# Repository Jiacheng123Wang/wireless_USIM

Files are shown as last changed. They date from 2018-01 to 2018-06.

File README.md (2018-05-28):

# wireless_USIM
Wireless USIM interface software &amp; hardware. The basic functionality is to implement USIM sharing between multiple cellular devices by wireless interface. Especially between smart phone and watch. For more information, refer doc/Wireless_SIM_Interface.pptx.

Based on nRF52832-CIAA Multi-protocol 2.4GHz SoC.

nRF-SDK 14.2.0 required, download from https://developer.nordicsemi.com/nRF5_SDK/nRF5_SDK_v14.x.x/

Toolchain gcc-arm-none-eabi-5_4-2016q3 used, download from https://launchpad.net/gcc-arm-embedded/+download

Hardware PCB is generated by DesignSpark 8.1, download from https://www.rs-online.com/designspark/pcb-software

Smart SIM connector 3D IGS is generated from rsdoc file by DesignSpark Mechanical 2.0, download from https://www.rs-online.com/designspark/mechanical-software

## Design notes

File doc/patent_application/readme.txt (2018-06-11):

The patent application documents just for better understanding the background of wireless USIM interface.

The patent process has been quit for all applications.

All the patent documents are open technology.

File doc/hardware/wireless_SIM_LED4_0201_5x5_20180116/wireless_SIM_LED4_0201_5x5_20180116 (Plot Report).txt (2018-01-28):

Plot Report
-----------

Report Written:     Tuesday, January 16, 2018
Design Path:        \\Mac\Home\Desktop\PCB\wireless_SIM_LED4_0201_5x5_20180116.pcb
Design Title:       
Created:            2015/5/19 15:26:34
Last Saved:         2018/1/16 21:34:01
Editing Time:       20650 min
Units:              mm (precision 4)

Device Settings
===============

Gerber Settings
===============

    Leading zero suppression.
    G01 assumed throughout.
    Line termination <*> <CR> <LF>.
    3.5 format absolute inches.

    Format commands defined in Gerber file.
    Aperture table defined in Gerber file.
    Hardware arcs allowed.

Drill Settings
==============

    Excellon Format 1    Format 3.5 absolute in mm.
    No zero suppression.

Plots Output
============

Gerber Output
=============

\\Mac\Home\Desktop\PCB\wireless_SIM_LED4_0201_5x5_20180116 - Top Documentation.gbr

    Layers:
    ---------------------
    Top Documentation
    Board Outlines

    D-Code Shape  (thou)
    -----------------------
    D10    Round 0.39
    D11    Round 0.04
    D12    Round 1.57
    D14    Round 0.79

Gerber Output
=============

\\Mac\Home\Desktop\PCB\wireless_SIM_LED4_0201_5x5_20180116 - Top Silkscreen.gbr

    Layers:
    ------------------
    Top Silkscreen
    Board Outlines

    D-Code Shape  (thou)
    -----------------------
    D11    Round 0.04
    D12    Round 1.57
    D13    Round 1.18
    D14    Round 0.79

Gerber Output
=============

\\Mac\Home\Desktop\PCB\wireless_SIM_LED4_0201_5x5_20180116 - Top Copper.gbr

    Layers:
    ------------------
    Top Copper
    Board Outlines

    D-Code Shape  (thou)
    --------------------------------------------------------------
    D11    Round 0.04
    D14    Round 0.79
    D16    Round 78.74
    D18    Round 39.37
    D70    Round 19.69
    D71    Square 11.81
    D21    Round 8.66
    D23    Round 15.75
    D24    Round 5.91
    D25    Round 7.87
    D93    Round 3.94
    D96    Square 19.69
    D100   Round 27.56
    D113   Round 47.24
    D115   Round 11.81
    D116   Round 2.36
    D120   Rounded Rectangle 39.37 X 62.99 X 15.75  Rotation 90
    D123   Rectangle 51.18 X 62.99
    D126   Rounded Rectangle 39.37 X 70.87 X 15.75  Rotation 90

Gerber Output
=============

\\Mac\Home\Desktop\PCB\wireless_SIM_LED4_0201_5x5_20180116 - Top Copper (Resist).gbr

    Layers:
    ------------------
    Top Copper
    Board Outlines

    D-Code Shape  (thou)
    --------------------------------------------------------------
    D11    Round 0.04
    D14    Round 0.79
    D26    Round 88.74
    D28    Round 49.37
    D72    Round 29.69
    D73    Square 21.81
    D75    Round 18.66
    D101   Square 29.69
    D121   Rounded Rectangle 39.37 X 62.99 X 15.75  Rotation 90
    D124   Rectangle 61.18 X 72.99
    D127   Rounded Rectangle 39.37 X 70.87 X 15.75  Rotation 90

Gerber Output
=============

\\Mac\Home\Desktop\PCB\wireless_SIM_LED4_0201_5x5_20180116 - Top Copper (Paste).gbr

    Layers:
    ------------------
    Top Copper
    Board Outlines

    D-Code Shape  (thou)
    --------------------------------------------------------------
    D11    Round 0.04
    D14    Round 0.79
    D77    Round 74.74
    D79    Round 35.37
    D81    Round 15.69
    D82    Square 7.81
    D84    Round 4.66
    D105   Square 15.69
    D122   Rounded Rectangle 39.37 X 62.99 X 15.75  Rotation 90
    D125   Rectangle 47.18 X 58.99
    D128   Rounded Rectangle 39.37 X 70.87 X 15.75  Rotation 90

Gerber Output
=============

\\Mac\Home\Desktop\PCB\wireless_SIM_LED4_0201_5x5_20180116 - Bottom Copper.gbr

    Layers:
    ------------------
    Bottom Copper
    Board Outlines

    D-Code Shape  (thou)
    ---------------------------------------------------------------
    D11    Round 0.04
    D14    Round 0.79
    D23    Round 15.75
    D25    Round 7.87
    D86    Rounded Rectangle 70.87 X 165.35 X 19.69  Rotation 90
    D100   Round 27.56
    D113   Round 47.24
    D115   Round 11.81

Gerber Output
=============

\\Mac\Home\Desktop\PCB\wireless_SIM_LED4_0201_5x5_20180116 - Bottom Copper (Resist).gbr

    Layers:
    ------------------
    Bottom Copper
    Board Outlines

    D-Code Shape  (thou)
    ---------------------------------------------------------------
    D11    Round 0.04
    D14    Round 0.79
    D87    Rounded Rectangle 70.87 X 165.35 X 19.69  Rotation 90

Gerber Output
=============

\\Mac\Home\Desktop\PCB\wireless_SIM_LED4_0201_5x5_20180116 - Bottom Copper (Paste).gbr

    Layers:
    ------------------
    Bottom Copper
    Board Outlines

    D-Code Shape  (thou)
    ---------------------------------------------------------------
    D11    Round 0.04
    D14    Round 0.79
    D88    Rounded Rectangle 70.87 X 165.35 X 19.69  Rotation 90

Gerber Output
=============

\\Mac\Home\Desktop\PCB\wireless_SIM_LED4_0201_5x5_20180116 - Bottom Silkscreen.gbr

    Layers:
    ---------------------
    Bottom Silkscreen
    Board Outlines

    D-Code Shape  (thou)
    -----------------------
    D11    Round 0.04
    D12    Round 1.57
    D14    Round 0.79

Gerber Output
=============

\\Mac\Home\Desktop\PCB\wireless_SIM_LED4_0201_5x5_20180116 - Bottom Documentation.gbr

    Layers:
    ------------------------
    Bottom Documentation
    Board Outlines

    D-Code Shape  (thou)
    -----------------------
    D10    Round 0.39
    D11    Round 0.04
    D12    Round 1.57
    D14    Round 0.79

NC Drill Output
===============

\\Mac\Home\Desktop\PCB\wireless_SIM_LED4_0201_5x5_20180116 - Drill Data - [Through Hole].drl

    Output:
    ---------------------------
    Plated Round Drill Holes
    Plated Slots
    Plated Board Outlines

    Tool  Size         Count   ID
    ------------------------------------
    T001  000.00591 in 10    F
    T002  000.00787 in 1320  A
    T003  000.01969 in 325   D
    T004  000.03937 in 20    E
    ------------------------------------
    Total              1675
    ------------------------------------

\\Mac\Home\Desktop\PCB\wireless_SIM_LED4_0201_5x5_20180116 - Drill Data - [Through Hole] (Unplated).drl

    Output:
    -----------------------------
    Unplated Round Drill Holes
    Unplated Slots
    Unplated Board Outlines

    Tool  Size         Count   ID
    ------------------------------------
    T001  000.02500 in 26
    ------------------------------------
    Total              26
    ------------------------------------

End Of Report.

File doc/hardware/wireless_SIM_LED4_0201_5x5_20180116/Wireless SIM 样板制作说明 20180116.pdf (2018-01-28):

# Wireless SIM 样板制作说明

# 电路板模型示意图

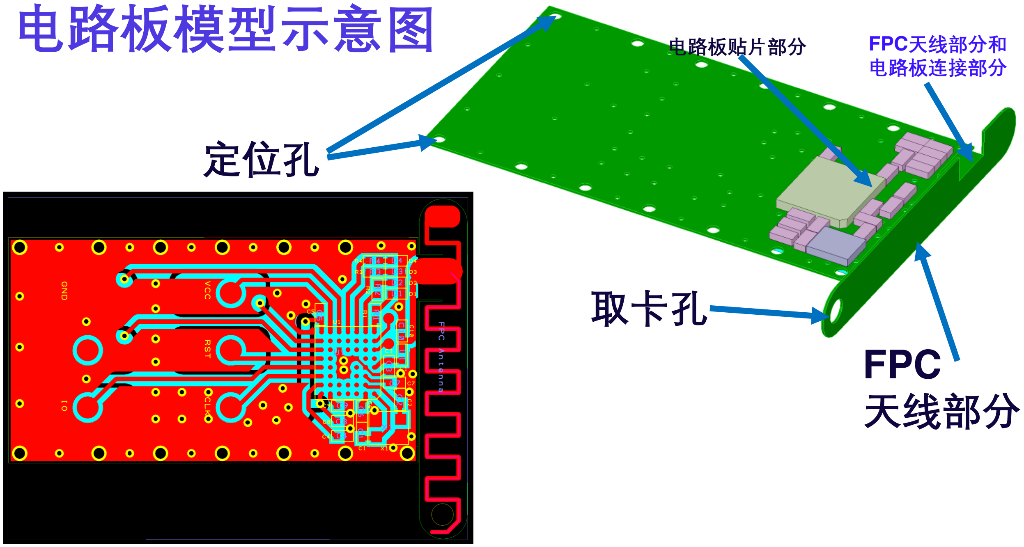
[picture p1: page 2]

### 定位孔

### 取卡孔

### FPC

### 天线部分

FPC天线部分和
电路板连接部分

电路板贴片部分

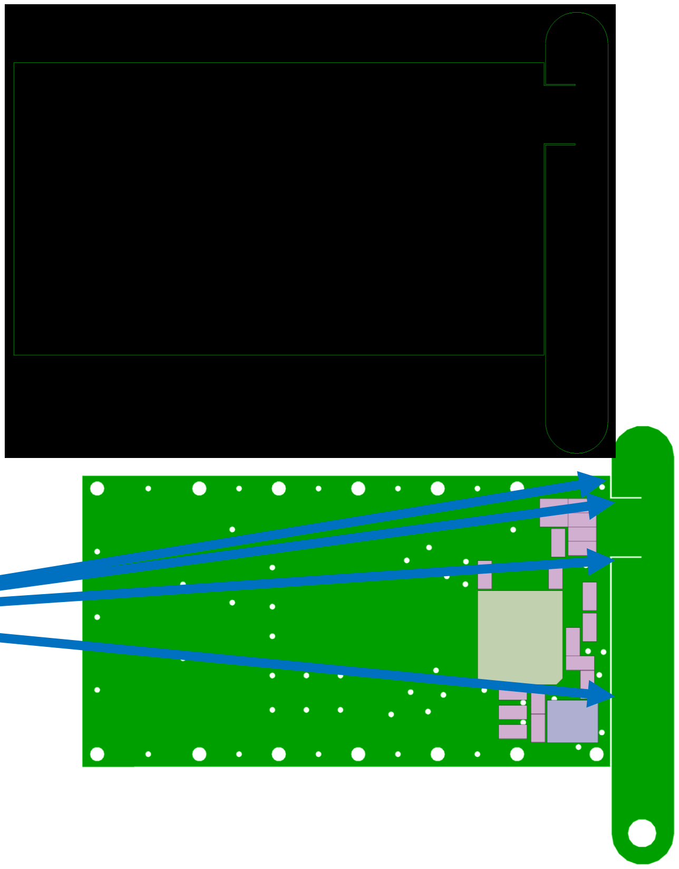
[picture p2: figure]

# FPC天线板切割线(1)

- FPC天线最后需要折叠弯
曲，固定在定制的SIM卡
托上。天线FPC垂直于原
来的电路板，竖直固定
在SIM卡托的外侧
- 在切割FPC板外形的时候，
天线FPC板和主电路板之
间的分离距离是0.05mm，
实际上只需要切割一条线
分开就可以了

# FPC天线板切割线(2)

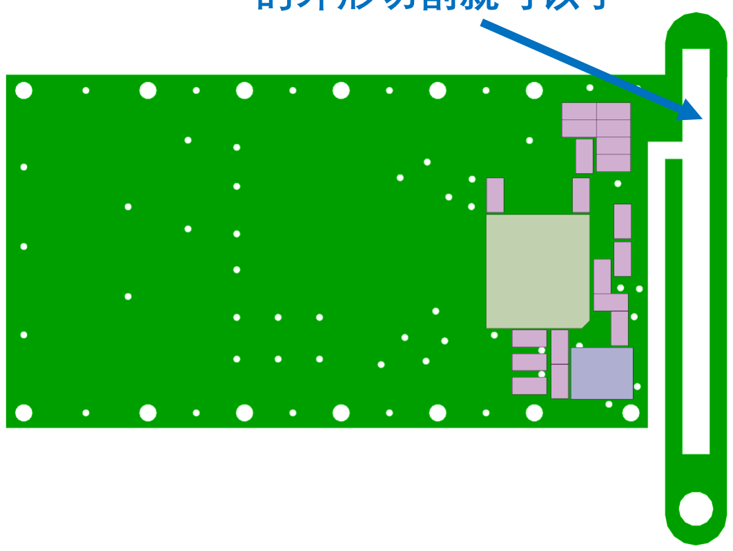
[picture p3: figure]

- 另外一个FPC天线最
后需要折叠弯曲，
固定在定制的SIM卡
托的内侧，按照电
路板的外形切割就
可以了。

FPC天线子板按照电路板
的外形切割就可以了

## FPC天线固定在定制卡托上的效果

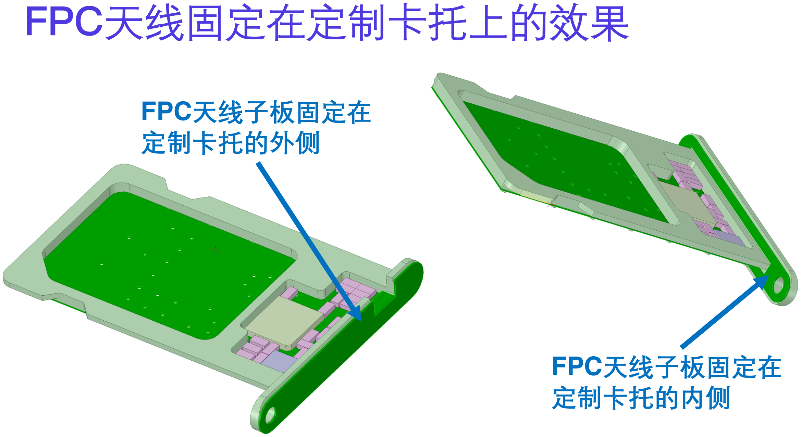
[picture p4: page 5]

FPC天线子板固定在
定制卡托的外侧

FPC天线子板固定在
定制卡托的内侧

## 定位孔

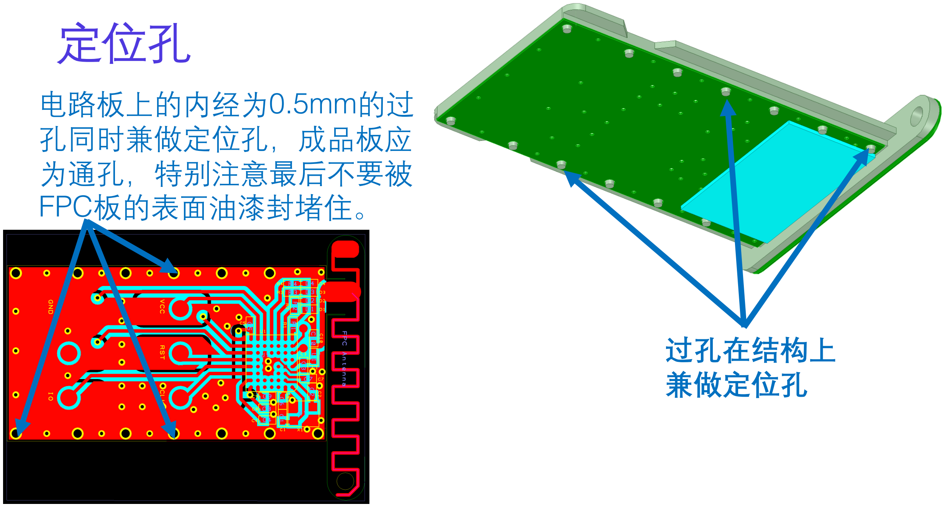
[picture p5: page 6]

电路板上的内经为0.5mm的过
孔同时兼做定位孔，成品板应
为通孔，特别注意最后不要被
FPC板的表面油漆封堵住。

过孔在结构上
兼做定位孔

## 取卡孔

### 取卡孔在成品

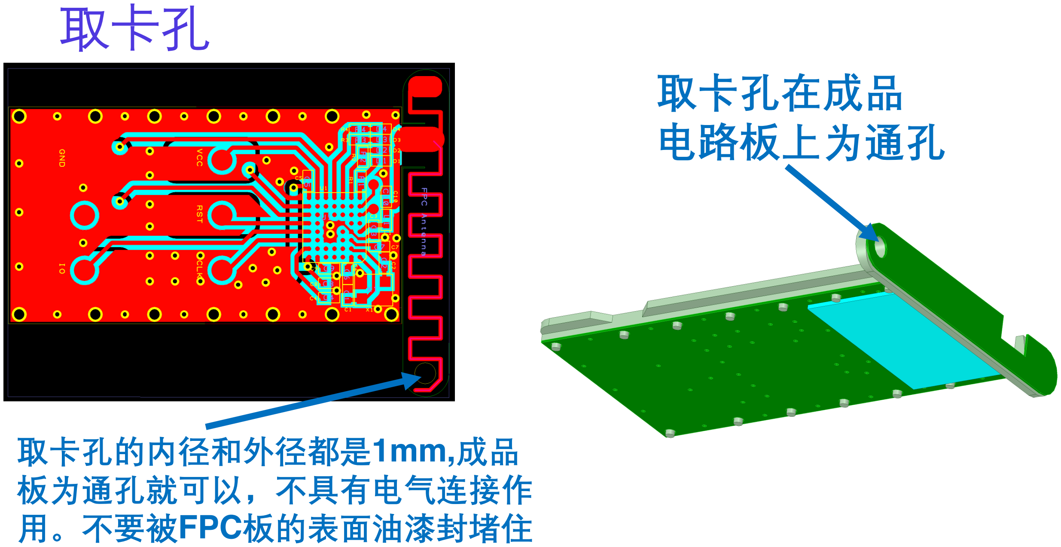
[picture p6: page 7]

取卡孔的内径和外径都是1mm,成品
板为通孔就可以，不具有电气连接作
用。不要被FPC板的表面油漆封堵住

### 电路板上为通孔

## 结构加强板(1)

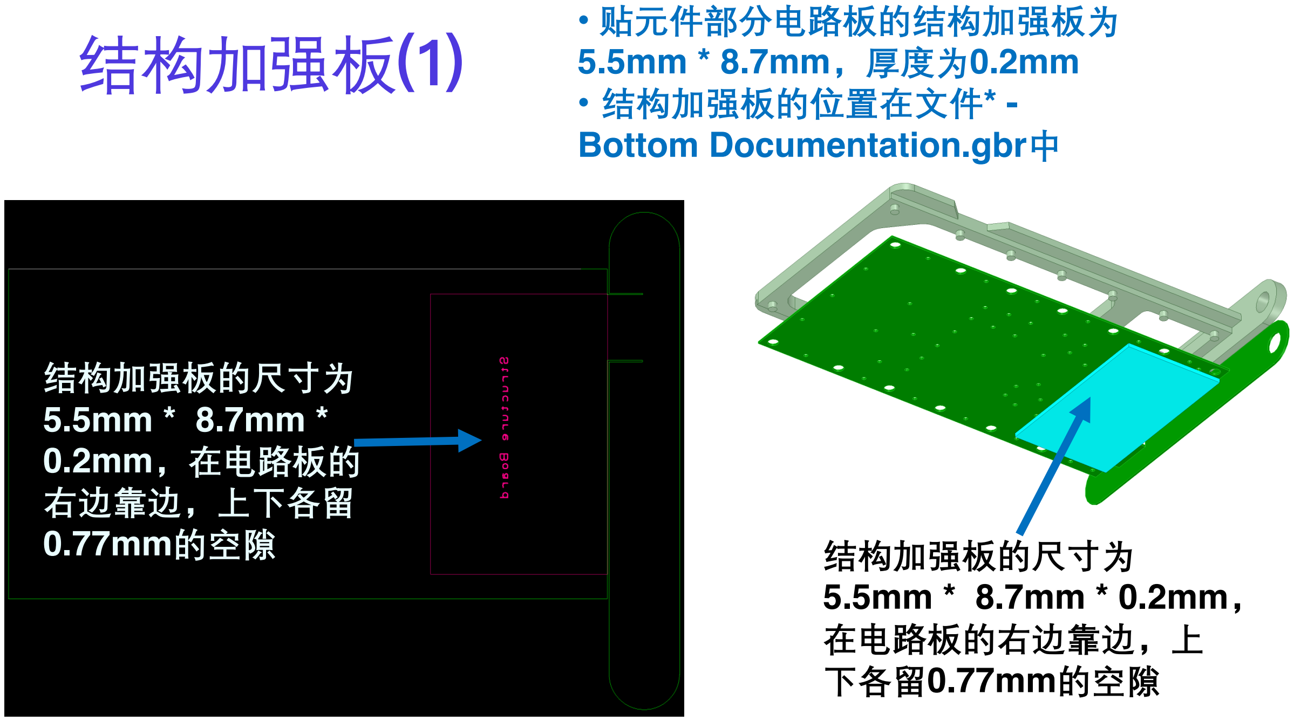
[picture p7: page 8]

- 贴元件部分电路板的结构加强板为
5.5mm * 8.7mm，厚度为0.2mm
- 结构加强板的位置在文件* -
Bottom Documentation.gbr中

结构加强板的尺寸为
5.5mm * 8.7mm *
0.2mm，在电路板的
右边靠边，上下各留
0.77mm的空隙 | 结构加强板的尺寸为
| 5.5mm * 8.7mm * 0.2mm， 在电路板的右边靠边，上
| 下各留0.77mm的空隙

## 结构加强板(2)

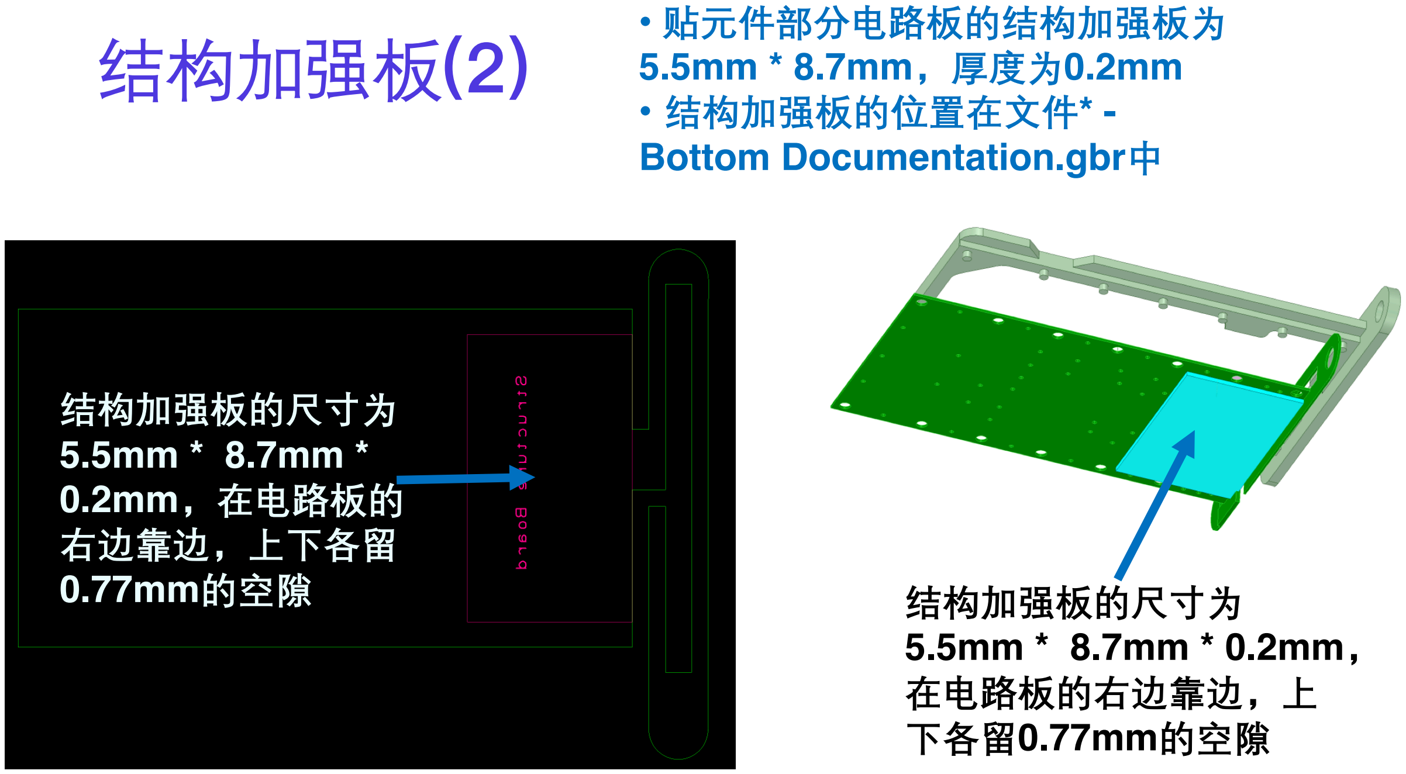
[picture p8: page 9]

- 贴元件部分电路板的结构加强板为
5.5mm * 8.7mm，厚度为0.2mm
- 结构加强板的位置在文件* -
Bottom Documentation.gbr中

结构加强板的尺寸为
5.5mm * 8.7mm *
0.2mm，在电路板的
右边靠边，上下各留
0.77mm的空隙 | 结构加强板的尺寸为
| 5.5mm * 8.7mm * 0.2mm， 在电路板的右边靠边，上
| 下各留0.77mm的空隙

## 其它事项

## - 由于电路板比较小，位置丝印和文字丝 印都不要印上

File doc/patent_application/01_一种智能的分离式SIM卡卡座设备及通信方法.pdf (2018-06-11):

(10)申请公布号 CN 104184857 A
(43)申请公布日 2014.12.03

C

N 104184857 A

(21)申请号 201410452312.6

(22)申请日 2014.09.09

H04M 1/02 (2006.01)
H04W 76/02 (2009.01)

(71)申请人 王家城
地址 100192 北京市朝阳区林萃西里 26 号
楼 6 单元 602

(72)发明人 王家城

(54) 发明名称
一种智能的分离式 SIM 卡卡座设备及通信方
法
(57) 摘要
本发明属于通信终端设备领域。本发明提供
一种用于连接移动通信终端设备 ( 简称手机 ) 和
用户身份模块卡 ( 简称 SIM 卡 ) 的智能设备。包 括 ：1).该设备可用于取代现有手机中的SIM卡卡
座功能。SIM 卡插于该设备中，手机与 SIM 卡的通 信由该设备转发完成。转发通信可以是有线或者
无线通信。2). 该设备具有智能性。具有独立的
通信模块，人机界面和能源供应，使得该设备能够
独立于手机向用户提供通信服务。3). 该设备可
以被用户佩戴而和用户随时同在，提高设备的安
全性，并为 SIM 卡的各种应用提供用户交互，包括
移动金融，移动商务，身份认证等。4). 基本型该
设备可以只具备 SIM 卡数据的无线转发功能。

(51)Int.Cl.

权利要求书 3 页 说明书 12 页 附图 2 页

(19)中华人民共和国国家知识产权局

## (12)发明专利申请

权利要求书3页 说明书12页 附图2页

(10)申请公布号 CN 104184857 A

CN 104184857 A

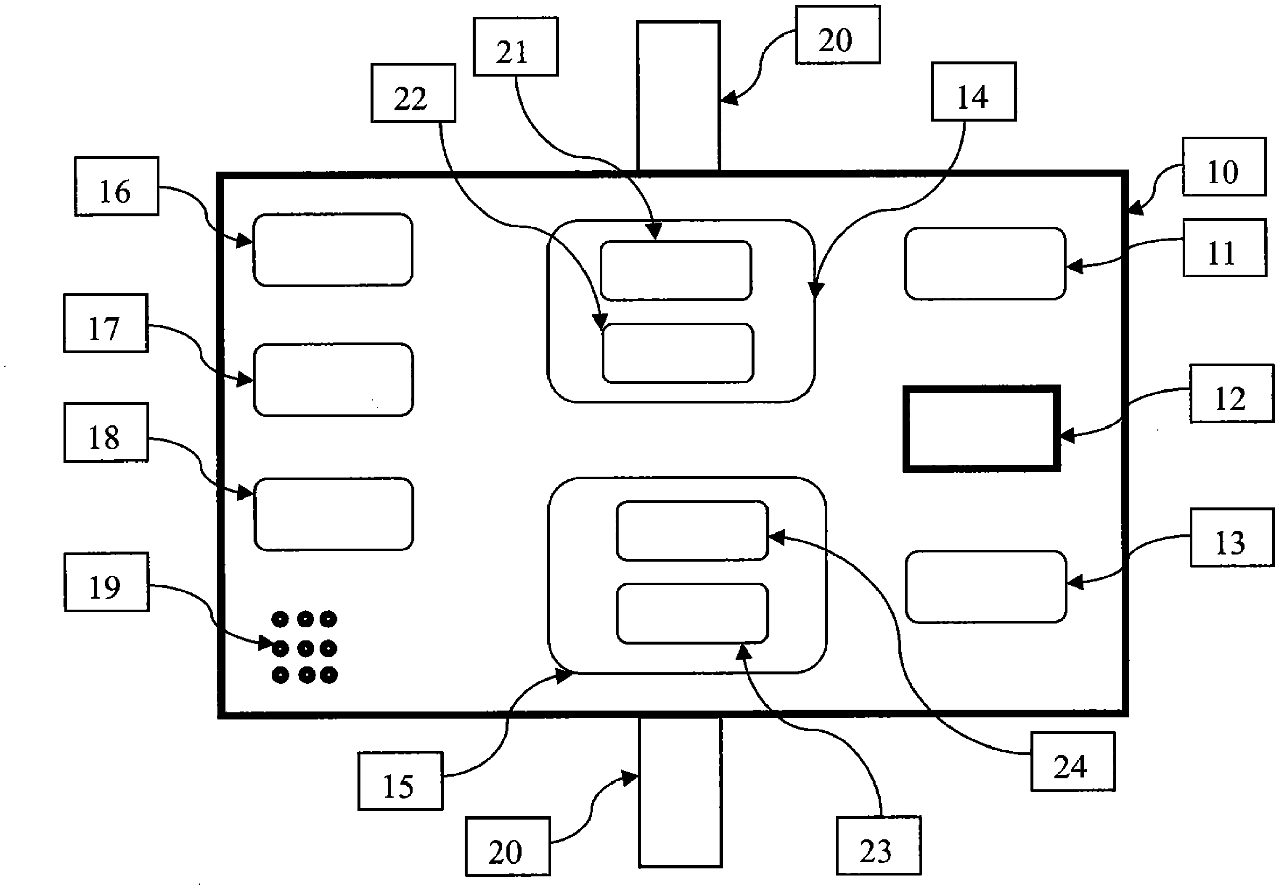
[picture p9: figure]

1/3 页

1. 一种连接通信终端设备和用户身份模块卡的智能设备和通信方法，其特征在于 ：所 述智能设备提供通信连接和方法来完成通信终端设备和用户身份模块卡之间的所有数据 交换。
2. 根据权利要求 1 所述的智能设备，其特征在于 ：上述智能设备具有如下模块 ：
1) 和用户身份模块卡之间的接触式电路连接模块，包括 ：
a) 电源电压 (VCC) 电路，
b) 编程电压 (VPP) 电路，
c) 零线 (GND) 电路，
d) 时钟 (CLK) 电路，
e) 数据通信 (IO，DATA) 电路，
f) 重置 (RST) 电路，
其中，编程电压 (VPP) 电路是可选的，
2) 连接通信终端设备和用户身份模块卡进行数据交换的通信模块和控制模块，
3) 人机交互模块，
4) 能源供应模块。
3. 根据权利要求 2 所述的智能设备，其特征在于 ：上述智能设备还包括和移动通信网 络进行连接的无线通信模块。
4. 根据权利要求 2 所述的连接通信终端设备和用户身份模块卡进行数据交换的通信 模块，其特征在于 ：上述通信模块是无线蓝牙通信 (Bluetooth) 模块。
5. 根据权利要求 2 所述的连接通信终端设备和用户身份模块卡进行数据交换的通信 模块，其特征在于 ：上述通信模块是无线局域网 (WLAN，WiFi) 模块。
6. 根据权利要求 2 所述的连接通信终端设备和用户身份模块卡进行数据交换的通信 模块，其特征在于 ：上述通信模块是直接电路连接用户身份模块卡的通信引脚，包括 ：
1) 电源电压 (VCC) 电路，
2) 编程电压 (VPP) 电路，
3) 零线 (GND) 电路，
4) 时钟 (CLK) 电路，
5) 数据通信 (IO，DATA) 电路，
6) 重置 (RST) 电路，
其中，编程电压 (VPP) 电路是可选的。
7. 根据权利要求 2 所述的连接通信终端设备和用户身份模块卡进行数据交换的控制 模块，其特征在于 ：上述控制模块通过额外的安全控制如密码验证，身份认证，加密通信等 来加强通信终端设备和用户身份模块卡之间数据交换的安全性。
8. 根据权利要求 2 所述的连接通信终端设备和用户身份模块卡进行数据交换的控制 模块，其特征在于 ：上述控制模块的功能在于 ：
1) 建立用户身份模块卡和如权利要求 3 所述的智能设备之间的通信连接，使得它们两 个设备一起组成一个完整的移动用户设备，
2) 建立用户身份模块卡通过如权利要求 1 所述的智能设备连接而和通信终端设备之 间的通信连接，使得它们三个设备一起组成一个完整的移动用户设备，
CN 104184857 A | 权 利 要 求 书

2/3 页

3) 断开用户身份模块卡和如权利要求 1 所述的智能设备之间的通信连接，
4) 断开用户身份模块卡通过如权利要求 1 所述的智能设备连接而和通信终端设备之 间的通信连接。
9. 一种通信终端设备，其特征在于 ：所述的通信终端设备包括有功能模块，该功能模 块配合如权利要求 1 所述的智能设备和通信方法来完成该通信终端设备和用户身份模块 卡之间的所有数据交换并提供控制这种通信的人机界面。
10. 一种用于通信终端设备接入移动通信网络的方法和流程，其特征在于 ：所述方法 和流程是在如根据权利要求 3 所述的智能设备和如根据权利要求 9 所述的通信终端设备 的功能模块的协助下完成的，它们之间具有有效的蓝牙通信连接，通信终端设备根据所述 方法和流程完成移动网络接入后，为用户提供移动通信服务，所述方法和流程包括如下步 骤 ：
1) 如根据权利要求 3 所述的智能设备和用户身份模块卡组成移动用户设备，为用户提 供移动通信服务，
2) 通信终端设备和如根据权利要求 3 所述的智能设备在有效蓝牙通信连接的范围内， 它们之间通过蓝牙建立起通信连接，
3) 如根据权利要求 2 所述的连接通信终端设备和用户身份模块卡进行数据交换的控 制模块检测到通信终端设备的存在，
4) 如根据权利要求 2 所述的人机交互模块提示用户，是否要建立用户身份模块卡和通 信终端设备之间的通信连接，得到用户的确认后继续如下过程，否则中断建立用户身份模 块卡和通信终端设备之间的通信连接 ( 或者根据预先的设置，省略此步骤 )，
5) 通过如根据权利要求 3 所述的智能设备和通信终端设备之间的蓝牙通信连接，进行 消息交互，完成用户身份模块卡和通信终端设备之间的安全验证，身份认证等过程 ( 或者 根据预先的设置，省略此步骤 )，
6) 通过如根据权利要求 3 所述的智能设备和通信终端设备之间的消息交互，确定主控 制端，以下步骤假定通信终端设备为主控制端，并且所有的步骤都是在主控制端的控制下 完成的，
7) 如根据权利要求 3 所述的智能设备断开和移动通信网络的连接，并进一步关闭如根 据权利要求 3 所述的和移动网络进行通信的通信模块和其它一些不需要的应用模块的电 源供应，使得如根据权利要求 3 所述的智能设备处于低功率的节能运行状态，
8) 通信终端设备通过相应的功能模块检测到用户身份模块卡，进而建立它和用户身份 模块卡之间的连接，
9) 通信终端设备通过蓝牙通信连接，向如根据权利要求 3 所述的智能设备发出请求， 读取存储在用户身份模块卡的 IMSI( 国际用户识别码 ) 和 TMSI( 临时用户号 )，
10) 如根据权利要求 3 所述的智能设备收到来自通信终端设备的读取请求后，读取 IMSI 和 TMSI，
11) 如根据权利要求 3 所述的智能设备通过蓝牙通信连接把 IMSI 和 TMSI 发送给通信 终端设备，
12) 通信终端设备收到 IMSI 和 TMSI 后，把 IMSI 和 TMSI 发送给移动通信网络，
13) 移动通信网络判断收到的该 IMSI 和 TMSI，如有效，则生成一个 RAND 码 ( 随机数序
CN 104184857 A | 权 利 要 求 书

3/3 页

列 )，然后发回给通信终端设备，
14) 通信终端设备收到 RAND 码后，通过蓝牙通信连接，把 RAND 码发给如根据权利要求 3 所述的智能设备，并请求“RUN GSM ALGORITHM”( 生成鉴权码和加密密码的 A3A8 算法 ) 的户身份模块卡内部命令，
15) 如根据权利要求 3 所述的智能设备收到 RAND 码后，把 RAND 码发给用户身份模块 卡，并向用户身份模块卡发出“RUN GSM ALGORITHM”的命令，
16) 用户身份模块卡以内部的 Ki 为密钥，以 RAND 码为输入，运行 RUN GSM ALGORITHM” 命令，生成鉴权码 SRES 和加密密码 Kc，
17) 如根据权利要求 3 所述的智能设备读取用户身份模块卡生成的 SRES 和 Kc，
18) 如根据权利要求 3 所述的智能设备通过蓝牙通信连接把 SRES 和 Kc 发送给通信终 端设备，
19) 通信终端设备收到 SRES 和 Kc 后，把 SRES 发送给移动通信网络，
20) 移动通信网络收到 SRES 后，自己运行一次 A3A8 算法得到自己的 SRES，与通信终端 设备返回的 SRES 进行对比，若一致，则完成用户认证过程，该用户为合法用户，
21) 通信终端设备完成其它的移动通信网络接入过程，为用户提供移动通信服务，
22) 通信终端设备通过如根据权利要求 9 所述的人机界面通知用户，用户身份模块卡 和通信终端设备处于连接状态，可以为用户提供移动通信服务，
23) 如根据权利要求 3 所述的智能设备通过如根据权利要求 2 所述的人机交互模块通 知用户，该智能设备和移动通信网络处于断开状态，它和移动通信网络的通信需要通信终 端设备转发，
24) 在以后的通信终端设备和用户身份模块卡的通信连接持续过程中，当通信终端设 备需要用户身份模块卡的有关数据时，都通过蓝牙通信连接向如根据权利要求 3 所述的智 能设备发出请求，在如根据权利要求 3 所述的智能设备的协助下获得用户身份模块卡的相 关数据。
CN 104184857 A | 权 利 要 求 书

1/12 页

一种智能的分离式 SIM 卡卡座设备及通信方法

技术领域
[0001] 本发明属于通信终端设备领域。具体地说，本发明涉及一种适用于通信终端设备 和用户身份模块卡的通信连接设备，同时，也涉及适用于该设备与移动通信终端设备的通 信方法。

背景技术
[0002] 目前，移动通信用户设备主要由通信终端设备和用户身份模块卡两个组成部分。 其中通信终端设备具有通信的基本功能 ( 包括手机，移动固话，平板电脑，笔记本电脑，台 式电脑，智能家居设备如智能电视，家庭媒体中心如机顶盒，家庭网络中心如路由器。为简 便，以下都一律简称手机 )。并且随着技术的进步，手机向着智能化方向发展，成为智能手 机，即用户可以安装应用程序来完成各种不同的应用功能。而用户身份模块卡 ( 包括 GSM 系统的 SIM 卡，CDMA 系统的 UIM 卡，2G，3G 和 4G 系统的 USIM 卡。为简便，以下都一律简称 SIM 卡 ) 主要用于在安全的条件下完成用户身份鉴权和用户信息加密算法的全过程，并且 还可以完成对网络的认证，可以防止冒充的虚假网络，保护用户的通信安全。用户身份模块 卡还可以用于安全地存储用户的基本数据，如电话号码和短消息内容等。这样的设计兼顾 了通信的安全性和用户的使用方便性。其中通信安全性主要是通过只共享于通信网络和用 户身份模块卡之间的密码算法和加密密钥来实现的，任何第三方包括手机本身都无法得到 这些信息。而数据安全性是通过存储在用户身份模块卡上数据的访问控制来实现的，包括 用户 PIN 码和 PUK 码，还包括只能由移动通信网络营运商访问的数据。另一方面，符合标准 的任何一个 SIM 卡可以插入任何一个手机进行通信，用户的身份标识 ( 包括 IMSI( 唯一的 国际用户识别号 ) 和手机号码等 ) 只存在于 SIM 卡中，并且通信的账单都记录在此用户的 身份标识下，而与使用的手机无关。这样极大地方便了用户对手机的使用。
[0003] 在现有的技术实现中，手机有一个固定在其内的 SIM 卡卡座，卡座上有六个引脚， 使得 SIM 卡插入卡座后通过该引脚和 SIM 卡进行接触通信，具体的通信协议在有关的标准 中定义 ( 如 ISO-7816，ETSI GSM 11.11 等 )。这种通信是一种有线通信形式。
[0004] 随着手机在人们的生活和工作中变得越来越重要，人们通过手机完成更多的任 务。除了用于基本的语音通话和文字消息外，还有如观看视频，浏览照片，浏览网页等，这些 应用需要更大的屏幕来提供更好的用户体验。这样，手机的体积就变得越来越大，例如市场 已经有一些产品称为平板手机 ( 其屏幕一般是五到七英寸 )，具有平板电脑一样的大屏幕 和手机的通信功能。手机作为移动通信设备，对其便携性的要求也越来越高，需要和用户随 时同在。有的应用场景对用户来说，随身携带一个大体积的手机就不方便，需要另外一个背 包或挎包来携带手机，如夏天出行的时候。而有的时候携带另外一个背包或挎包也不方便， 如跑步等锻炼身体的时候。这就使得手机的便携性和大体积成为一对矛盾，不能满足人们 不同应用场景的需求。
[0005] 为了满足手机的小体积和便携性，现有市场上出现了一种手表式手机，这种缩小 版的手机很好地满足了人们的便携性需求。然而，这种缩小版的手机由于安装了各种应用
CN 104184857 A | 说 明 书

程序而具有手机的全部功能，人们需要使用的时候就很多，使得小体积的电池使用时间变 短。当用户有更为紧急的通信需求时，由于电池耗尽而无法使用手机。另一方面，由于屏幕 小，除了上面提到的观看视频，浏览照片，浏览网页等手机应用的用户体验差之外，作为用 户界面的用户手指输入 ( 触摸屏设备 )，非常容易出现输入错误，而多次改正错误的输入使 得用户体验变得极差。这样，小体积的手表式手机的便携性和友好的人机交互界面以及电 池的续航能力成为一对矛盾，也不能满足人们不同应用场景的需求。
[0006] 有的用户同时拥有大体积的大屏幕手机和小体积的手表式手机两种设备，以满足 不同的应用场景的需求。然而，由于这两种设备互相独立的，用户就得使用两个不同的 SIM 卡完成通信服务。这样用户就不得不有两个用户标识如手机号等，在通信中造成不方便。 有些应用需要唯一的用户身份标识，用户就不得不从两个中挑选一个作为唯一的用户身份 标识。这样当用户使用另外一个 SIM 卡的手机时，错过了需要该唯一的用户身份标识的通 信。然而这些通信通常是重要的，如银行的信用卡消费通知短信和移动支付的 I 临时密码 等等。同时携带两个设备又失去了便携性的初衷，或者在两个手机之间插拔同一个 SIM 卡 除了短暂的通信中断外，又是另一种的使用不方便。移动通信网络服务提供商提供一种呼 叫转移服务，提供一种有限的合并两个 SIM 卡的通信服务，但这需要用户另外的付费，并且 有些通信是不能合并的或者不提供合并通信服务。在两个 SIM 卡之间不断地互相设置呼叫 转移又另外给用户带来新的使用不方便。总之，同时拥有两个手机和 SIM 卡也有诸多矛盾， 不能满足人们不同应用场景的需求。
[0007] 本发明的核心功能就是提供一种设备和方法，方便地满足人们不同的应用场景的 需求。该设备相对于通常的手机来说，它是一个 SIM 卡的卡座，但不是固定于手机内部的 卡座，而是分离式的，方便于随身携带 ( 如腕表式携带等 )。并且该设备提供一种或多种手 机和 SIM 卡之间的通信，包括有线和无线通信，也包括直接的电路信号的连接通信和间接 的通信协议消息和数据的转发。同时该设备相对于 SIM 卡来说，它是一个手机，是一个智能 型的 SIM 卡卡座。具有独立的连接于外部移动通信网络的通信模块，人机界面和能源供应 ( 如电池等 )，能够和 SIM 卡一起组成移动用户设备，独立于手机向用户提供通信服务，如 语音通话，短消息收发和必要的基于 TCP/IP 协议的网络连接服务。当然，本发明的智能设 备作为相对于 SIM 卡来说是一个手机的功能是可选功能，为了更方便地向用户提供通信服 务。本发明的智能设备的核心功能是作为一个智能型的 SIM 卡卡座，提供手机和 SIM 卡之 间的各种方便的通信连接，而不是局限于通过引脚进行的接触式通信。
[0008] 另一方面，作为智能型设备，本发明的智能型 SIM 卡卡座可以基于现有的技术，安 装各种不同的应用，为用户提供各种应用服务。同时，作为随身携带的可穿戴式设备，本发 明的智能型 SIM 卡卡座可以集成一些基于现有技术和将来的新技术的功能模块，如健康监 测，健身记录，移动商务，身份验证，移动金融等，为用户提供额外的增值功能。还有，由于设 计成可佩戴式，就和用户随时随地同在而不容易丢失，大大提高了设备的安全性，从而使得 用户的通信安全性和数据安全性得到很大的提高。

发明内容
[0009] 本发明的目的是提供一种新型的智能型 SIM 卡卡座设备，用于连接手机和 SIM 卡， 方便地满足人们在不同应用场景的应用需求。

[0010] 本发明的目的是通过以下的技术方案实现的 ：
[0011] 1.本发明的智能型SIM卡卡座设备提供通信连接和方法来完成手机和SIM卡之间 的一切通信。并且该智能型卡座设备也可以独立于手机，单独和 SIM 卡一起组成移动用户 设备，为用户提供通信服务如语音通话，消息收发和网络连接服务。还可以通过安装应用程 序为用户提供各种应用服务。
[0012] 2. 本发明的智能型 SIM 卡卡座设备的功能可以只提供连接和方法来完成手机和 SIM 卡之间的一切通信，并且是通过无线通信连接来完成手机和 SIM 卡之间的通信。
[0013] 3. 本发明在手机中有一个功能模块，配合智能型 SIM 卡卡座设备来完成手机和 SIM 卡之间的一切通信，并可以在功能模块中提供控制这种通信的人机界面。
[0014] 4. 本发明的智能型 SIM 卡卡座设备具有如下模块 ：
[0015] 1) 和 SIM 卡之间的通信模块。
[0016] 2)SIM 卡的读写模块。
[0017] 3) 连接手机与 SIM 卡有关通信的通信模块。
[0018] 4) 涉及 SIM 卡有关通信的控制模块。
[0019] 5) 和外部通信网络进行通信的通信模块，如 2G 的 GSM 和 CDMA 移动通信模块，3G 的 WCDMA，CDMA2000 和 TD-SCDMA 移动通信模块，4G 的 FDD LTE 和 TD-LTE 移动通信模块
[0020] 6) 人机交互模块，提供用户和该设备交互的输入和输出功能。
[0021] 7) 电池模块或其它能源供应模块。
[0022] 8) 用于方便用户佩戴的其它配件。
[0023] 其中 1)，2)，3)，4) 是必选模块，5)，6)，7)，8) 是可选模块。
[0024] 5. 本发明的智能型 SIM 卡卡座设备提供的通信连接和方法包括通过步骤 ：
[0025] 1) 当收到来 SIM 卡的消息或者数据时，直接转发给手机。也可以解调消息或者数 据后，用另外一种通信协议重新封装后，再转发给手机。
[0026] 2) 当收到来自手机的消息或者数据时，直接转发给 SIM 卡。也可以解调消息或者 数据后，用另外一种通信协议重新封装后，再转发给 SIM 卡。
[0027] 6. 在本技术方案 4 条的 3) 子条所述的连接手机与 SIM 卡有关通信的通信模块中， 其具体实施技术方案可以是有线的通信方法如串口通信协议，USB 传输协议和基于 TCP/ IP 通信协议的局域网连接，也可以是无线的通信方法如蓝牙 (Bluetooth)，无线局域网 (WLAN，WiFi)，近场通信 (NFC)，Zigbee 通信，无线 USB(WUSB)，红外通信 (IrDA)。
[0028] 7. 在本技术方案 4 条的 3) 子条所述的连接手机与 SIM 卡有关通信的通信模块中， 可以用有线电路使得 SIM 卡的六个接触通信引脚和手机的相应通信引脚一一对应地连接。 这六个通信线路包括 ：
[0029] 1) 电源电压 (VCC) 电路。
[0030] 2) 编程电压 (VPP) 电路。
[0031] 3) 零线 (GND) 电路。
[0032] 4) 时钟 (CLK) 电路。
[0033] 5) 数据通信 (IO，DATA) 电路。
[0034] 6) 重置 (RST) 电路。
[0035] 其中 2) 编程电压 (VPP) 电路的连接是可选的，这种情况下只有五个有线连接电

路。
[0036] 9. 在本技术方案 4 条的 4) 子条所述的控制模块包括 ：
[0037] 1) 通信控制模块。
[0038] 2) 通信应用场景检测与判断模块。
[0039] 10. 在本技术方案 9 条的 1) 子条所述的通信控制模块中，包括如下功能 ：
[0040] 1) 建立 SIM 卡和本发明的智能型 SIM 卡卡座之间的通信，使得它们一起组成一个 完整的移动用户设备。在这种情况下，4 条的 5)，6)，7) 是必选模块。
[0041] 2) 建立 SIM 卡和手机之间的通信，这种通信是通过本发明的智能型 SIM 卡卡座连 接完成的，使得它们三个一起组成一个完整的移动用户设备。在这种情况下，4 条的 5)，6)， 7)，8) 是可选模块。但为了提供更好的用户服务和用户体验，通常 4 条的 6)，7) 模块会加入 本发明的智能型 SIM 卡卡座设备。
[0042] 3) 断开 SIM 卡和本发明的智能型 SIM 卡卡座之间的通信，用以预备建立 SIM 卡和 手机之间的通信。
[0043] 4) 断开 SIM 卡通过智能型 SIM 卡卡座建立的和手机之间的通信，用以预备建立 SIM 卡和另外的手机之间的通信，或者建立 SIM 卡和智能型 SIM 卡卡座之间的通信。
[0044] 11. 在本技术方案 10 条所述的通过智能型 SIM 卡卡座的连接建立 SIM 卡和手机之 间的通信过程中，可选地包括如下的安全验证步骤 ：
[0045] 1) 用户预先设定需要用户密码验证才能建立起 SIM 卡和手机之间的通信。
[0046] 2) 用户预先输入用户密码，并安全地存储于智能型 SIM 卡卡座设备中。
[0047] 3) 当每次试图建立 SIM 卡和手机之间的通信时，提示用户输入用户密码。
[0048] 4) 接收用户输入的密码。
[0049] 5) 比较用户输入的密码和预先设置的密码。
[0050] 6) 当用户输入的密码和预先设置的密码一致时，再继续建立 SIM 卡和手机之间的 通信。
[0051] 7) 当用户输入的密码和预先设置的密码不一致时，中断建立 SIM 卡和手机之间的 通信。
[0052] 12. 在本技术方案 10 条所述的通过智能型 SIM 卡卡座的连接建立 SIM 卡和手机之 间的通信过程中，可选地包括如下的身份验证步骤 ：
[0053] 1) 用户预先设定需要完成身份验证才能建立起 SIM 卡和手机之间的通信，这种身 份验证是基于它们的唯一身份标识符。
[0054] 2) 当试图建立 SIM 卡和手机之间的通信时，在智能型 SIM 卡卡座设备端提示用户 将要连接于 SIM 卡的手机唯一身份标识符如移动设备国际身份码 (IMEI) 或者 MAC 地址码， 得到用户的确认后，完成智能型 SIM 卡卡座设备端的身份验证。
[0055] 3) 同时在手机端提示用户将要连接的 SIM 卡唯一身份标识符如国际用户识别码 (IMSI)，得到用户的确认后，完成手机端的身份验证。
[0056] 4) 当手机端的身份验证和智能型 SIM 卡卡座设备端的身份验证都完成后，再继续 建立 SIM 卡和手机之间的通信。
[0057] 5) 当如上所述 2) 和 3) 任何一个身份验证步骤没有完成，中断建立 SIM 卡和手机 之间的通信。

[0058] 6) 可选地，当第一次完成如上所述 2) 和 3) 的身份验证步骤，并成功地建立 SIM 卡 和手机之间的通信后，手机和智能型 SIM 卡卡座设备各自安全地存储身份验证信息，在以 后的通信建立过程中，省略身份验证步骤。
[0059] 13.在本技术方案6条所述的连接手机与SIM卡的通信传输中，可选地使用加密通 信来加强它们之间的通信安全。
[0060] 14. 在本技术方案 9 条的 2) 子条所述的通信应用场景检测与判断模块中，包括如 下得功能 ：
[0061] 1)根据接收到的用户输入或者自动的判断，命令如9条的1)子条所述的通信控制 模块建立手机和 SIM 卡之间的通信连接。
[0062] 2)根据接收到的用户输入或者自动的判断，命令如9条的1)子条所述的通信控制 模块断开手机和 SIM 卡之间的通信连接。
[0063] 3)根据接收到的用户输入或者自动的判断，命令如9条的1)子条所述的通信控制 模块建立智能型 SIM 卡卡座和 SIM 卡之间的通信连接。
[0064] 4)根据接收到的用户输入或者自动的判断，命令如9条的1)子条所述的通信控制 模块断开智能型 SIM 卡卡座和 SIM 卡之间的通信连接。
[0065] 5) 根据用户的使用习惯，或者根据用户的预先设定而建立一个和 SIM 卡建立连接 的设备优先顺序列表。这个设备列表包括智能型 SIM 卡卡座和另外的一个或者多个手机。
[0066] 6) 根据如上 5) 条所述的设备优先顺序列表，命令如 9 条的 1) 子条所述的通信控 制模块来自动地建立 SIM 卡和设备优先列表中的设备的通信连接。首先建立和设备优先列 表中的第一个设备的通信连接，当通信连接建立失败时，再和列表中的第二个设备的建立 通信连接，以此类推，直到尝试完列表中的所有设备。
[0067] 7) 根据智能型 SIM 卡卡座收到从手机而来的无线通信信号的强度，建立一个和 SIM 卡建立通信连接的设备优先顺序列表，该列表用于维护 SIM 卡和手机之间的通信连接。
[0068] 8) 如果如上 5) 条和 7) 条所述的设备优先顺序列表中，当没有其它的手机可以用 于建立 SIM 卡和它们的通信连接时，则命令如 9 条的 1) 子条所述的通信控制模块继续维持 SIM 卡和智能型 SIM 卡卡座之间的通信连接。
[0069] 15.在本技术方案3条所述的手机功能模块中，包括一个可以容纳智能型SIM卡卡 座卡在其中的卡座，该卡座除出了提供有线的通信电路引脚外，还提供另外的引脚给智能 型 SIM 卡卡座进行电池充电。这个卡座和相应的通信电路引脚是可选模块，当使用无线通 信连接手机和 SIM 卡时，没有这个模块。
[0070] 16. 在本技术方案 4 条的 3) 和 4) 子条所述的通信模块和控制模块的功能实现中， 包括如下方法 ：
[0071] 1) 通过软件实现该通信功能和控制功能。
[0072] 2) 通过硬件实现该通信功能和控制功能。
[0073] 3) 通过软件和硬件的结合实现该通信功能和控制功能。
[0074] 17. 在本技术方案 4 条的 6) 子条所述的人机交互模块中，包括如下得一个或者多 个功能模块 ：
[0075] 1) 物理按键。
[0076] 2) 屏幕选择菜单

[0077] 3) 语音识别模块。
[0078] 通过这些功能模块单独地或者组合地应用，完成如下的控制功能 ：
[0079] 1) 命令本技术方案 9 条的 1) 子条所述的通信控制模块建立或者断开智能型 SIM 卡卡座设备和 SIM 卡之间的通信。
[0080] 2) 命令本技术方案 9 条的 1) 子条所述的通信控制模块建立或者断开手机和 SIM 卡之间的通信。
[0081] 18. 在本技术方案 9 条的 1) 子条所述的通信控制模块中，除了包括本技术方案 10 条所述的功能外，还包括如下功能 ：
[0082] 1) 在本技术方案 4 条的 6) 子条所述的人机交互模块中通知用户，当前的 SIM 卡连 接状态。即 SIM 卡是连接于手机，还是连接于智能型 SIM 卡卡座设备。
[0083] 2) 在本技术方案 3 条所述的手机功能模块所提供的人机界面中通知用户，当前的 SIM 卡连接状态。即 SIM 卡是连接于手机，还是连接于智能型 SIM 卡卡座设备。
[0084] 3) 通知用户的方式包括 ：
[0085] a) 振动提示。
[0086] b) 声音提示。
[0087] c) 屏幕文字消息提示。
[0088] d) 屏幕图标通知提示。
[0089] e) 指示灯的颜色提示。
[0090] f) 指示灯的闪烁提示。
[0091] 4) 可选地，以同样的方式通知用户，当前 SIM 卡的断开状态。
[0092] 19.在本技术方案3条所述的手机功能模块中的实现中，包括与在本技术方案4条 的 3) 和 4) 子条所述的通信模块和控制模块所相同的功能模块，功能实现和方法步骤，从而 在手机段实现相同的功能，使之可以检测，判断，控制 SIM 卡的通信连接，并确保通信连接 的安全。还可以通知用户当前的 SIM 卡连接和断开状态。
[0093] 20. 在本技术方案中手机端的功能控制模块和智能型 SIM 卡卡座端的功能控制模 块中，可以根据如下方式指定一个主控制模块，而另外的功能控制模块则为从控制模块 ：
[0094] 1) 根据用户预先设定主控制模块。
[0095] 2) 根据用户使用习惯或者其它规则自动地选定主控制模块。
[0096] 3) 根据用户预先设定的优先顺序规则，依次选定主控制模块。
[0097] 主控制模块可以独立地完成全部的检测，判断，控制和通知功能，也可以和从控制 模块一起共同完成这些功能。
[0098] 发明的效果
[0099] 1. 在本技术方案 4 条中的 1) 到 8) 模块组成一个完整的用户穿戴设备，和 SIM 卡 一起，就可以为用户提供随时随在的服务，很好地解决了移动通信用户设备的便携性。同 时，当有更大屏幕和更为友好的用户交互界面的手机时，就利用手机的这些优势，通过和手 机一起组成移动通信用户设备，提供更为完美的用户使用体验。从而很好地满足了用户在 不同应用场景的需求。由于本设备提供和手机的无线连接通信，这个切换过程是无缝的，对 用户来说是透明的，用户甚至不会觉察到这个切换过程，只关心终端设备的可达性和有效 性。同时，由于所有的通信都是通过同一个 SIM 卡，对移动通信网络服务提供商来说也是透

明的，移动通信网络服务提供商也无需知道用户在使用不同的终端设备。
[0100] 2. 在本技术方案 4 条中的 1)，2)，3)，4) 和 8) 模块组成一个基本的用户穿戴设 备，加上一些基本的物理按键和 SIM 卡一起，使得用户可以很方便地使用不同的终端设备 ( 当这些设备具有无线网络连接功能时 ) 来完成通信服务。例如，在办公室可以使用笔记 本电脑或者台式电脑来完成通信服务，在家里可以使用家里的平板电脑，移动固话，或者厨 房里的智能冰箱的相应功能来完成通信服务，甚至在外面的时候使用公用设备来完成通信 服务。当然，也可以使用通常的手机。而所有的这些通信服务都具有唯一的用户身份标识 号 ( 用户号码 ) 和唯一的用户帐单，极大地方便了用户的使用。而 SIM 卡和不同终端设备 之间的无线通信使得这些应用场景的切换是无缝的，用户的使用体验也更为完美。对移动 通信网络服务提供商来说这也极为方便，所有这些应用场景都使用同一个用户身份标识和 同一个用户帐单。
[0101] 3. 由于 SIM 卡是在本技术实施方案的智能型 SIM 卡卡座设备中被用户穿戴，所以 SIM 卡就和用户随时随地同在，不容易被丢失，极大地提高了用户数据和通信的安全性。特 别是当银行账号，个人唯一身份标识和 SIM 卡相关联时，这种安全性就显得更为重要。
[0102] 4. 在如上 1 中所述的移动通信用户设备中，可以只提供低能耗的显示模块如电子 墨水显示屏，和只提供基本的通信服务如语音通话，文字消息，基本的网络连接等，降低设 备的电池消耗，极大地提高了电池的续航能力，提供更为完美的用户体验。
[0103] 5. 在如上 2 中所述的基本功能的智能型 SIM 卡卡座设备中，甚至不提供移动通信 网络连接，也没有显示屏，进一步降低了设备的电池消耗，使得电池的续航能力得到更进一 步提高。

附图说明
[0104] 图 1 是手机的功能模块示意图。模块 1 是手机，具有通常手机的全部功能。模块 2 是卡座，智能型 SIM 卡卡座可以卡在模块 2 中。模块 3 是手机的功能模块，本技术实施方 案的手机端功能主要由模块 3 完成。模块 4 是手机的接触引脚，包括与 SIM 卡接触通信引 脚相对应的有线电路引脚，有线通信电路引脚，电池充电引脚，以及其它的检测和控制电路 引脚。模块 5 是有线通信模块，该有线通信模块通过有线电路和模块 4 的部分接触引脚相 连。连接线路的多少根据不同的有线通信实施例子而不同。模块 6 是通信应用场景检测与 判断模块，也通过电路和模块 4 的部分接触引脚相连，以检测是否有智能型 SIM 卡卡座设备 相连于模块 4。模块 7 是通信控制模块，通过电路和模块 4 的部分接触引脚相连，以发出和 SIM 卡的连接或者断开命令。模块 8 是无线通信模块，以和智能型 SIM 卡卡座设备进行无线 通信。模块 9 是手机端的用户交互模块。其中模块 2，4，5 是可选模块，当手机不提供和 SIM 卡的有线通信连接时，这些模块就可以没有。在手机端也可以只有和 SIM 卡的有线通信连 接，这时模块 8 就是可选模块，可以不提供。
[0105] 图 2 是本发明的智能型 SIM 卡卡座设备功能模块示意图。模块 10 是智能型 SIM 卡卡座设备。模块 11 是和 SIM 卡之间的串行通信模块，该模块和 SIM 卡进行通信，接收从 SIM 卡来的和发送到 SIM 卡的消息或者数据。模块 12 是插入的 SIM 卡，SIM 卡不是本发明 中新的功能模块，但它是组成完整的移动用户设备不可缺少的一部分，并且在本发明中和 智能型 SIM 卡卡座设备一起组成用户穿戴设备。模块 13 是 SIM 卡读写模块，用以访问 SIM

卡中的基本文件 (EF)，读或者写用户的数据如电话号码和文字信息等。模块 14 是连接手 机与 SIM 卡有关通信的通信模块。模块 15 是涉及 SIM 卡有关通信的控制模块。模块 16 是 和外部移动通信网络进行通信的通信模块，通过 SIM 卡的鉴权，授权和认证等过程一起，为 用户提供移动通信服务。模块 17 是人机交互模块，包括物理按键，屏幕，声音输入和输入， 和其它感应模块。模块 18 是电池模块。模块 19 是接触式引脚，和模块 4 进行接触后相连 通。模块 20 是方便用户佩戴的其它配件，如腕带，挂绳，钥匙链等。模块 21 是有线通信模 块，如串口通信，USB 传输和基于 TCP/IP 通信协议的局域网连接等。模块 22 是无线通信模 块，如蓝牙，无线局域网，近场通信，Zigbee 通信，无线 USB，红外通信等。模块 23 是通信控 制模块，用以控制建立或者断开和 SIM 卡的通信以及通知 SIM 卡的连接状态。模块 24 是通 信应用场景检测与判断模块，用以检测 SIM 卡的连接状态。其中有些模块式可选模块，例如 模块 19 和模块 21 是可选的，如果智能型 SIM 卡卡座设备不提供手机和 SIM 卡之间的有线 连接，则模块 19 和模块 21 就可以不具有。相应的，可以不具有模块 22 而不提供手机和 SIM 卡之间的无线连接。
[0106] 图 3 是本发明的基本功能型的智能型 SIM 卡卡座设备功能模块示意图。模块 25 是 基本功能型的智能型 SIM 卡卡座设备。模块 26 是和 SIM 卡之间的串行通信模块。模块 27 是插入的 SIM 卡。模块 28 是 SIM 卡读写模块。模块 29 是连接手机与 SIM 卡有关通信的无 线通信模块。模块 30 是涉及 SIM 卡有关通信的通信控制模块。模块 31 是通信应用场景检 测与判断模块。模块 32 是基本的按键输入模块和基本的输出指示模块。模块 33 是电池模 块。

具体实施方式
[0107] 根据不同的功能需求和实施方案，本发明的智能型 SIM 卡卡座设备可以有不同的 具体实施方式。下面就结合几个不同的具体实施例子来进一步对本发明进行说明。
[0108] 实施例子 1
[0109] 智能型 SIM 卡卡座设备由模块 11，12，13，16，17，18，19，20，21，23，24 组成。
[0110] 手机端由模块 1，2，4，5，6，7，9 组成。
[0111] 模块 19 和模块 4 的连接是 SIM 卡的六个 ( 或者五个 ) 通讯引脚的一一对应连接。
[0112] 首先，智能型 SIM 卡卡座设备和 SIM 卡一起组成完整的移动通信用户设备。当手 机不能够使用时，它们一起为用户提供移动通信服务。当手机能够被使用时，把模块 10 卡 入模块 2 中，使得智能型 SIM 卡卡座设备和手机成为一个整体，进而通过如下步骤组成新的 移动通信用户设备，为用户提供移动通信服务 ：
[0113] 1. 模块 24 检测到手机的存在，预备建立手机和 SIM 卡的通信。
[0114] 2. 模块 24 发出命令给模块 23，要求断开智能型 SIM 卡卡座设备和 SIM 卡之间的 连接。
[0115] 3. 模块 23 控制断开智能型 SIM 卡卡座设备和 SIM 卡之间的连接，并进一步关闭模 块 16 和其它一些不需要的应用模块的电源供应，使得智能型 SIM 卡卡座设备处于节能运行 状态。
[0116] 4. 模块 4 为模块 18 充电。
[0117] 5. 模块 6 检测到 SIM 卡。

[0118] 6. 手机的 SIM 卡通信引脚和 SIM 卡的通信引脚一一对应地建立电路连接。
[0119] 7.SIM 卡按照通常的上电复位流程建立和手机的连接 ：
[0120] 1) 所有的端口都处于低电压状态 (L 态 )。
[0121] 2) 电源电压引脚 (VCC) 首先上电，处于高电压状态 (H 态 )。
[0122] 3) 编程电压引脚 (VPP) 上电。( 或者 VPP 不用 )。
[0123] 4) 电源电压 (VCC) 稳定一段时间后，将数据引脚 (IO) 置为接收状态 (H 态 )。
[0124] 5) 手机为 SIM 卡提供稳定的时钟 (CLK) 信号。
[0125] 6) 手机提供复位 (RST) 信号。
[0126] 7)SIM 卡通过数据 IO 口 (DATA) 进行复位应答
[0127] 8. 手机读取 SIM 卡数据，获得接入移动通信网络所必需的数据。
[0128] 9. 模块 6 通过模块 9 通知用户，SIM 卡连接于手机。
[0129] 10. 手机通过和移动通信网络鉴权，授权，身份认证等过程，完成移动通信网络的 接入。
[0130] 11. 手机和 SIM 卡一起为用户提供移动通信服务。
[0131] 同样，当相反的过程发生，即模块 10 从模块 2 中取出时，则通过如下的步骤恢复智 能型 SIM 卡卡座设备和 SIM 卡之间的通信，为用户提供移动通信服务 ：
[0132] 1. 模块 24 检测到手机的不存在，SIM 卡和手机之间处于断开状态。
[0133] 2. 模块 24 发出命令给模块 23，要求建立智能型 SIM 卡卡座设备和 SIM 卡之间的 连接。
[0134] 3. 模块 23 控制建立智能型 SIM 卡卡座设备和 SIM 卡之间的连接。
[0135] 4.SIM 卡按照通常的上电复位流程建立和智能型 SIM 卡卡座设备的连接。
[0136] 5. 模块 23 通过模块 17 通知用户，SIM 卡连接于智能型 SIM 卡卡座设备。
[0137] 6. 模块 11 和 13 读取必要的 SIM 卡数据。
[0138] 7. 模块 16 建立和移动通信网络的连接。
[0139] 8. 智能型 SIM 卡卡座设备通过和移动通信网络鉴权，授权，身份认证等过程，完成 移动通信网络的接入。
[0140] 9. 智能型 SIM 卡卡座设备和 SIM 卡一起为用户提供移动通信服务。
[0141] 这样，本实施例子方便地满足用户在不同的应用场景的需求。
[0142] 实施例子 2
[0143] 智能型 SIM 卡卡座设备由模块 11，12，13，16，17，18，20，22，23，24 组成。
[0144] 手机端由模块 1，5，6，7，8，9 组成。
[0145] 模块 22 和模块 8 的连接是蓝牙 (Bluetooth) 通信。
[0146] 首先，智能型 SIM 卡卡座设备和 SIM 卡一起组成完整的移动通信用户设备。当手 机不在蓝牙通信的有效范围内时，它们一起为用户提供移动通信服务。当智能型 SIM 卡卡 座设备和手机处于蓝牙通信的有效范围内时，通过如下步骤组成新的移动通信用户设备， 为用户提供移动通信服务 ：
[0147] 1. 模块 24 检测到手机的存在。
[0148] 2. 模块 23 通过模块 17 提示用户，是否要建立 SIM 卡和手机的通信，得到用户的确 认后继续如下过程，否则中断建立 SIM 卡和手机的通信 ( 或者根据预先的设置或其它规则，

省略此步骤 )。
[0149] 3. 通过模块 22 和模块 8 的消息交互，完成 SIM 卡和手机之间的安全验证，身份认 证等过程 ( 或者根据需要省略此步骤 )。
[0150] 4. 模块 23 和模块 7 通过消息交互，确定主控制模块。以下步骤假定模块 7 为主控 制模块，并且所有的步骤都是在主控制模块的控制下完成的。
[0151] 5. 模块 24 发出命令给模块 23，要求断开智能型 SIM 卡卡座设备通过 SIM 卡的网 络连接。
[0152] 6. 模块 23 控制断开智能型 SIM 卡卡座设备通过 SIM 卡的网络连接，并进一步关闭 模块 16 和其它一些不需要的应用模块的电源供应，使得智能型 SIM 卡卡座设备处于低能耗 的节能运行状态。
[0153] 7. 模块 6 检测到 SIM 卡，命令模块 7 建立手机和 SIM 卡之间的连接。
[0154] 8. 手机通过模块 8，向模块 10( 智能型 SIM 卡卡座设备 ) 发出请求，读取存储在 SIM 卡的 IMSI( 国际用户识别码 ) 和 TMSI( 临时用户号 )
[0155] 9. 模块 10 通过模块 22 收到来自模块 8 的读取请求后，通过模块 11 读取 IMSI 和 TMSI。
[0156] 10. 模块 10 通过模块 22 把 IMSI 和 TMSI 发送给手机。
[0157] 11. 手机通过模块 8 收到 IMSI 和 TMSI。
[0158] 12. 手机把 IMSI 和 TMSI 发送给移动通信网络。
[0159] 13. 移动通信网络判断收到的该 IMSI 和 TMSI，如有效，则生成一个 RAND 码，然后 发回给手机。
[0160] 14. 手机收到 RAND 码后，通过模块 8，把 RAND 码发给模块 10。
[0161] 15. 模块 10 通过模块 22 收到 RAND 码后，通过模块 11 把 RAND 码发给 SIM 卡，并向 SIM 卡发出“RUN GSM ALGORITHM”的命令。
[0162] 16.SIM卡以内部的Ki为密钥，以RAND码为输入，运行A3A8算法，生成鉴权码SRES 和加密密码 Kc。
[0163] 17. 模块 10 通过模块 11 读取 SRES 和 Kc。
[0164] 18. 模块 10 通过模块 22 把 SRES 和 Kc 发送给手机。
[0165] 19. 手机通过模块 8 收到 SRES 和 Kc。
[0166] 20. 手机把 SRES 发送给移动通信网络。
[0167] 21. 移动通信网络收到 SRES 后，自己运行一次 A3A8 算法得到自己的 SRES，与手机 返回的 SRES 进行对比，若一致，则完成用户认证过程，该用户为合法用户。
[0168] 22. 手机完成其它的移动通信网络接入过程，为用户提供移动通信服务。
[0169] 23. 手机通过模块 9 通知用户，SIM 卡和手机处于连接状态，通过模块 17 通知用 户，智能型 SIM 卡卡座设备 ( 模块 10) 通过 SIM 卡和通信网络处于断开状态。
[0170] 24.在以后的手机和SIM卡的通信连接持续过程中，当手机需要SIM卡的有关数据 是，都通过模块 8 向模块 10 发出请求，在模块 10 的协助下获得 SIM 卡的相关数据。
[0171] 相似地，当智能型 SIM 卡卡座设备离开手机而不在蓝牙通信的有效范围内时，则 通过如下步骤恢复 SIM 卡和智能型 SIM 卡卡座设备之间的通信，为用户提供移动通信服 务 ：

[0172] 1. 模块 24 检测到手机的不存在，SIM 卡和手机之间处于断开状态。
[0173] 2. 模块 24 发出命令给模块 23，要求建立智能型 SIM 卡卡座设备和 SIM 卡之间的 通信连接。
[0174] 3. 模块 23 控制建立智能型 SIM 卡卡座设备和 SIM 卡之间的连接。
[0175] 4.SIM 卡按照通常的上电复位流程建立和智能型 SIM 卡卡座设备的连接。
[0176] 5. 模块 23 通过模块 17 通知用户，SIM 卡连接于智能型 SIM 卡卡座设备。
[0177] 6. 模块 11 和 13 读取必要的 SIM 卡数据。
[0178] 7. 模块 16 建立和移动通信网络的连接。
[0179] 8. 智能型 SIM 卡卡座设备通过和移动通信网络鉴权，授权，身份认证等过程，完成 移动通信网络的接入。
[0180] 9. 智能型 SIM 卡卡座设备和 SIM 卡一起为用户提供移动通信服务。
[0181] 通过本实施例子，用户可以更为方便的获得移动通信服务，并在各种通信终端之 间无缝切换，获得更为美好的用户体验。
[0182] 实施例子 3
[0183] 基本功能型的智能型 SIM 卡卡座设备由模块 26，27，28，29，30，31，32，33 组成。
[0184] 手机端由模块 1，5，6，7，8，9 组成。
[0185] 模块 22 和模块 8 的连接是蓝牙 (Bluetooth) 通信。
[0186] 当智能型 SIM 卡卡座设备和手机处于蓝牙通信的有效范围内时，通过如下步骤组 成移动通信用户设备，为用户提供移动通信服务 ：
[0187] 1. 模块 31 检测到手机的存在。
[0188] 2. 模块 30 通过模块 32 提示用户，是否要建立 SIM 卡和手机的通信，得到用户的确 认后继续如下过程，否则中断建立 SIM 卡和手机的通信 ( 或者预先的设置或其它规则，省略 此步骤 )。
[0189] 3. 通过模块 29 和模块 8 的消息交互，完成 SIM 卡和手机之间的安全验证，身份认 证等过程 ( 或者根据需要省略此步骤 )。
[0190] 4. 模块 30 和模块 7 通过消息交互，确定主控制模块。以下步骤假定模块 7 为主控 制模块，并且所有的步骤都是在主控制模块的控制下完成的。
[0191] 5. 模块 6 检测到 SIM 卡，命令模块 7 建立手机和 SIM 卡之间的连接。
[0192] 6. 手机通过模块 8，向模块 25( 智能型 SIM 卡卡座设备 ) 发出请求，读取存储在 SIM 卡的 IMSI( 国际用户识别码 ) 和 TMSI( 临时用户号 )
[0193] 7. 模块 25 通过模块 29 收到来自模块 8 的读取请求后，通过模块 26 读取 IMSI 和 TMSI。
[0194] 8. 模块 25 通过模块 29 把 IMSI 和 TMSI 发送给手机。
[0195] 9. 手机通过模块 8 收到 IMSI 和 TMSI。
[0196] 10. 手机把 IMSI 和 TMSI 发送给移动通信网络。
[0197] 11. 移动通信网络判断收到的该 IMSI 和 TMSI，如有效，则生成一个 RAND 码，然后 发回给手机。
[0198] 12. 手机收到 RAND 码后，通过模块 8，把 RAND 码发给模块 25。
[0199] 13. 模块 25 通过模块 29 收到 RAND 码后，通过模块 26 把 RAND 码发给 SIM 卡，并向

SIM 卡发出“RUN GSM ALGORITHM”的命令。
[0200] 14.SIM卡以内部的Ki为密钥，以RAND码为输入，运行A3A8算法，生成鉴权码SRES 和加密密码 Kc。
[0201] 15. 模块 25 通过模块 26 读取 SRES 和 Kc。
[0202] 16. 模块 25 通过模块 29 把 SRES 和 Kc 发送给手机。
[0203] 17. 手机通过模块 8 收到 SRES 和 Kc。
[0204] 18. 手机把 SRES 发送给移动通信网络。
[0205] 19. 移动通信网络收到 SRES 后，自己运行一次 A3A8 算法得到自己的 SRES，与手机 返回的 SRES 进行对比，若一致，则完成用户认证过程，该用户为合法用户。
[0206] 20. 手机完成其它的移动通信网络接入过程，为用户提供移动通信服务。
[0207] 21. 手机通过模块 9 通知用户，SIM 卡和手机处于连接状态。
[0208] 22. 模块 25 通过模块 32 通知用户，有效的移动通信服务可以使用。
[0209] 23.在以后的手机和SIM卡的通信连接持续过程中，当手机需要SIM卡的有关数据 是，都通过模块 8 向模块 25 发出请求，在模块 25 的协助下获得 SIM 卡的相关数据。
[0210] 当智能型 SIM 卡卡座设备离开手机而不再处于蓝牙通信的有效范围内时，则运行 如下步骤并通知用户 ：
[0211] 1. 模块 31 检测到手机的不存在，SIM 卡和手机之间处于断开状态。
[0212] 2. 模块 25 通过模块 32 通知用户，移动通信服务无法使用。
[0213] 3. 模块 31 处于监听检测状态，监听是否有手机处于蓝牙通信的有效范围内，并检 测能否建立起手机和 SIM 卡之间的通信连接。
[0214] 4. 如果有新的手机处于蓝牙通信的有效范围内，或者和已经连接过的手机重新处 于蓝牙通信的有效范围内，重复以上过程建立起手机和 SIM 卡之间的通信，并完成手机的 移动通信网络接入过程。
[0215] 通过本实施例子，解决了移动通信服务的随时随地的有效性和电池的续航能力， 方便得为用户提供移动通信服务。

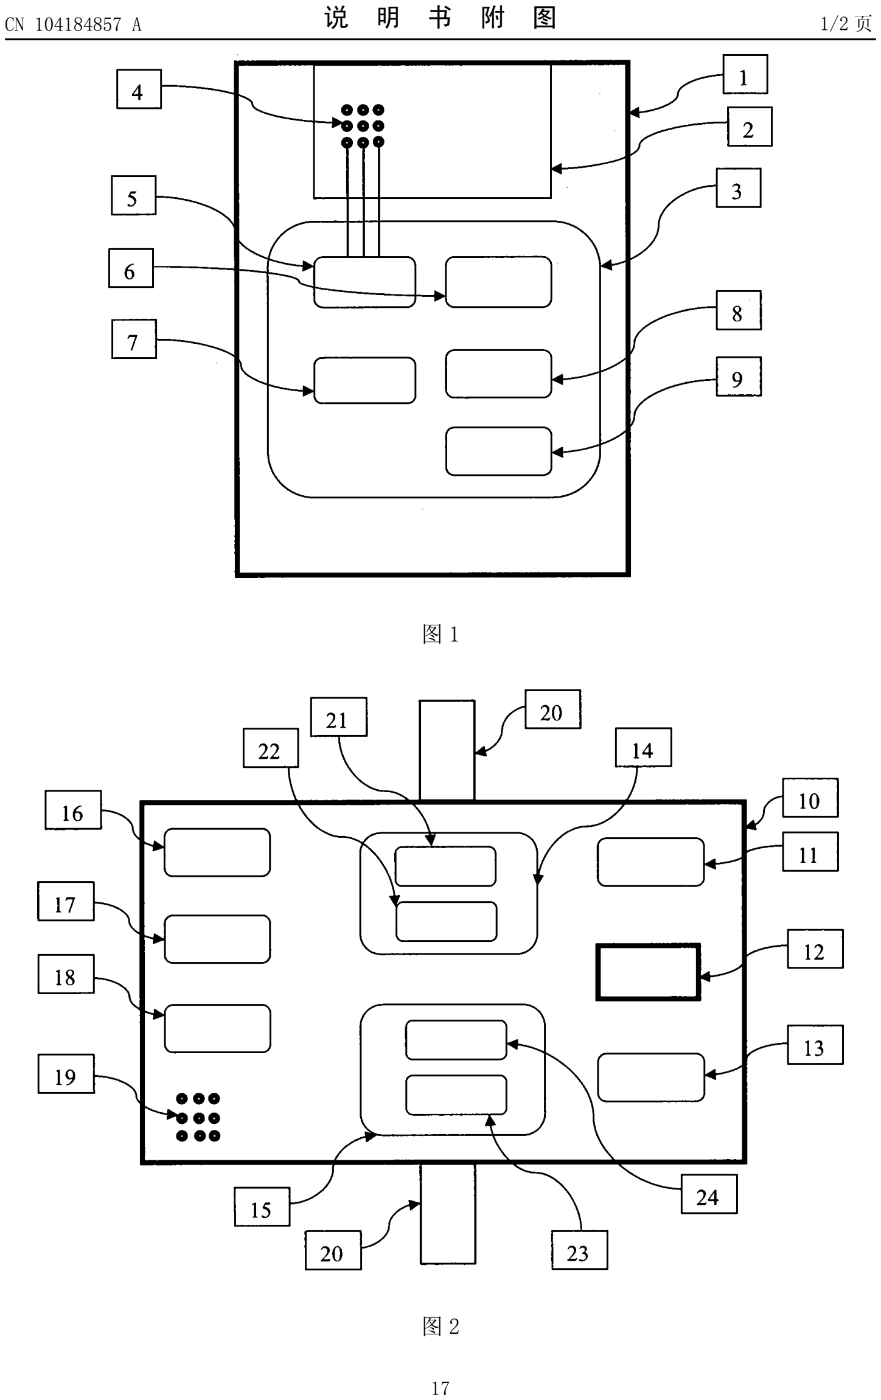
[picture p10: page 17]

1/2 页

图 1

图 2

CN 104184857 A | 说 明 书 附 图

2/2 页

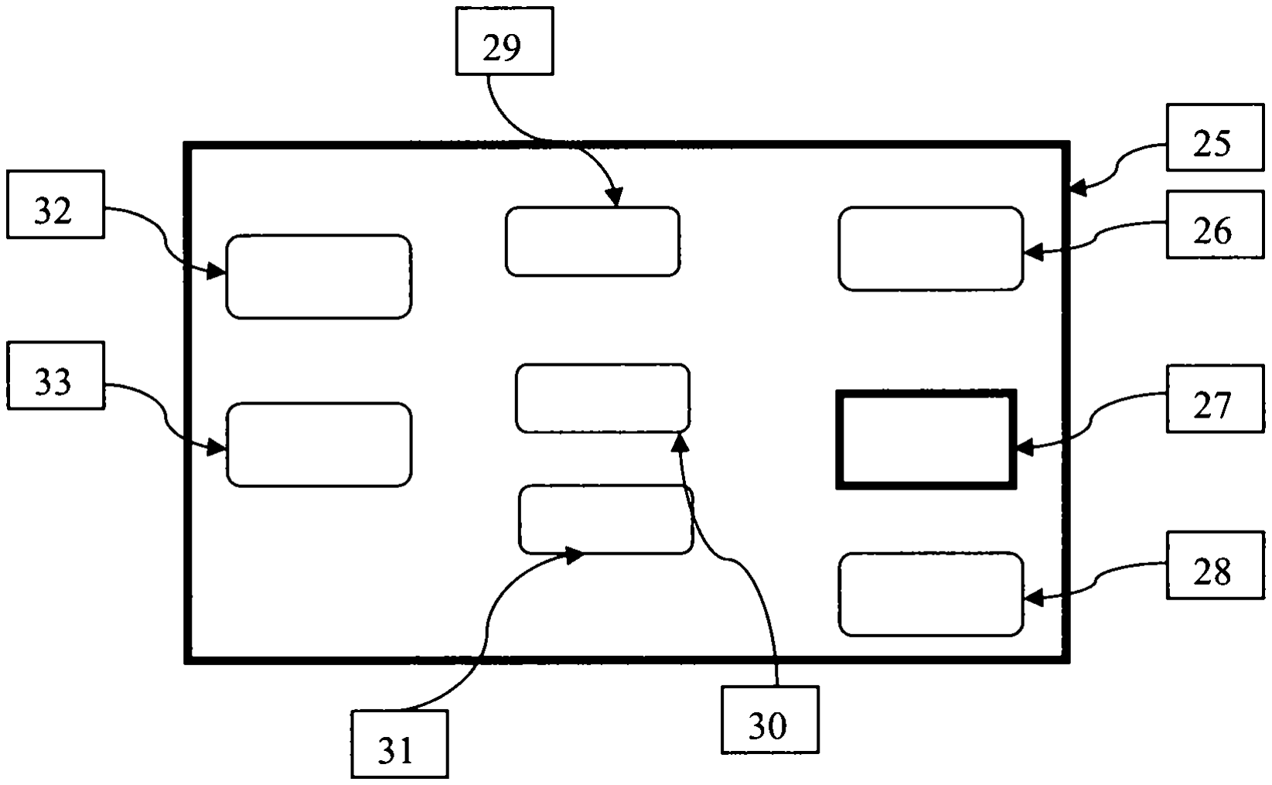
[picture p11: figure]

图 3

CN 104184857 A | 说 明 书 附 图

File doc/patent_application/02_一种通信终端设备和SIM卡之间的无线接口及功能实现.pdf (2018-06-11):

(10)申请公布号
(43)申请公布日
(21)申请号 201410495484.1

(22)申请日 2014.09.25

H04L 1/00(2006.01)
H04W 28/18(2009.01)
H04W 92/08(2009.01)

(71)申请人 王家城
地址 100192 北京市朝阳区林萃西里 26 号
楼 6 单元 602

(72)发明人 王家城

(54) 发明名称
一种通信终端设备和 SIM 卡之间的无线接口
及功能实现
(57) 摘要
本发明属于通信终端设备领域。本发明提供
一种用于连接移动通信终端设备 ( 简称手机 ) 和
用户身份模块卡 ( 简称 SIM 卡 ) 的无线传输协议， 包括 ：1). 在手机端有一个手机接口设备，该设备
通过 ISO-7816 协议和手机进行通信 ；在 SIM 卡端 有一个 SIM 卡接口设备，该设备通过 ISO-7816 协 议和 SIM 卡进行通信。手机接口设备和 SIM 卡接 口设备通过无线传输协议进行通信。2). 提供了
无线传输协议的差错控制 (FEC) 和传输协议数据
单元 (TPDU)，使得这种无线传输接口对于现有的
手机和 SIM 卡之间的触点通信来说是透明的，即
无论对于手机还是 SIM 卡来说，都不会觉察到它
们中间的无线传输接口的存在。

(51)Int.Cl.

(19)中华人民共和国国家知识产权局

## (12)发明专利申请

权利要求书2页 说明书10页 附图3页

(10)申请公布号 CN 104393948 A
(43)申请公布日 2015.03.04

CN 104393948 A

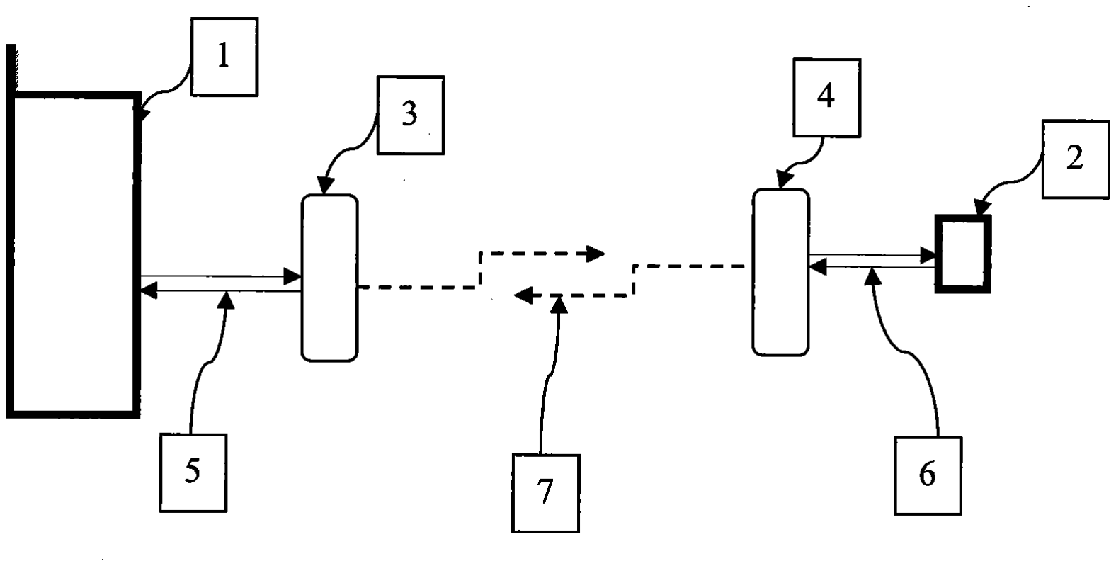
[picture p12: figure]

1/2 页

1. 一种用于连接通信终端设备和用户身份模块卡的无线传输通信协议及设备，其特征 在于 ：
1) 在所述通信终端设备端有一个接口设备，称为通信终端接口设备，
2) 所述通信终端设备和所述通信终端接口设备通过 ISO-7816 智能卡传输协议进行连 接通信，
3) 在所述用户身份模块卡端有一个接口设备，称为用户身份模块卡接口设备，
4) 所述用户身份模块卡和所述用户身份模块卡接口设备通过 ISO-7816 智能卡传输协 议进行连接通信，
5) 所述通信终端接口设备和所述用户身份模块卡接口设备通过无线传输通信协议进 行连接通信，
6) 所述通信终端设备和所述用户身份模块卡之间的数据通信是通过所述通信终端接 口设备，所述用户身份模块卡接口设备以及它们之间的无线传输接口进行转发而建立的连 接进行通信。
2. 根据权利要求 1 所述的无线传输通信协议，其特征在于 ：
1) 所述通信终端设备和在所述用户身份模块卡在建立通信会话的开始时的冷复位 ATR( 复位应答 ) 消息和其后的热复位 ATR 消息以及协议参数选择 PPS( 如有 ) 过程都是在 手机端和用户身份模块卡端分别进行的，即通信终端接口设备对通信终端进行复位应答， 用户身份模块卡对用户身份模块卡接口设备进行复位应答，分别建立起通信终端设备端和 户身份模块卡端的 ISO-7816 通信协议参数，它们之间不通过无线传输协议来交换彼此的 ISO-7816 通信协议参数，也就是说，在通信终端设备端和户身份模块卡端两边的 ISO-7816 通信协议参数是不一致，
2) 或者，所述通信终端设备和在所述用户身份模块卡通过无线传输接口协议交换 双方的 ISO-7816 通信协议参数，建立起户身份模块卡到通信终端设备的端到端的一致 ISO-7816 通信协议参数。
3. 根据权利要求 1 所述的无线传输通信协议，其特征在于 ：接通信终端设备和用户身 份模块卡的数据交换对于无线转发通信来说是透明的，也就是说，通过无线传输接口的转 发通信和他们之间的直接通信 (ISO-7816 协议 ) 是完全一样的，其传输时间延迟和传输差 错都和 ISO-7816 协议以及 GSM 规范的 SIM 卡应用协议是一致的。
4. 根据权利要求 3 所述的无线传输通信协议的传输差错，其特征在于 ：所述传输差错 包括如下部分 ：
1) 在每个传输的字节后面，附加有额外的奇偶检验比特位，
2) 多个传输字节组成一个传输字节块，他们一起进行循环冗余校验和前向纠错编码，
3) 纠错编码后的传输字节块和无线传输协议的控制信息组成无线传输的数据帧，在其 后面有校验域，用于检验无线传输数据的可靠性，
4) 当接收端检测到错误的字节块，并且不能通过纠错编码进行错误纠正的时候，通过 自动重传请求，要求发送端重新发送字节块。这种重传请求可以多次进行，直到收到正确的 字节块，或者重传时间超过允许的最大时间延迟。
5. 根据权利要求 3 所述的无线传输通信协议的传输时间延迟，其特征在于 ：所述传输 时间延迟是指手机传输的最后一个字节的起始时间到手机收到 SIM 卡的响应回复的第一
CN 104393948 A | 权 利 要 求 书

2/2 页

个字节的起始时间，所述传输时间延迟根据不同的应用场景，小于如下时间 ：
1) 所述传输时间延迟小于 500 毫秒，
2) 如果手机和 SIM 卡之间是应用 T ＝ 0 协议，所述传输时间延迟小于 WT ＝ 960*Wi，时 间单位是工作 ETU，
a) 参数 Wi 是在复位应答消息 ATR 的 TC2 字节规定，
b) 如果复位应答消息 ATR 没有 TC2 字节，则 Wi ＝ 10，
c)ETU 是工作基本时间单位，ETU ＝ F/D*(1/f)，即传输一个比特位的持续时间，参数 F 和 D 在复位应答消息 ATR 的 TA1 字节规定，而 f 是 SIM 卡的时钟频率，
d) 如果复位应答消息 ATR 没有 TA1 字节，则 F ＝ 372，D ＝ 1，
3) 如 果 手 机 和 SIM 卡 之 间 是 应 用 T ＝ 1 协 议，所 述 传 输 时 间 延 迟 小 于 BWT ＝ (11+2^BWI*960)，时间单位是工作 ETU，
a) 参数 BWI 是在复位应答消息 ATR 的 TB3 字节规定，
b) 如果复位应答消息 ATR 没有 TB3 字节，则 BWI ＝ 4，
c)ETU 是工作基本时间单位，ETU ＝ F/D*(1/f)，即传输一个比特位的持续时间，参数 F 和 D 在复位应答消息 ATR 的 TA1 字节规定，而 f 是 SIM 卡的时钟频率，
d) 如果复位应答消息 ATR 没有 TA1 字节，则 F ＝ 372，D ＝ 1，
4) 如果手机和 SIM 卡之间是应用 T ＝ 0 协议，并且手机和 SIM 卡之间的复位应答消息 ATR 是通过无线传输接口协议传输的，所述传输时间延迟小于 9600ETU，ETU 是初始基本时 间单位，ETU ＝ 372*(1/f)，其中 f 是 SIM 卡的时钟频率。
6. 根据权利要求 1 所述的无线传输通信协议，其特征在于 ：所述通信终端接口设备和 所述用户身份模块卡接口设备之间的无线传输通信协议是蓝牙通信 (Bluetooth)。
7. 根据权利要求 1 所述的无线传输通信协议，其特征在于 ：所述通信终端接口设备和 所述用户身份模块卡接口设备之间的无线传输通信协议是无线局域网通信 (WLAN，WiFi)。
8. 根据权利要求 6 所述的蓝牙通信技术，其特征在于 ：所述蓝牙通信协议是应用 RFCOMM( 串行线仿真协议 ) 来建立起链路连接，数据发送，数据接收，链路断开的无线通信 过程，所述蓝牙通信协议是应用蓝牙通信物理层技术的 CRC 循环冗余校验位，编码率为 1/3 和 2/3 的 FEC 前向纠错编码，以及 ARQ 自动重传机制来实现如根据权利要求 4 所述的传输 差错控制。
CN 104393948 A | 权 利 要 求 书

1/10 页

一种通信终端设备和 SIM 卡之间的无线接口及功能实现

技术领域
[0001] 本发明属于通信终端设备领域。具体地说，本发明涉及一种适用于通信终端设备 和用户身份模块卡之间的无线传输接口协议，同时，也涉及具体实现这种无线通信传输接 口协议的设备和方法。

背景技术
[0002] 目前，移动通信用户设备主要由通信终端设备 ( 包括手机，移动固话，平板电脑， 笔记本电脑，台式电脑，智能家居设备如智能电视，家庭媒体中心如机顶盒，家庭网络中心 如路由器。为简便，以下都一律简称手机 ) 和用户身份模块卡 ( 包括 GSM 系统的 SIM 卡， CDMA 系统的 UIM 卡，2G，3G 和 4G 系统的 USIM 卡。为简便，以下都一律简称 SIM 卡 ) 两个部 分组成。其中通信终端设备具有连接蜂窝式移动通信网络的基本功能。而用户身份模块卡 主要用于在安全的条件下完成用户身份认证鉴权和用户信息加密算法的全过程，并且还可 以完成对网络的认证，以防止冒充的虚假网络，保护用户的通信安全。
[0003] 在现有的技术实现中，手机有一个固定在其内的 SIM 卡卡座，卡座上有六个引脚， 使得 SIM 卡插入卡座后通过这些引脚 ( 主要是数据 IO 引脚 ) 和 SIM 卡进行接触式的通信。 具体的通信协议在有关的标准中定义 ( 如 ISO-7816 定义传输协议，3GPP TS 11.11 等定义 GSM 应用协议 )。这种通信是一种有线通信形式。然而，由于无线通信的固有方便性，人们做 出大量的努力，希望能用一种方便的无线通信来连接手机和 SIM 卡。但另一方面，由于 SIM 卡存储有用户最为敏感的机密信息 ( 如鉴权密钥 Ki 等 ) 并承担着保护用户的通信安全的 重任，这些努力而得到的方法都或多或少地以牺牲通信安全性为代价，在现有蜂窝式移动 通信网络的身份认证鉴权和接入安全控制机制下，不能够被实现。
[0004] 在中国发明专利申请 201080022761.7“便携式个人 SIM 卡”中 ( 美国专利 US 8244181B2“Portable personal SIM card”)，就提出一种方法，通过近场通信 (NFC) 把 SIM 卡的数据下载到手机，进而手机应用下载的数据接入到移动通信网络。为了叙述方便起见， 下面引用该专利申请的原文及附图进行说明 ：
[0005] 权力要求 1. 一种用于对移动装置进行供应的方法，其包括 ：
[0006] 在所述移动装置与含有 SIM 卡的个人物品之间建立近程通信链路 ；以及
[0007] 经由所述所建立的近程通信链路接收存储在所述 SIM 卡中的供应数据。
[0008] 权力要求 27. 一种个人物品，其包括 ：
[0009] 处理器 ；
[0010] SIM 卡，其耦合到所述处理器，其中所述 SIM 卡在其中存储有用于蜂窝式通信网络 的供应数据 ；以及
[0011] 近程通信收发器，其耦合到所述处理器，
[0012] 其中所述处理器以软件指令配置以执行包括以下操作的步骤 ：
[0013] 建立与移动装置的近程通信链路 ；以及
[0014] 经由所述所建立的近程通信链路将存储在所述 SIM 卡内的所述供应数据发射到
CN 104393948 A | 说 明 书

所述移动装置。
[0015] 发明内容 [0004] 揭示一种用于将存储在单个 SIM 卡中的供应数据提供给多个移 动装置的方法和设备。供应数据存储在包含于例如一件珠宝或腕表等个人物品内的 SIM 卡 中。所述个人物品建立与近程通信链路的有效范围内的移动装置的近程通信链路，且发射 存储在所述 SIM 卡上的供应数据。移动装置使用不同于所述近程通信链路的第二通信链路 来使用所发射和所接收的供应数据与蜂窝式或其它无线通信网络连接。一旦供应数据已交 换，近程通信链路便可终止，且移动装置可使用第二通信链路来建立或接收无线数字通信 呼叫。
[0016] 根据如上所述原文的权利要求 1 和 27，发明内容和图 6，7，8( 原文的图 4A，8，6) 所 示，可以得到发明申请 201080022761.7 的有关基本方法和步骤 ：
[0017] 1) 手机通过和 SIM 卡之间的无线通信链路，下载存储在 SIM 卡上的供应数据 (provisioning data)。
[0018] 2) 手机在下载完 SIM 卡上的供应数据后，断开和 SIM 卡的通信链路。
[0019] 3) 手机通过下载而得到的供应数据，接入到蜂窝式通信网络，进而建立起和网络 的通信链路。
[0020] 实际上，根据发明申请 201080022761.7 所述的方法，按照现有技术对手机接入移 动通信网络的安全控制的要求，手机是不可能接入到网络并为用户提供无线通信服务的。 蜂窝式移动通信网络 ( 如 GSM 系统以及新一代的 3G，4G 通信系统 ) 有完备的身份认证鉴权 过程和网络接入安全控制机制，对于那些用户安全敏感的数据，是不允许在空中传输的，也 是不能被用户获取的。
[0021] 根据发明申请 201080022761.7 所述的方法，手机需要首先下载 SIM 卡的供应数 据，再用所下载的供应数据接入到移动通信网。诚然，手机可以下载存储在 SIM 卡上的部分 数据 ( 如存储在 SIM 卡上的短消息内容，电话号码等 )，但是，那些用于手机接入到移动通 信网络的安全控制数据 ( 如鉴权密钥 Ki 和鉴权密码算法 A38(A3 算法和 A8 算法的合体，又 称 COMP128 算法 ) 的具体实现 ) 是不能被下载的。实际上，根据 SIM 卡的功能性标准 ETSI GSM 02.17，根本就没有用于读取这些数据的接口。这些与用户安全有关的数据只能存储在 于 SIM 卡内部，只在 SIM 卡内部被使用，并受到访问控制。这是因为 ：
[0022] 1)SIM 卡作为移动通信用户的唯一身份标识，是智能卡的一种，除了中央处理器 CPU 和串行通信接口外，其存储区域有三个即工作存储器 RAM，程序存储器 ROM 和数据存储 器EEPROM，存储在其上的数据具有不同的访问权限。特别，作为网络接入控制的安全数据甚 至不是由 SIM 卡生产商在生产阶段写入的，而是由网络服务提供商在供给用户使用时才写 入的，并只能被网络服务提供商访问，以保证安全数据被充分保密。因此，即使用户拥有了 SIM 卡，并不是存储在 SIM 卡上的所有数据都能被用户访问。
[0023] 2)SIM 卡作为智能卡的一种，遵循 ISO-7816 标准。ISO-7816 就是为了提供一种智 能的，不能被复制的身份卡而制作的标准。如果 SIM 卡的所有数据能被手机下载，那么这个 SIM 卡就可以很容易地被复制，甚至不需要具有一个实体的 SIM 卡而在手机中存储全部数 据而作为一个“虚拟”的 SIM 卡，进一步还可以使同一个“虚拟”SIM 卡具有多个拷贝。这样 一来，ISO-7816 标准就失去了作为身份卡标准而存在的意义。每一个智能卡都需要一个唯 一的身份号码(如ICCID，集成电路卡识别码)来彼此区分，它们不能彼此互相代替，更不能

被修改。所以这种能够被任意复制的“虚拟”SIM 卡从本质上讲就不是一个 SIM 卡 ( 由于技 术缺陷等原因如果SIM卡确实能够被复制，只能说明需要升级技术，加强SIM卡的安全性)， 因为它不能被唯一地区分。
[0024] 综上所述，发明申请 201080022761.7 所述的从 SIM 卡下载的供应数据，是不能用 于移动通信网络的网络接入，至少是不能接入按照现有技术实现的网络接入安全控制机制 的蜂窝式移动通信网络。
[0025] 同样，根据发明申请 201080022761.7 的方法，手机在下载完 SIM 卡上的供应数据 后，断开和 SIM 卡的通信链路。这是把手机接入移动通信网络的过程看成是一个静止的，从 手机到网络的单向过程 ( 如发明申请 201080022761.7 的图 6 所示 )。然而实际上，SIM 卡 和网络之间的身份认证鉴权是一个动态的交互过程，涉及到手机和网络连接的整个持续期 间。
[0026] 1) 手机接入到移动通信网络的过程涉及到身份认证鉴权，网络和 SIM 卡之间 ( 而 不是网络和手机之间，手机只能作为一个消息的传递者 ) 有一个消息信令交互过程。手机 向网络发出入网请求后，网络生成一个随机数序列 RAND，发送给手机，手机收到 RAND 后，需 要把 RAND 发给 SIM 卡，SIM 卡以 RAND 和鉴权密钥 Ki 为参数，在 SIM 卡内部运行鉴权密码 算法 A38，生成鉴权码 SRES，然后 SIM 卡把 SERS 码传给手机，手机再传送给网络，供网络验 证用户的合法性。在这个过程中，必须有 SIM 卡的参与，这正是 SIM 卡作为智能卡而具有中 央处理器 CPU 的意义，否则它只需要存储数据而把计算工作转交的手机就可以了。而如果 手机在发起网络接入请求之前就断开了和 SIM 卡的连接，就无法完成这个入网身份认证鉴 权过程。
[0027] 2) 为了进一步加强安全性，有时需要双向的身份认证鉴权。也就是说，SIM 也需要 验证网络的合法性，防止接入到一个虚假的冒充网络。这个时候，由于 SIM 卡已经断开了和 手机的通信链路，就无法和网络进行消息信令交互，完成对网络的身份认证鉴权。
[0028] 3) 实际上，在整个手机与移动通信网络维持连接的过程中，SIM 卡与网络之间的 身份认证鉴权需要持续的进行。例如在在每次发起网络呼叫请求，或者手机收到网络的寻 呼的时候，都需要 SIM 卡的身份认证鉴权的过程，甚至在没有呼叫请求和被呼叫的时候，只 要用户的位置发生变化而需要改变其 VLR( 访问位置寄存器 ) 时，也需要进行身份认证鉴权 的过程。而如果手机和 SIM 卡的 连接是断开的，就无法完成这些身份认证鉴权过程。
[0029] 综上所述，发明申请 201080022761.7 所述的从 SIM 卡下载的供应数据后，就断开 和 SIM 卡的通信链路的方式，也是不能完成移动通信网络的网络接入，至少是不能接入按 照现有技术实现的网络接入安全控制机制的蜂窝式通信网络，也不能维持和网络的持续连 接。
[0030] 退一步讲，如果网络服务提供商愿意和用户分享用于网络接入安全控制的数据 ( 如鉴权密钥 Ki 等 )，也愿意冒着敞开网络安全的大门，迎接假冒各种身份的网络入侵者的 风险，那么实际上，就没有必要需要一个 SIM 卡。用户只需要把那些用于网络接入安全控制 的数据存储在手机上就足够了，当然，也就不需要根据发明申请 201080022761.7 所述的方 法来下载 SIM 卡的供应数据，然后再接入到蜂窝式无线通信网络。
[0031] 所以，要使用发明申请 201080022761.7 所述的方法来完成手机接入到移动通信 网络，需要改变现有的蜂窝式移动通信网络接入的安全控制机制，在不需要用户鉴权密钥

Ki 的情况下，也能够完成身份认证鉴权。这样的安全控制机制类似互联网的用户名 - 密码 登陆方式，大大降低了移动通信网络的安全性。
[0032] 在中国发明申请 201210266545.8“使用单个无线用户身份模块在无线链路上同时 验证多个设备”中，提出了在多个设备之间通过无线连接的方式分享同一个 SIM 卡的方法 ：
[0033] 权力要求 1. 一种用于建立从用户身份模块 (SIM) 到第一设备的无线通信路径的 方法，所述方法包括 ：
[0034] 在 SIM 处接收来自所述第一设备的访问请求 ；
[0035] 从 SIM 向第二设备发送报警 ；以及
[0036] 在 SIM 处接收来自所述第二设备的消息，
[0037] 其中，所述第一设备和所述第二设备是物理地独立的，
[0038] 其中，当所述消息允许所述第一设备访问 SIM 时，SIM 对于所述第一设备准许访 问，以及
[0039] 其中，当所述消息不允许所述第一设备访问 SIM 时，SIM 对于所述第一设备拒绝访 问。
[0040] 发明内容 [0007] 本发明通过提供一种能够与移动设备进行无线通信的 SIM，以使 至少一个设备能够远程地使用一个 SIM 连接到无线网络来解决现有技术的至少一些缺陷。 SIM 可以出现在移动电话中，或可以是独立 (stand-alone) 设备。因为 SIM 无需物理地在这 些设备中重新定位，所以在膝上型设备或手持设备访问 SIM 时，移动电话仍可使用。
[0041] 根据权利要求 1 和发明内容，可以得到有关发明申请 201210266545.8 的关键点 ：
[0042] 1) 另外的一个或多个设备访问手机的 SIM 卡。
[0043] 2) 同时，手机连接于网络中，为用户提供服务。
[0044] 3) 另外的一个或多个设备通过从 SIM 卡获得的信息连接到无线网络
[0045] 这种多个设备同时通过同一 SIM 卡的 ( 通过访问与网络接入有关的信息 ) 接入到 无线通信网络的方法，本质上是违背现有无线通信网络的网络接入安全控制机制的，同时， 网络和手机之间的通信会引起通信的混乱和安全隐患。因为 ：
[0046] 1) 根据 3GPPTS 11.11 标准，当手机和网络处于连接中时，手机和 SIM 的通信接 口 SIM-ME 接口是处于持续的连接中，甚至在通话过程中，如果 SIM 卡从手机中移出而断开 SIM-ME 接口，通话连接就会立即中断。
[0047] 2) 与此同时，另外的设备如果要通过同一个 SIM 的鉴权信息接入到无线通信网 络，在网络看来，已经有用户在网络中，并得到有关的唯一的账单信息和业务授权，但此时 有新的用户请求使用同一账单信息和业务授权，网络端就会引起混乱，无所适从。例如，当 两个设备同时使用网络时，如何去处理账单。
[0048] 3) 由于多个设备同时接入无线通信网络，当网络端有消息或者数据 ( 例如，电话 呼入或者数据下载 ) 需要传输给用户时，数据被传输给哪一个设备是无法确定的。因为 SIM 卡是被网络作为唯一的身份标识，多个设备在网络端看来就是一个用户，无法彼此区分。而 如果同时传给所有设备又违背了无线通信网络最基本的保密通信原则，即用户数据不能被 中途窃听。即使是用户同意分享的信息，也是在接收到后再分享给多个设备，而不能在网络 不知道的情况下，在无线通信链路的中途分发给多个设备。
[0049] 4) 实际上，通过鉴权加密算法 A38 的“碰撞”攻击，早期的 SIM 卡有可能被猜测到

用户鉴权密钥 Ki 而复制 ( 目前的 SIM 卡由于安全性的加强，已经不能被复制 )，同一 SIM 卡 就有可能被复制成 多个完全相同的 SIM 卡而被多个设备同时使用，接入到无线通信网络。 实际的试验表明，通过这种方式接到无线网络的多个设备，当网络呼叫用户时，要么是随机 地呼叫多个设备中的某一个设备，要么是呼叫最后一个接入无线通信网络的设备。同样，发 明申请 201210266545.8 通过共享 SIM 而接入无线网络的多个设备，即使可以接入，但是当 网络呼叫用户时，也只能是一个设备被呼叫。
[0050] 5) 更进一步地，在手机通话过程中，如果有呼入，现有的网络会提示“...... 请稍 后再拨”。而如果是两个手机通过同一个 SIM 卡接入到网络，一个在通话过程中，另一个被 呼叫，如何处理这种情况，根据现有的技术，还不清楚。因为在网络端看来，只有一个用户接 入到网络，而在用户端看来，有两个设备接入到网络。
[0051] 所以，通过发明申请 201210266545.8 的方法接入到无线通信网络的多个设备在 现有的网络中是无法支持的，也是不被网络服务提供商所允许的。
[0052] 在中国发明申请 201410452312.6“一种智能的分离式 SIM 卡卡座设备及通信方 法”中，提出一种在手机和 SIM 卡之间的中间设备，智能型 SIM 卡卡座，来取代现有的固定在 手机内部的 SIM 卡卡座。智能型 SIM 卡卡座和 SIM 卡的接口是现有的接触式引脚，而和手 机的接口可以是无线接口。这样，智能型 SIM 卡卡座只有一个单单的连接作用，只是转发手 机和 SIM 卡之间的数据交换。并且在任一时刻，只有一个用户设备连接于蜂窝式的无线通 信网络。在 SIM 卡和网络双方看来，这个智能型 SIM 卡卡座是透明的，不会觉察到其存在。 对现有的身份认证鉴权过程和网络接入安全控制机制没有任何的影响，很好地兼顾了现有 无线通信网络的安全性和手机 -SIM 卡之间无线传输接口的方便性。
[0053] 本发明的目的就是公开了一种手机和 SIM 卡之间无线传输接口的通信协议。通过 这个无线传输接口的通信协议，把现有在手机中通过 SIM 卡座的六个引脚的直接电路信号 连接 ( 实际上，只有两个引脚，串口数据 IO 口和重置 RST 口，涉及到信息交换 )，转化成无线 通信连接，并对现有的蜂窝式移动通信网络的网络接入安全控制机制和身份认证鉴权过程 没有任何影响，极大地方便了用户的使用。

发明内容
[0054] 本发明的关键之处在于对现有的手机和 SIM 卡之间的带触点的接触式引脚的数 据通信来说，本发明公开的手机和 SIM 卡之间无线传输接口协议的转接通信是透明的。也 就是说，这种无线传输接口的通信协议无论是对手机还是对 SIM 卡来说，都不会觉察到这 个中间转发通信的存在。其具体的技术方案是控制中间无线转发通信的传输时间延迟和传 输差错，使得传输时间延迟和传输差错都在原来的手机和 SIM 卡之间通过接触引脚直接通 信的传输时间延迟和传输差错的允许范围之内。
[0055] 本发明的目的是通过以下的技术方案实现的。图 1 是本发明的各个功能模块示意 图和它们之间的通信连接图。模块 1 是手机，模块 2 是 SIM 卡，模块 3 是手机接口设备，模 块 4 是 SIM 卡接口设备。其中手机 ( 模块 1) 和手机接口设备 ( 模块 3) 通过现有的智能卡 传输协议 ISO-7816 连接 ( 模块 5) 而进行通信，SIM 卡 ( 模块 2) 和 SIM 卡接口设备 ( 模块
4) 也是通过智能卡传输协议 ISO-7816 连接 ( 模块 6) 进行通信。手机接口设备 ( 模块 3) 和 SIM 卡接口设备 ( 模块 4) 进一步通过无线传输通信协议 ( 模块 7) 进行通信，这样，手机

和 SIM 卡之间通过各自的接口设备和接口设备之间的无线传输转发，建立起了它们之间的 通信连接。
[0056] 在手机和 SIM 卡建立起通信会话的开始阶段，或者在通信会话过程中由于传输错 误需要重启通信会话，有一个通信协议参数协商过程。SIM 卡向手机传输 ATR( 冷复位应答 或者热复位应答 ) 消息，传输协议参数包括在 ATR 消息中，或者包括在紧接着 ATR 消息后得 PPS( 协议参数选择 ) 会话中。在本发明中，其 ATR 消息 ( 或者 PPS 消息 ) 就不需要通过无 线传输接口从 SIM 卡传输给手机，而是在手机端，由手机接口设备 ( 模块 3) 对手机 ( 模块
1) 进行复位应答，在它们之间商议 ISO-7816 协议参数 ( 模块 5 的协议参数 ) ；而同时在 SIM 端，由 SIM 卡 ( 模块 2) 对 SIM 卡接口设备 ( 模块 4) 进行复位应答 ATR( 或者 PPS，协议参数 选择 )，在它们之间商议 ISO-7816 协议参数 ( 模块 6 的协议参数 )。其中模块 5 的协议参 数和模块 6 的协议参数可以不一致。当然，它们之间也可以通过无线传输接口彼此交换复 位应答消息或者 PPS 消息，使得两端的 ISO-7816 传输协议参数是一致的。
[0057] 在现有的技术实现中，SIM 卡和手机之间大多是应用 ISO-7816 的 T ＝ 0 协议 ( 字 节传输协议 )，也就是说 T ＝ 0 协议所处理的最小单位是单个字节，包含 8 个比特位。在 8 个比特位之前有 1 个起始位，在 8 个比特位之后有 1 个传输错误检测的校验位，总共有十个 比特位传输一个字节。在 SIM 卡和手机之间是一个字节接着一个字节的传输，字节之间通 过其起始位 ( 一个比特位 ( 工作 ETU，工作基本时间单位 ) 的低电平信号 ) 来区分，并且在 字节之间有一个传输错误反馈机制，对于错误的传输字节，需要紧接着立即重传该错误的 字节。在本发明中，模块 5 和模块 6 遵循现有的智能卡传输协议 ISO-7816( 即现有的 SIM 卡和手机之间的传输协议 )。在无线传输接口协议模块 7 中，由于有无线传输协议数据单 元的封装，每 8 个比特可以表示一个字节，它们之间不需要一个比特位来区分。为了提供更 强的无线传输差错控制，在 8 个比之特后有一个额外的校验位。也就是说，加上原来的校验 位，总共有 10 个传输比特位中，其中前面的 8 个是一个字节的信息比特位，后面的 2 个是错 误检测的校验比特位。
[0058] 图 2 是本发明的字节传输协议单元的一个例子，包括 2 个单元模块，即模块 8 和模 块 9。其中模块 8 是传输字节的 8 个信息比特位，比特 0 至比特 7。而模块 9 是传输字节的 2 个校验比特位，比特 8 至比特 9。校验比特位 8 和 9 可以是相同的奇偶校验位的重复，也 可以是其它形式。通过比 ISO-7816 协议多 1 个比特的校验位，提供更强的字节差错控制， 使得无限传输接口协议更为可靠。
[0059] 在 ISO-7816 的 T ＝ 0 协议中，在同一个传输方向 ( 手机向 SIM 卡传输，或者 SIM 卡 向手机传输 )，字节是一个一个的传输，并且传输错误检测和重传也是基于字节的。在本发 明中的无线传输接口协议中，为了更有效率的传输手机和 SIM 卡之间的数据交换，在同一 个方向上连续传输的若干字节就可以连接起来，组成一个传输字节块。这样的一个字节块 可以进行联合纠错编码，例如传输字节块的 CRC 校验 ( 循环冗余校验 ) 和 FEC( 前向纠错 ) 纠错编码。并且连续传输的若干字节在一起传输，可以组成一个完整的命令或者对命令的 响应，这样当手机或者 SIM 卡收到字节块后，就可处理命令，而不需要等待下一个字节在无 线传输接口的传输延迟。
[0060] 图3是本发明的一个无线传输数据帧形成的例子。模块10是一个典型的ISO-7816 命令传输协议数据单元 (C-TPDU)，它包含有 5 个字节的命令头。CLA 表示命令类别，INS 表

示指令代码，P1 和 P2 表示命令的两个附加参数，P3 指名了紧接着手机要传给 SIM 卡的数据 的长度，或者期待SIM卡要回送的数据的最大长度。这5个字节的命令头就组成一个传输字 节块，每个字节有 8 个信息比特位和 2 个校验比特位，总共 50 个信息比特位，再加上 CRC 循 环冗余校验位和 FEC 前向纠错编码位，就组成了模块 11，即无线传输的信息比特域。最后， 加上一些必要的传输控制信息如无线传输的目标地址，数据的长度指示就构成了无线传输 接口的数据帧，即模块 12。这样的无线传输的数据帧在空中接口被一次性地传输，5 个字节 的命令头就可以被 SIM 卡一次完整地接收，减少了命令传输协议数据单元在空中无线接口 的传输延迟。
[0061] 当 SIM 卡接收到命令头以后，向手机回送一个过程字节。如果过程字节指明手机 可以传输该命令头的后续数据，同样，这些数据字节就组成了一个传输字节块，加上 CRC 循 环冗余校验位和 FEC 前向纠错编码位，并形成无线传输接口的数据帧，一次性的全部传送 个 SIM 卡。SIM 卡需要回送给手机的数据也可以用同样的方式在无线空中接口一次传输，从 而减少数据在空中无线接口的传输延迟。
[0062] 对于 ISO-7816 的 T ＝ 1 协议 ( 字节组传输协议 )，由于一次传输的字节组是由多 个字节组成，所以，在无线传输的数据帧形成过程中，传输字节组的多个字节就形成了一个 自然的字节块，它们一起进行 CRC 校验和 FEC 纠错编码，并最终形成一个无线数据帧，一次 性地在空中传输。
[0063] 图 4 是 T ＝ 1 字节组传输协议的无线传输的数据帧形成例子示意图。模块 13 是 字节组传输协议的字组数据帧，包含 3 个部分，组头字段，信息字段和组尾字段。其中组头 字段有 3 个字节，即节点字节 (NAD)，协议控制字节 (PCB) 和长度 (LEN) ；信息字段是可选 地，长度是 0-254 个字节，包含有应用协议数据单元 (APDU) 或者控制信息 (INF) ；而组尾字 段是 1 个字节的错误检测 (EDC)。这些字节就是本发明的无线传输接口协议的有效信息载 荷，把它们一起进行 CRC 循环冗余校验位和 FEC 前向纠错编码位，就形成了无线传输的信息 域，即模块 14。最后，再加上一些必要的无线传输的控制信息域，就组成了本发明的无线传 输接口协议的空中接口数据帧，即模块 15，在无线传输接口协议的空中接口中一次性地被 传输。
[0064] 当接收端检测到无线数据帧有传输错误，并且错误是无法通过纠错编码进行错误 纠正的时候，就可以通过 ARQ( 自动重传请求 ) 机制，请求发射端重新传送字节块。并且这 种字节块的重新传送可以重复多次， 直到接收到正确的字节块，或者同一字节块的传输时 间大于最大等待时间 (WT)，手机发出热复位命令或者终止和 SIM 卡的会话。
[0065] 这样，通过多层次的传输错误控制机制，包括单个字节的奇偶检验，多个连续传输 的字节快的 CRC 校验和纠错编码的错误比特保护，和自动重传请求机制，确保了本发明的 无线传输协议的可靠性。使得和现有的手机和 SIM 卡之间的触点通信比较起来，具有相同 的传输可靠性。
[0066] 手机和 SIM 卡的数据交换总是从手机发送命令，SIM 卡对命令进行回应的方式进 行。根据本发明的传输方式，由于手机接口设备和 SIM 卡接口设备以及它们之间的无线传 输接口的转发，这种命令和响应的交互方式就会有额外的延迟 ( 相对于现有的带触点的接 触式引脚通信来说 )。为了使得本发明的无线传输接口对于手机和 SIM 卡的数据交换是透 明的，这种数据传输的延迟就应当在现有的 ISO-7816 的最大传输延迟和 GSM 规定的最大处

理延迟的范围之内。
[0067] 图 5 是本发明的传输延迟的例子，模块 16 是总的传输时间延迟。即手机端在发 送最后一个命令字节后，直到它接收到 SIM 卡的响应的第一个回应字节之间的总共时间延 迟。包括手机接口设备的数据处理和无线转发延迟，从手机接口设备到 SIM 卡接口设备之 间无线传输的空中传输延迟，SIM 卡接口设备接收处理及向 SIM 卡的转发延迟，SIM 卡的处 理延迟，SIM 卡接口设备的数据发送处理及无线转发延迟，SIM 卡接口设备到手机接口设备 之间无线传输的空中传输延迟，最后还有手机接口设备的接收处理及向手机的转发延迟。 模块 16 的时间延迟是指手机传输的最后一个字节的起始时间到手机收到 SIM 卡的响应回 复的第一个字节的起始时间。根据 ISO-7816 智能卡传输协议，在 T ＝ 0 和 T ＝ I 协议中都 规定了这种在相反方向上的最大等待时间。为了使得本发明的无线传输接口协议对于手机 和 SIM 卡之间的数据交换是透明的，传输时间总延迟模块 16 就必须小于这些协议规定的最 大延迟，如下所述 ：
[0068] 1) 如果 SIM 卡的复位应答消息 ATR 是通过无线传输方式在手机和 SIM 卡之间交 换的，对于 T ＝ 0 协议，有一个最大初始等待时间，也就是说，SIM 卡回复的连续两个数据的 起始沿之间的时间间隔。ISO-7816 规定这个时间间隔不超过 9600 个初始 ETU，对于缺省的 参数设置来说，这个时间就是 1 秒。在手机和 SIM 卡建立连接的开始，ATR 消息的第一个字 符，初始字符 TS，可以直接由手机接口设备直接传给手机，而不需要经过无线传输接口协议 由 SIM 卡传来。因为初始字符 TS 只是规定了后续字节的逻辑约定，只存在于手机接口设备 和手机之间。对于后续的传输协议参数约定，其最大的时间延迟，模块 16，就必须小于 9600 个初始 ETU 的时间。当然，如果复位应答消息 ATR 不是通过无线传输接口协议由 SIM 卡传 输给手机的，而是在手机和手机接口设备之间，SIM 卡接口设备和 SIM 卡之间分别建立的， 那么，总计延迟时间模块 16 的时间就可以不受这个最大初始等待时间的限制。
[0069] 2)T ＝ 0 协议规定了在字节传输过程中，有一个等待时间 WT，即两个连续字节之间 ( 当前字节是由 SIM 卡传输，上一个字节是由手机或者 SIM 卡传输 ) 的最大等待时间延迟为 WT。其具体的计算是 ：WT ＝ 960*Wi，时间单位是工作 ETU。其中参数 Wi 是在复位应答消息 ATR 的 TC2 字节规定，如果 ATR 没有提供 TC2 字节，则 Wi 取缺省值 10，即 WT 等于 9600 个工 作 ETU。这样，总延迟时间模块 16 的时间就小于 WT ＝ 9600 个工作 ETU 的传输时间。
[0070] 3)T ＝ I 协议规定了在字组传输过程中，有一个块等待时间 BWT，即相反方向上两 个连续字节块的最大时间延迟。BWT ＝ (11+2^BWI*960)，时间单位是工作 ETU。参数 BWI 是 在复位应答消息 ATR 的 TB3 字节规定，取值范围是 0-4 之间，缺省值是 4。即 BWT 的缺省时 间是 15371 个工作 ETU。这样，总延迟时间模块 16 的时间就小于 BWT ＝ 15371 个工作 ETU 的传输时间 ( 缺省 )。
[0071] 4) 在 SIM 卡应用协议 3GPP TS 03.20 中，规定了用户身份认证鉴权算法 A3 的运 行时间是小于 500ms( 毫秒 )，即是说 SIM 卡的处理时间 ( 运行 A3 算法时 ) 小于 500 毫秒。 在本发明中，再加上接口设备的转发和空中的无线传输延迟，也就小于 500 毫秒。这样，总 延迟时间模块 16 的时间就小于 500 毫秒。
[0072] 根据以上的计算，现有的无线传输技术，如无线局域网 WiFi，无线蓝牙技术，其传 输时间延迟都远远小于这些时间延迟要求，可以直接应用于本发明的无线传输接口协议。 例如，对于蓝牙技术，从发射端到接收端的时间延迟可以短至 3 毫秒，在空中一个往返传输

就是 6 毫秒，远远小于 ISO-7816 的字节传输等 待时间，也远远小于 GSM 规范规定的 SIM 卡 处理时间延迟要求。这样，在 SIM 卡接口设备和手机接口设备之间，可以多次重传同一个无 线传输数据帧，而时间延迟也在要求的范围之内，从而提高本发明的无线传输接口协议的 传输可靠性。
[0073] 综上所述，本发明的无线传输接口协议提供了完备的传输差错控制和传输延迟控 制，使得无线传输接口协议的转接通信对于手机和 SIM 卡来说都是透明的，对它们之间的 数据交换没有任何影响，它们之间的数据传输可以无缝地进行。
[0074] 发明的效果
[0075] 在本发明的技术实施方案中，无线传输接口协议提供了完备的传输差错控制和传 输延迟控制，把现有在手机中通过 SIM 卡座的六个引脚的直接电路信号连接转化成无线传 输通信连接，使得这种无线转发 ( 包括手机和手机借口设备之间，SIM 卡和 SIM 卡接口设备 之间的有线转发 ) 通信对于手机和 SIM 卡来说都是透明的，对现有的蜂窝式移动通信网络 的网络接入安全控制机制和身份认证鉴权过程没有任何影响，也对 SIM 卡对网络的通信鉴 权没有任何影响。移动通信网络服务提供商无需也不能知道这个转发通信的存在，对用户 身份的认证鉴权，网络接入安全控制，用户帐单的处理都可以按照现有的方式进行。对用户 来说，可以通过本发明的无线传输接口协议，在不同的应用场景，把 SIM 卡连接于不同的通 信终端设备而获取移动通信服务，极大地方便了用户的使用。

附图说明
[0076] 图 1 是本发明的各个功能模块示意图和它们之间的通信连接图。模块 1 是手机， 模块 2 是 SIM 卡，模块 3 是手机接口设备，模块 4 是 SIM 卡接口设备。模块 1 和模块 3 通过 模块 5 进行通信，模块 2 和模块 4 通过模块 6 进行通信。模块 3 和模块 4 进一步通过无线 传输通信协议模块 7 进行通信。
[0077] 图 2 是本发明的字节传输协议单元的一个例子。其中模块 8 是传输字节的 8 个信 息比特位，比特 0 至比特 7。而模块 9 是传输字节的 2 个校验比特位，比特 8 至比特 9。
[0078] 图 3 是本发明的一个无线传输数据帧形成的例子。模块 10 是传输字节信息块，模 块 11 是加上错误检测和纠错编码后，组成无线传输的信息比特域，模块 12 是加上传输控制 信息的无线传输接口数据帧。
[0079] 图 4 是本发明的另一个无线传输数据帧形成的例子。模块 13 是传输字组信息块， 模块 14 是加上错误检测和纠错编码后，组成无线传输的信息比特域，模块 15 是加上传输控 制信息的无线传输接口数据帧。
[0080] 图 5 是本发明的传输延迟示意图，传输时间延迟模块 16 是指手机传输的最后一个 字节的起始时间到手机收到 SIM 卡的响应回复的第一个字节的起始时间。包括手机接口设 备的数据处理和无线转发延迟，从手机接口设备到 SIM 卡接口设备之间无线传输的空中传 输延迟，SIM 卡接口设备接收处理及向 SIM 卡的转发延迟，SIM 卡的处理延迟，SIM 卡接口设 备的数据发送处理及无线转发延迟，SIM 卡接口设备到手机接口设备之间无线传输的空中 传输延迟，以及手机接口设备的接收处理及向手机的转发延迟。
[0081] 图 6 是发明申请 201080022761.7 原文的图 4A，图 7 是发明申请 201080022761.7 原文的图 8，图 8 是发明申请 201080022761.7 原文的图 6。

具体实施方式
[0082] 根据不同的现有无线传输技术，本发明的通信终端设备和 SIM 卡之间的无线传输 接口协议可以有不同的具体实施方式。下面就以蓝牙通信技术为例来进一步对本发明进行 说明。
[0083] 如图 1 所示，在手机端，手机和手机接口设备之间的通信是现有的 ISO-7816 智能 卡传输协议 ；而在 SIM 卡端，SIM 卡和 SIM 卡接口设备之间的通信也是现有的 ISO-7816 智 能卡传输协议。所以，下面就具体说明在手机接口设备和 SIM 卡接口设备之间通过蓝牙通 信技术来实现本发明的无线传输接口协议。
[0084] 从蓝牙通信技术的数据链路协议来看，有一个中间协议层，电缆替代协议 (RFCOMM)。RFCOMM 是基于 ETSI TS-07.10 规范的串行线仿真协议，RFCOMM 协议层位于 L2CAP 协议层和应用层协议之间，是 一个传输层协议，在蓝牙基带协议上仿真 RS-232 控制 和数据信号，为使用串行线传送机制的上层协议提供服务。RFCOMM 是使一种简单的传输协 议，其目的是针对如何在两个不同设备上的应用之间保证一条完整的通信路径，并在它们 之间保持一个通信段。在 RFCOMM 的基础上，蓝牙串口协议 (SPP Profile) 提供了面向应用 的 Profile，具有更好的设备之间传输兼容性。本发明的通信终端设备和 SIM 卡之间的无线 传输接口协议就可以基于 RFCOMM 协议来实现。其具体的实施方案可以分为链路连接，数据 发送，数据接收，链路断开的过程。
[0085] 1) 链路连接，首先要建立 RFCOMM 会话，协商传输信道的传输参数，并建立起用户 数据的传输链路，得到确认后就建立起了链路连接。
[0086] 2) 用户数据和控制命令的发送，在这个过程中有数据链路的传输流量控制。
[0087] 3) 用户数据和控制命令的接收。
[0088] 4) 链路断开，当接收端和发射端的两个应用要结束通信对话的时候，就断开他们 之间的 RFCOMM 链接。
[0089] 在蓝牙通信技术的物理层，也提供了完备的传输差错控制机制，包括 CRC 循环冗 余校验位，编码率为 1/3 和 2/3 的 FEC 前向纠错编码，以及 ARQ 自动重传机制。这些差错控 制协议都可以直接应用于本发明的无线传输接口协议，而得到很好的传输差错控制。
[0090] 蓝牙通信技术也提供了很好的传输时间延迟控制。在两个蓝牙设备之间，通过蓝 牙 4.0 协议，可以在 3 毫秒之内建立起通信链路并开始进行数据通信。应用于本发明的无 线传输接口协议，完全满足传输时间延迟的需求。
[0091] 通过蓝牙通信技术来转发手机接口设备和 SIM 卡接口设备之间的数据交换，几乎 可以不加以任何修改的具体实施。蓝牙通信技术为本发明的通信终端设备和 SIM 卡之间的 无线传输接口协议提供了一个很好的具体实施例子。
[0092] 通过其它的一些现有无线传输技术，也可以具体实施本发明的通信终端设备和 SIM 卡之间的无线传输接口协议，只要其传输时间延迟和传输差错控制满足要求就可以了。 例如 WiFi，无线 USB，Zigbee 等都可以应用于本发明的具体实施例子中。

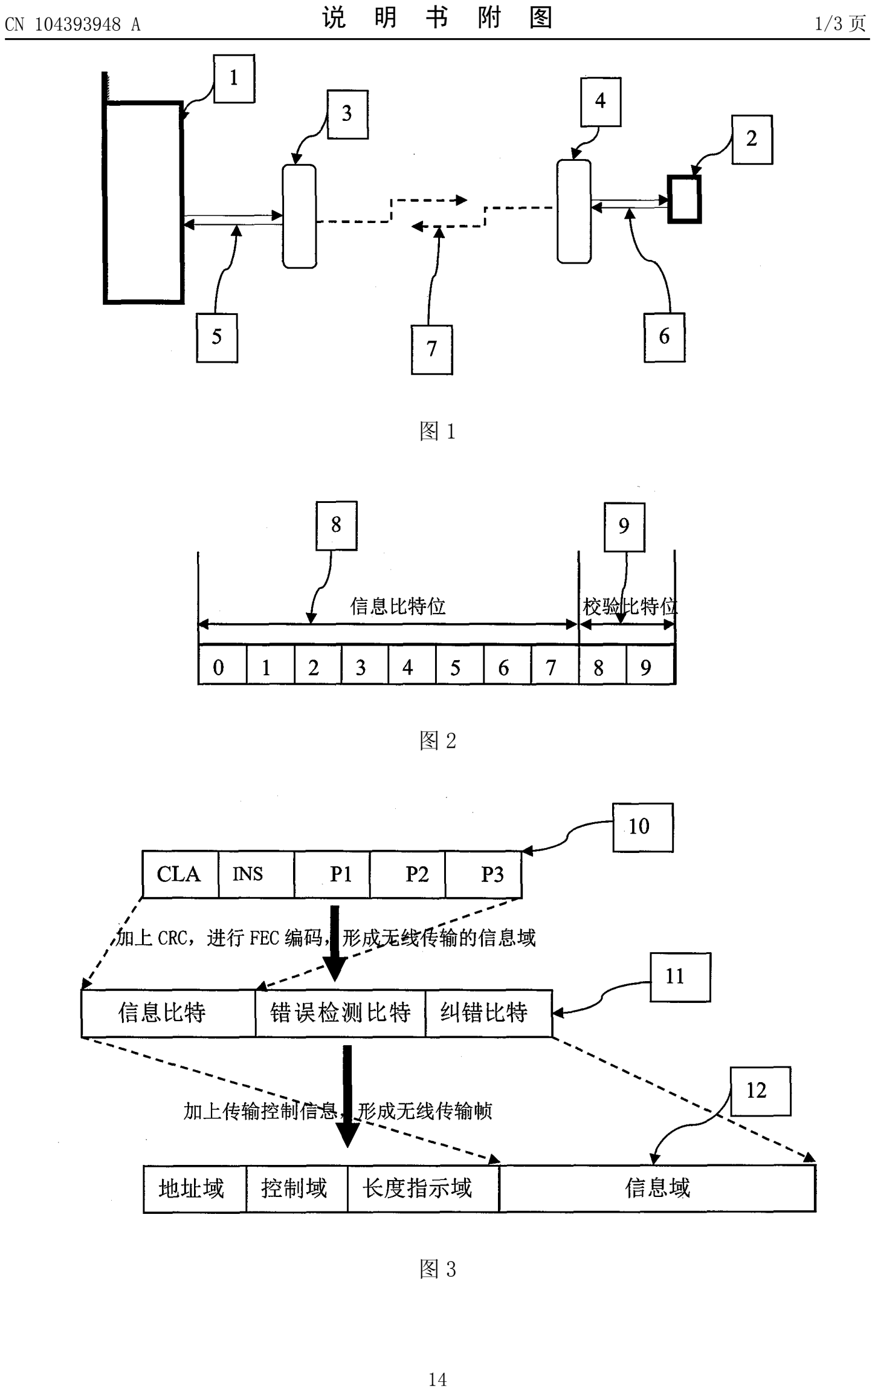
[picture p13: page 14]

1/3 页

图 1

图 2

图 3

CN 104393948 A | 说 明 书 附 图

2/3 页

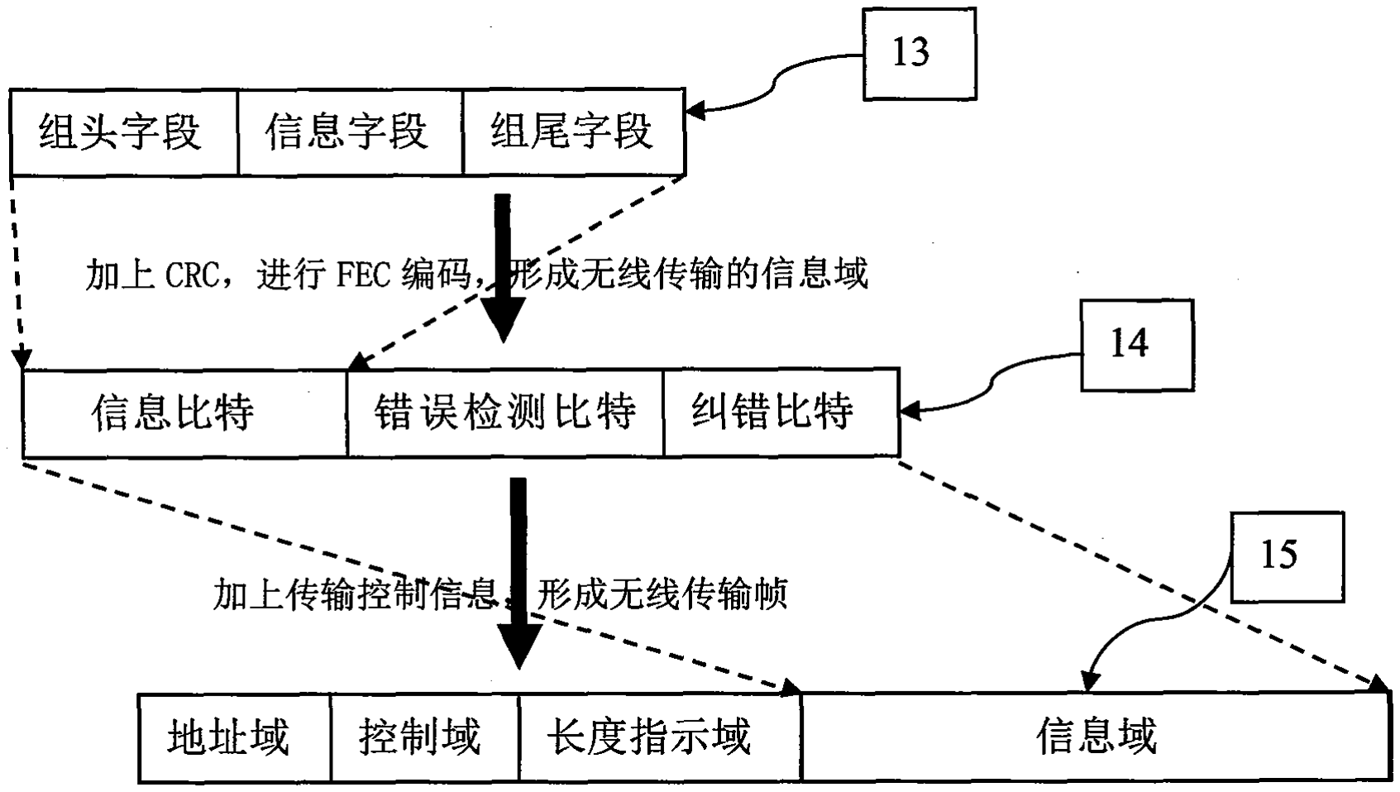
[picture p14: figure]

图 4

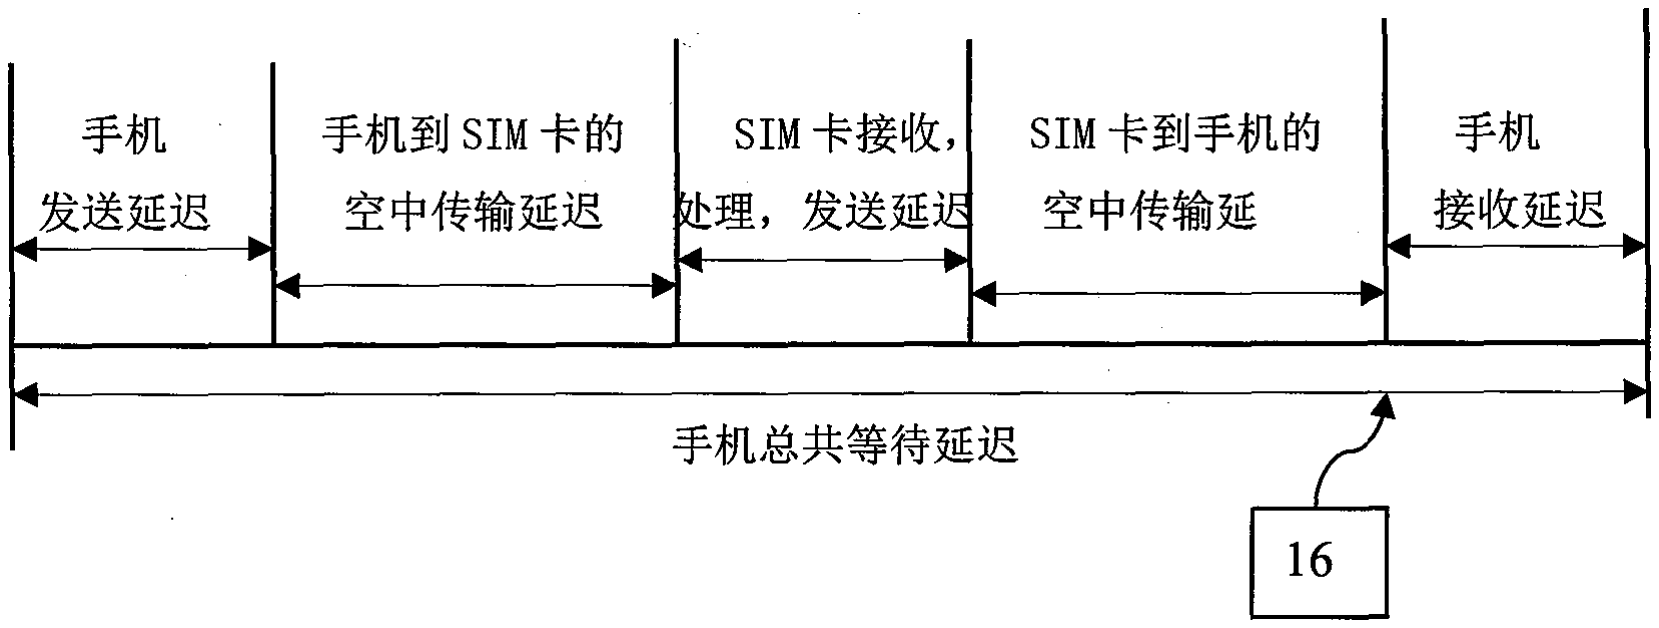
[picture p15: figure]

图 5

CN 104393948 A | 说 明 书 附 图

3/3 页

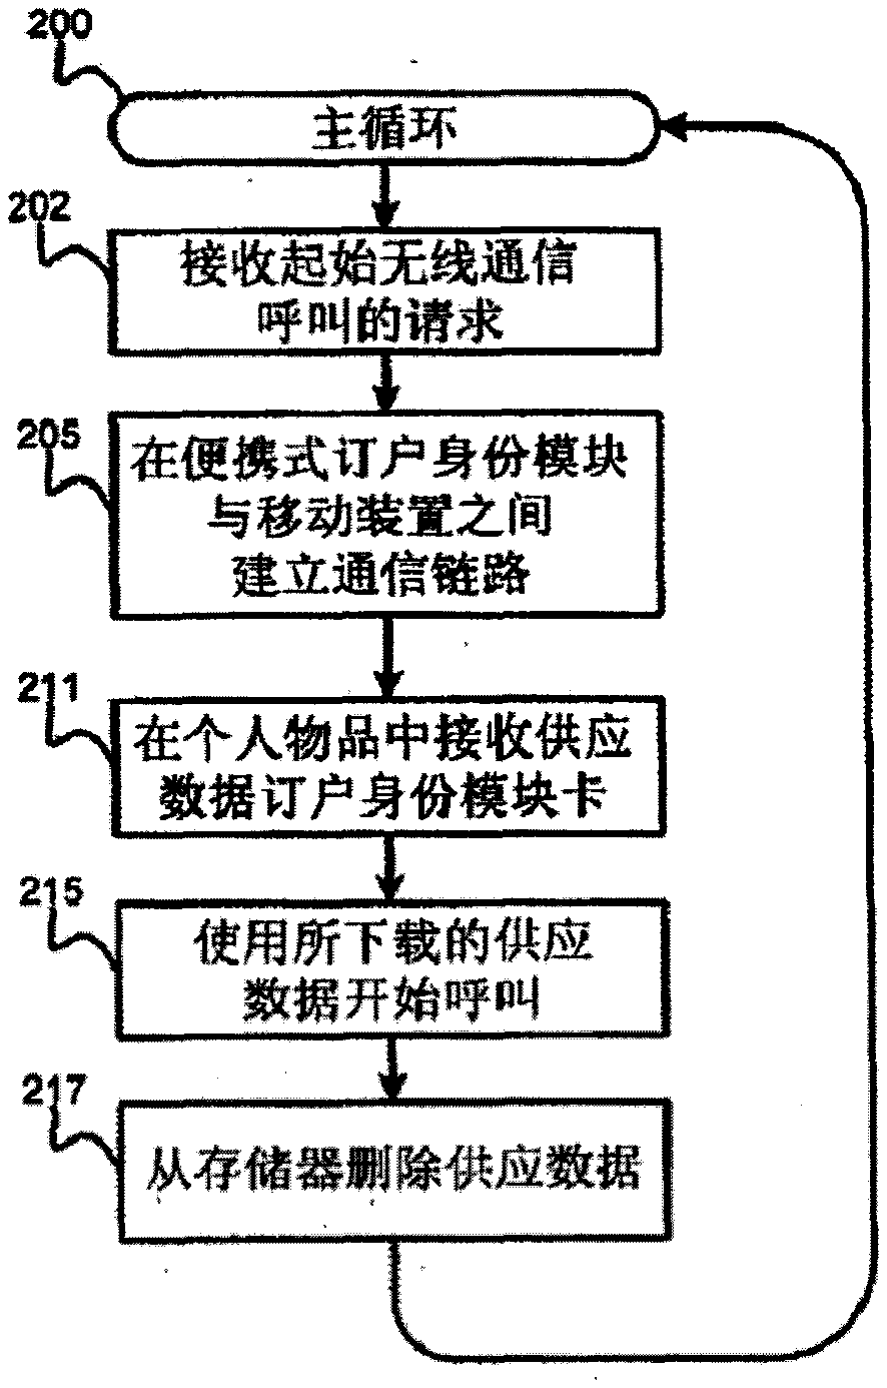
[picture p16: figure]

图 6

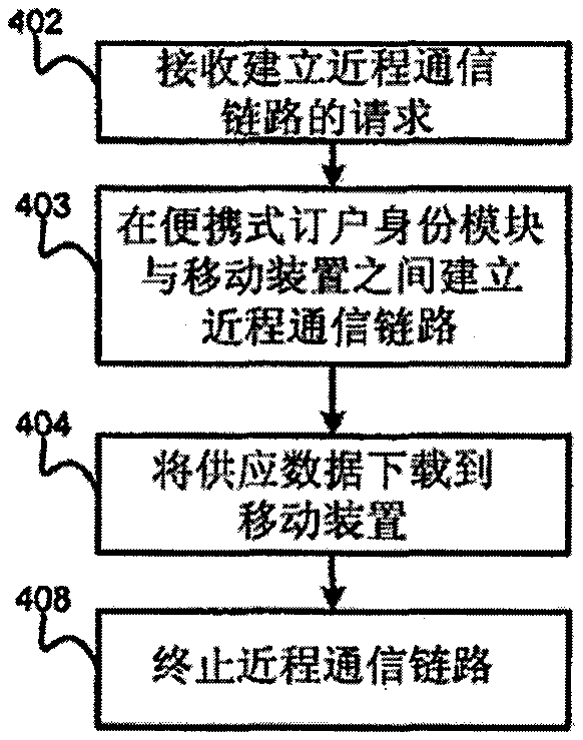
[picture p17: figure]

图 7

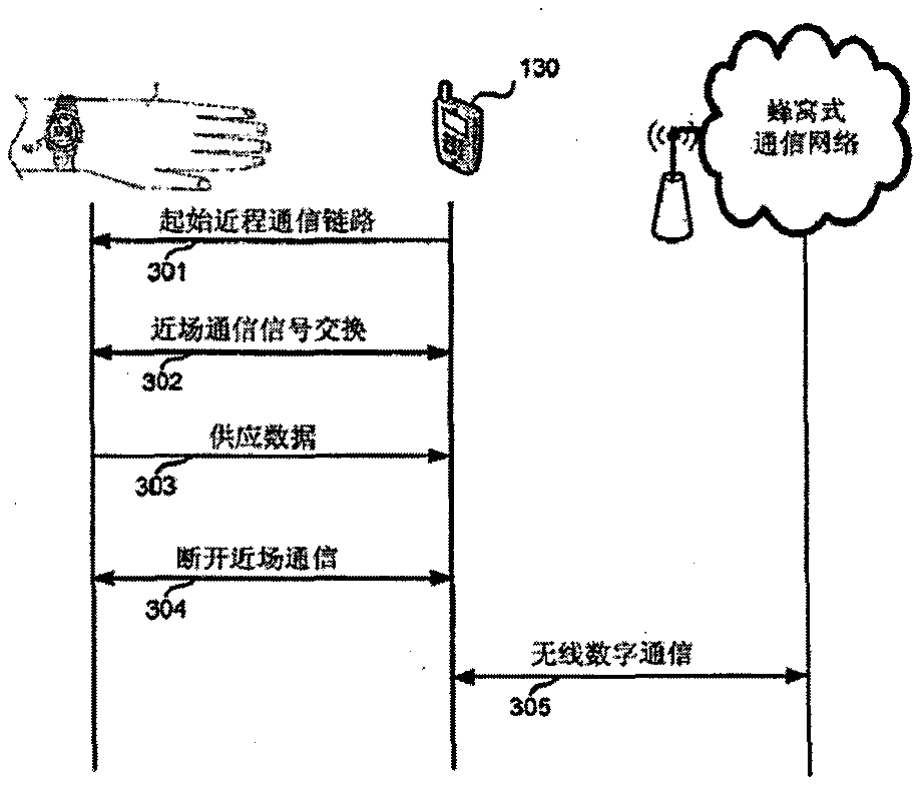
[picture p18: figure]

图 8

CN 104393948 A | 说 明 书 附 图

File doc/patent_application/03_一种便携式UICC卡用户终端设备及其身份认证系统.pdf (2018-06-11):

(10)申请公布号
(43)申请公布日
(21)申请号 201410653530.6

(22)申请日 2014.11.18

H04W 12/06(2009.01)
H04L 29/06(2006.01)

(71)申请人 王家城
地址 100192 北京市朝阳区林萃西里 26 号
楼 6 单元 602

(72)发明人 王家城

(54) 发明名称
一种便携式 UICC 卡用户终端设备及其身份
认证系统
(57) 摘要
本发明属于智能卡技术领域。本发明公开了
一种便携式 UICC 卡用户终端设备及其身份认证
方法和系统。通过充分利用 UICC 卡在用户身份
认证中的安全性和无线通信在用户使用过程中的
方便性，使得用户的身份认证在保持安全的同时，
使用更为方便。用户在使用过程中不需要提供用
户密码，也不需要把 UICC 卡提供给业务部门供查
验。其身份认证的安全性和现有的接触式 IC 卡是
等同的，还省略了读卡器设备。可以替代现有互联
网中广泛使用的“用户名 - 密码”身份认证方式，
在不需要用户密码的同时大大地提高了用户身份
认证的安全性。可穿戴式的用户终端设备更进一
步地加强了设备安全性和使用方便性。

(51)Int.Cl.

(19)中华人民共和国国家知识产权局

## (12)发明专利申请

权利要求书3页 说明书9页 附图2页

(10)申请公布号 CN 104410968 A
(43)申请公布日 2015.03.11

CN 104410968 A

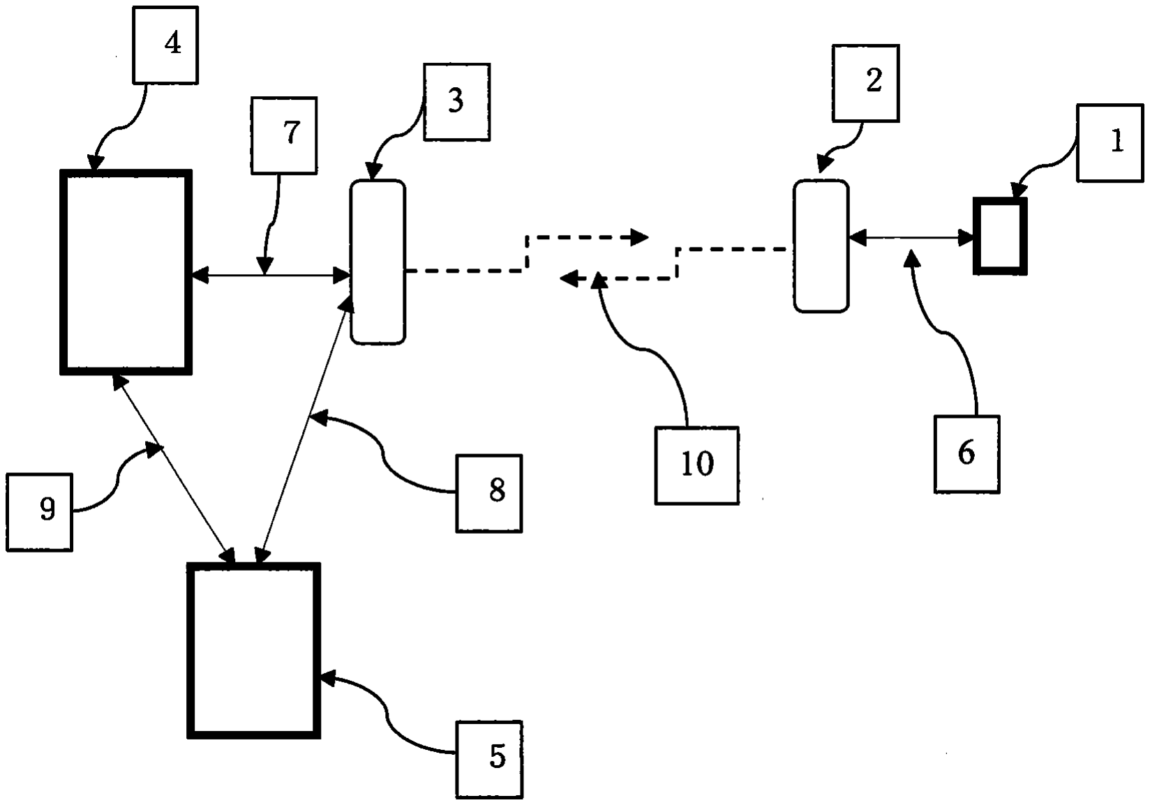
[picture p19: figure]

1/3 页

1. 一种基于通用集成电路卡 (UICC 卡，IC 卡 ) 的用户身份认证系统，其特征在于 ：上述 用户身份认证系统包括如下功能模块 ：
1) 用户身份标识 IC 卡，
2) 具有无线通信功能的可穿戴式的用户 IC 卡接口设备，
3) 网络接口设备，
4) 用户身份认证服务器，
5) 用户数据服务器。
2. 根据权利要求 1 所述的用户 IC 卡接口设备，其特征在于 ：上述用户 IC 卡接口设备 具有如下功能模块 ：
1) 接触式 IC 卡读卡接口，使得用户身份标识 IC 卡能够插入该设备中，并能够读取 IC 卡的相关数据，
2) 无线通信模块，能够通过无线传输方式 ( 或者通过无线通信和其它有线通信相结合 的传输方式 ) 把从用户身份标识 IC 卡读取的数据传送给网络云端服务器，也能够把网络云 端服务器的数据传送给用户身份标识 IC 卡，
3) 安全控制模块，能够提供用户 IC 卡接口设备和网络云端服务器的通信安全性和用 户身份标识 IC 卡内部数据的访问安全性，
4) 能源供应模块如电池等，使得用户 IC 卡接口设备成为一个移动设备而可以独立工 作，
5) 便于用户随身携带的配件如腕表式携带的表带等，成为可穿戴式设备而和用户随时 随地同在，加强设备本身的安全性。
3. 根据权利要求 1 所述的网络接口设备，其特征在于 ：上述网络接口设备具有如下功 能模块 ：
1)无线通信模块，提供无线通信连接于用户IC卡接口设备，使得用户IC卡接口设备能 够方便地连接于网络身份认证服务器，完成用户身份认证过程，
2) 连接于用户身份认证服务器，能够把用户身份认证服务器的数据转发给用户 IC 卡 接口设备，也能够把用户 IC 卡接口设备的数据转发给用户身份认证服务器，
3) 连接于用户数据服务器，在需要的时候能够读取与用户身份相关联的业务数据。
4. 根据权利要求 1 所述的用户身份认证系统，其特征在于 ：上述用户身份认证系统中 的用户身份标识 IC 卡和用户身份认证服务器有一个用户数据的初始化过程，在用户开始 使用用户身份标识 IC 卡之前就需要完成所述用户数据的初始化过程，上述初始化过程包 括 ：
1) 在用户身份标识 IC 卡和用户身份认证服务器中都写入一个唯一的用户身份号码， 用户 ID 号，这个用户 ID 号不需要保密，是公开的，任何第三方在需要的时候，获得适当的授 权后就可以获得，
2) 在用户身份标识 IC 卡和用户身份认证服务器中都写入一个能够标识业务服务提供 部门的业务 ID 号，该业务 ID 号不需要保密，是公开的，
3) 在用户身份标识 IC 卡和用户身份认证服务器中都写入一个由业务服务提供部门提 供的，唯一的，高度保密的身份认证密码 Kw，Kw 只能在用户身份认证服务器内部被用户身 份认证服务器读取，或者在用户身份标识 IC 卡内部被用户身份标识 IC 卡读取，任何第三方
CN 104410968 A | 权 利 要 求 书

2/3 页

都不能读取，
4) 在用户身份标识 IC 卡和用户身份认证服务器中都写入一个由用户提供的，唯一的， 高度保密的身份认证密码 Ky，Ky 只能在用户身份认证服务器内部被用户身份认证服务器 读取，或者在用户身份标识 IC 卡内部被用户身份标识 IC 卡读取，任何第三方都不能读取，
5) 在用户身份标识 IC 卡和用户身份认证服务器中都写入一个由业务服务提供部门提 供的，高度保密的加密算法 Am，Am 只能在用户身份认证服务器内部被用户身份认证服务器 读取，或者在用户身份标识 IC 卡内部被用户身份标识 IC 卡读取，任何第三方都不能读取， Am 的输入数据包括 Kw，Ky 和一个在使用的时候才生成的，一次性使用的随机数序列 Ri，而 其输出的数据则是一个身份认证鉴权数据序列 Si。
5. 根据权利要求 4 所述的用户数据的初始化过程，其特征在于 ：上述用户数据的初始 化数据的写入只能在特定的地点，用特定的设备写入需要保密的数据，包括身份认证密码 Kw，Ky 和加密算法 Am，任何第三方都不能改写这些数据，也不能读取这些数据，这种安全性 保障是通过用户身份标识 IC 卡和用户身份认证服务器设备本身提供的。
6. 根据权利要求 1 所述的用户身份认证系统，其特征在于 ：上述用户身份认证系统通 过如下的步骤完成对用户的身份认证鉴权过程 ：
1) 用户 IC 卡接口设备读取存储在用户身份标识 IC 卡中的用户 ID 号，并通过网络接口 设备，把用户 ID 号传送给用户身份认证服务器，申请用户身份认证， 2)用户身份认证服务器收到用户ID号后，读取自身的安全数据库，得到该用户ID号所 对应的用户身份认证密码 Kw 和 Ky，与此同时，生成一个临时的，一次性使用的随机数序列 Riw，
3) 在用户身份认证服务器内部运行加密算法 Am，以 Kw，Ky 和临时生成的随机数序列 Riw 为输入，得到一个用户身份认证鉴权数据序列 Siw，存储于用户身份认证服务器，等待 使用，
4) 用户身份认证服务器把随机数序列 Riw，通过网络接口设备传送给用户 IC 卡接口设 备，用户 IC 卡接口设备再把 Riw 传送给用户身份标识 IC 卡， 5)用户身份标识IC卡收到随机数序列Riw后，读取存储于其内部的用户身份认证密码 Kw 和 Ky，并在 IC 卡内部运行加密算法 Am，得到用户端的身份认证鉴权数据序列 Siy，
6) 用户 IC 卡接口设备读取用户身份标识 IC 卡生成的用户身份认证鉴权数据序列 Siy，并通过网络接口设备，传送给用户身份认证服务器，
7) 用户身份认证服务器收到身份认证鉴权数据序列 Siy 后，和自己先前生成的数据序 列 Siw 进行对比，如果一致，则完成对用户的身份认证过程，确认该用户 ID 号是真实的可信 用户，如果不一致，则中断用户的身份认证过程，拒绝提供进一步的服务，
8) 用户身份认证服务器通过网络接口设备以及用户 IC 卡接口设备，发送确认消息给 用户身份标识 IC 卡，通知其网络云端的用户身份认证过程已完成，并提供其自身的业务 ID 号，通知用户身份标识 IC 卡可以启动对网络的身份认证， 9)用户身份标识IC卡在收到确认消息后，在IC卡内部生成一个临时的，一次性使用的 随机数序列 Rjy，并通过用户 IC 卡接口设备，网络接口设备传送给用户身份认证服务器，
10) 用户身份标识 IC 卡在其内部运行加密算法 Am，以 Kw，Ky 和 Rjy 为输入数据，生成 一个网络身份认证鉴权数据序列 Sjy，存储于用户身份标识 IC 卡内部，等待使用，
CN 104410968 A | 权 利 要 求 书

3/3 页

11) 用户身份认证服务器收到随机数序列 Rjy 后，读取自身的安全数据库，得到该用户 ID 号所对应的用户身份认证密码 Kw 和 Ky，
12) 在用户身份认证服务器内部运行加密算法 Am，以 Kw，Ky 和收到的 Rjy 为输入数据， 生成一个网络身份认证鉴权数据序列 Sjw，
13) 用户身份认证服务器通过网络接口设备以及用户 IC 卡接口设备，把自己生成的数 据序列 Sjw 传送给用户身份标识 IC 卡，
14) 用户身份标识 IC 卡收到数据序列 Sjw 后，和自身先前生成的网络身份认证鉴权数 据序列 Sjy 进行对比，如果一致，则完成对业务网络的身份认证，如果不一致，则中断对网 络的身份认证过程，拒绝和网络的进一步连接和数据交换，
15) 用户身份标识 IC 卡在完成对业务网络的身份认证后，通过用户 IC 卡接口设备，网 络接口设备，发送消息给用户身份认证服务器，确认对业务网络的身份认证，
16) 用户身份的认证鉴权过程完成后，用户身份认证服务器发送确认消息给网络接口 设备和用户数据服务器，可以使用和该用户 ID 号所对应的业务数据，
17) 在使用业务数据的时候，用户可选地使用附加的业务密码，进一步加强业务数据的 使用安全性。
7. 根据权利要求 1 所述的用户 IC 卡接口设备的无线通信功能模块，其特征在于 ：上述 无线通信模块是蓝牙 (Bluetooth) 通信功能模块。
8. 根据权利要求 1 所述的用户 IC 卡接口设备的无线通信模块，其特征在于 ：上述无线 通信模块是能够接入蜂窝移动通信网络的 2G 通信系统如 GSM/GPRS/EDGE，CDMA 等，3G 通信 的 WCDMA，CDMA2000，TD-SCDMA 等通信系统，LTE FDD，TD-LTE 等 4G 移动通信系统的通信功 能模块。
9. 根据权利要求 1 所述的用户 IC 卡接口设备的无线通信模块，其特征在于 ：上述无线 通信模块是无线局域网 (WLAN，WiFi) 通信功能模块。
10. 根据权利要求 3 所述的网络接口设备的无线通信模块，其特征在于 ：上述无线通信 模块提供一种或多种的无线通信连接方式，包括蓝牙通信，无线局域网通信，蜂窝移动通信 广域网络的移动互网接入，使得如根据权利要求 2 所述的用户 IC 卡接口设备能够方便的连 接于用户身份认证服务器。
CN 104410968 A | 权 利 要 求 书

1/9 页

一种便携式 UICC 卡用户终端设备及其身份认证系统

技术领域
[0001] 本发明属于智能卡 ( 也称芯片卡，UICC 卡，IC 卡 ) 技术领域。具体地说，本发明涉 及一种使用方便并安全的用户身份认证设备及方法，同时也涉及适用于这种用户身份认证 的网络云端系统及其身份认证鉴权协议。

背景技术
[0002] 目前，通用集成电路卡 (UICC，Universal Integrated Circuit Card，简称 IC 卡 ) 广泛应用于用户的身份认证系统。如移动通信系统的 SIM 卡和 USIM 卡，银行系统中用户帐 户数据的金融IC卡，还包括各种社会保障卡如医保卡和公民的居民身份证系统。由于IC卡 采用集成电路技术，使得其内部可以具有独立的 CPU( 中央处理器 )，存储系统和通信接口， 其安全性得到大大增强。同时，由于 IC 卡的标准化和小型化，也利于随身携带，其使用也更 为方便。
[0003] 根据 IC 卡和读卡器之间的信息交换方式，可以分为接触式 IC 卡和非接触式 IC 卡。然而，无论是接触式还是非接触式 IC 卡，都需要用户的 IC 卡和读卡器配合，才能完成 用户的身份认证 ( 非接触式 IC 卡和读卡器一般也需要 5mm-10mm 的距离 )。例如，用户的银 行账户的金融 IC 卡需要插入银行系统的读卡器，才能获得用户信息。这种用户身份标识 IC 卡和业务服务提供部门的读卡器之间需要物理地近距离接触的使用方式，给用户的使用带 来一定程度的不方便。用户在使用业务时，需要前往业务服务提供部门，用专业的读卡器， 读取用户的 IC 卡数据。这样，IC 卡的安全性和用户的使用方便性不能很好的共存，也不能 满足人们在不同应用场景的使用需求。
[0004] 随着移动互联网和智能终端 ( 如智能手机，平板电脑等 ) 的发展，其应用也越来越 深入人们生活的各个方面。例如手机钱包，使得人们可以随时随地完成移动支付而不需要 使用现金，银行卡或者其他实体的支付凭证，给人们的日常生活带来极大的方便。作为用户 的身份认证方式，在互联网系统中广泛使用的是“用户名 - 密码”的登陆方式，其唯一的用 户身份标识就是登陆密码 ( 用户名作为公开的信息可以很容易地获得 )。也就是说，只要用 户能够正确地输入密码，就认为该用户是真实的合法用户。
[0005] 这种“用户名 - 密码”的身份认证方式有其固有的不安全性和使用的不方便性。一 方面，如果用户的登陆密码被泄露，这种用户身份认证方式就毫无安全性可言，任何人都可 以使用其密码而冒充真实的用户。另一方面，用户需要记住密码，使得每次使用的时候能够 被正确地认证。安全性需要密码越复杂越好，但是用户对密码记忆的方便性却是越简单越 好。安全的登陆密码的复杂性，难记忆性和用户使用的方便性成为了一对矛盾，不可能同时 兼顾。用户在每次使用业务时，需要输入密码以供身份验证，这种多次地重复使用相同的密 码也增加了密码泄露的风险。在不同业务系统中的不同用户密码也增加了用户记忆密码的 难度。
[0006] 尽管“用户名 - 密码”的身份认证方式有着天然的不安全性，但从实际的使用情况 看来，人们往往选择了方便性，而忽略了安全性。使用简单的密码，方便地完成用户身份认
CN 104410968 A | 说 明 书

证。这样的使用方式存在极大的安全隐患，特别和用户的个人金融等唯一身份认证信息相 关联的时候，这种安全性就显得更为重要。所以，提供一种用户方便使用的，同时又具有充 分安全性保障的用户身份认证方式就显得非常重要。
[0007] 在现有市场中，有一种消除用户对“用户名 - 密码”身份认证的安全性顾虑的方 式，即“用户资金安全保障”的附加保险。如果用户由于使用“用户名 - 密码”的方式使得 其身份被盗用，使得其账户资金有损失，可以得到资金损失赔付。从用户的角度来看，好像 足解决了其安全性问题。但足，这实际上只是一种风险转移，并没有解决其安全性问题，并 且这种风险转移的成本最终还是由用户支付。
[0008] 在现有市场中，还有一种利用用户的生物特征如指纹等作为用户身份认证的标 识。这种身份认证方式很好的解决了用户身份认证的唯一性问题。但是，由于用户的生物 特征是有变化的，这种身份认证方式就存在识别的准确性和确定性问题。在用户的生物特 征发生变化时，就不能很好的识别用户。在以确定性为基础的计算机和网络系统中，需要一 种确定的唯一身份标识。并且用户的生物特征如指纹等也有可能被复制，进而使用复制的 身份数据，假冒真实的用户而使用用户的业务数据，存在安全性隐患。
[0009] 本发明的核心功能就是公开了一种安全的，方便使用的用户身份认证设备，方法 和系统。用户相关的具体业务信息，如用户在银行的账户信息，在医院的身体健康信息都存 储在网络云端，而用户只需要提供唯一的，不可更改和复制的身份信息，就可以获得与此用 户身份相关联的业务信息。用户不需要提供密码，也不需要把用于身份标识的 IC 卡提供给 具体的业务部门 ( 如银行等 ) 供验证。大大地方便了用户的使用，也极大地提高了用户数 据的安全性。

发明内容
[0010] 本发明的关键之处在于综合利用 IC 卡在用户身份认证中的安全性和无线通信在 用户使用中的方便性，为用户和具体的业务提供部门提供一种安全的，方便的用户身份认 证设备，方法和系统。
[0011] 本发明的用户身份认证系统包括如下部分 ：
[0012] 1) 用户身份标识 IC 卡。主要是接触式 IC 卡，提供通信传输接口，其通信数据接口 满足智能卡传输协议 ISO-7816 标准。在其内部的存储系统中，根据使用的需要，有一个或 者多个存储区域，每一个存储区域存储有具体的与不同业务相关联的用户身份标识相关信 息。每一个存储区域的数据访问受到安全控制，需要相应的业务授权才能访问。存储区域 之间的数据互相访问也需要相应的授权。每一个存储区域的数据满足不同业务的数据格式 标准，例如，用于移动通信的用户身份标识的 SIM/USIM 卡满足 ETSI TS 102.211，3GPP TS 31.101，3GPP TS11.11 等标准 ；用于银行帐户的用户身份标识的金融 IC 卡满足金融 IC 卡 的标准 ISO-10202 等。
[0013] 2) 用户 IC 卡接口设备。主要完成用户身份标识 IC 卡数据的读取和传输，有如下 的功能模块 ：
[0014] a)接触式IC卡读卡接口，使得用户身份标识IC卡能够插入该设备中，并能够读取 IC 卡的相关数据。其读卡接口满足 ISO-7816 传输协议标准。
[0015] b) 无线通信模块，能够通过无线传输方式 ( 或者无线和有线相结合的传输方式 )

把从用户身份标识 IC 卡读取的数据传送给网络云端服务器，也能够把网络云端服务器的 数据传送给用户身份标识 IC 卡。
[0016] c) 安全控制模块，主要是确保用户 IC 卡接口设备和网络云端服务器之间的通信 安全性和用户身份标识 IC 卡数据的访问安全性。
[0017] d) 能源供应模块如电池等，主要是使得用户 IC 卡接口设备成为一个移动设备而 和用户随时随地同在，增加使用的方便性。
[0018] e) 便于用户随身携带的配件如腕表式携带的表带等，成为可穿戴式设备而不容易 被丢失，进一步加强设备的安全性。
[0019] 3) 网络接口设备。主要是连接网络云端服务器和用户 IC 卡接口设备，能够把云端 服务器的数据转发给用户 IC 卡接口设备，也能够把用户 IC 卡接口设备的数据转发给网络 云端服务器。有如下的功能模块 ：
[0020] a) 连接于用户身份认证服务器，该服务器能够完成对用户的身份认证。
[0021] b) 连接于用户数据服务器，在需要的时候能够读取与用户身份相关联的业务数 据。
[0022] c) 无线通信模块，提供无线通信连接 ( 或者无线通信和有线通信相结合 ) 使得用 户 IC 卡接口设备能够方便地连接于网络身份认证服务器，完成用户身份认证过程。
[0023] 4) 用户身份认证服务器。主要是能够安全地完成对用户的身份认证，确保用户身 份的真实性 ；并能够被用户身份标识 IC 卡认证，使得用户确信是接入一个真实的网络，而 不是一个虚假的冒充网络。有如下的功能模块 ：
[0024] a) 连接于网络接口设备，使得用户身份认证服务器和用户身份标识 IC 卡能够建 立可靠而安全的通信连接。它们之间的通信连接时通过网络接口设备，用户 IC 卡接口设备 的转接完成的。
[0025] b) 连接于用户数据服务器，使得用户的业务数据和用户的身份标识能够建立起唯 一的对应关系。在需要的时候，能够根据用户的身份标识 ID 号得到其相应的业务数据。
[0026] c) 用户身份认证鉴权模块，能够安全地完成对用户的身份认证，确保用户身份的 真实性。这种对用户身份的认证主要是通过对用户身份标识 IC 卡内的数据完整性，算法的 真实性的确认来完成的。
[0027] d) 网络自身业务的身份标识模块，能够被用户身份标识 IC 卡认证，使得用户确信 是接入一个真实的网络，而不是一个虚假的冒充网络。
[0028] 5)用户数据服务器。主要存储用户的业务数据，确保真实用户的合法数据访问，并 拒绝假冒用户的非法数据访问。有如下的功能模块 ：
[0029] a) 连接于网络接口设备，在需要的时候提供用户的具体业务数据。
[0030] b) 连接于用户身份认证服务器，使得用户的业务数据和用户的身份标识能够建立 起唯一的对应关系。
[0031] c) 数据访问安全控制模块，使得在任何情况下对用户的业务数据的访问，都必须 在用户身份被正确地认证鉴权后，在用户身份认证服务器的授权下才能进行。
[0032] 通过如上所述的各个功能部分的协同工作，为用户和具体的业务部门 ( 如银行， 医院，电信等 ) 提供方便的，安全的用户身份认证服务。其具体的过程可以分为两个主要部 分，包括用户身份标识 IC 卡数据的初始化和用户身份的真实性认证。

[0033] 用户身份标识 IC 卡数据的初始化过程包括 ：
[0034] 1) 根据业务的需要，在用户身份标识 IC 卡内的存储设备中，选择一个存储区域， 与此业务相关的用户身份标识信息都只存储在该区域中。并且对该区域的数据访问受到安 全性控制，不同的数据具有不同访问权限。有些安全性敏感数据甚至不能被外部设备读取， 只能在 IC 卡内部被 IC 卡自身读取。
[0035] 2) 用户需要使用业务部门提供的服务时，业务服务提供部门分配给用户一个唯一 的业务用户身份号码，称为用户 ID 号。根据业务需要，用户 ID 号可以是全球唯一的，也可 以是区域性唯一的，也可以重用其他业务的用户 ID 号 ( 如居民身份证号码等 )。其主要目 的是和使用该业务的其他用户号码唯一地区分。当然，这种用户 ID 号的编码方式中，可以 提供一些额外的信息，如快速地定位为用户身份标识 IC 卡提供身份认证服务的网络云端 服务器的信息。这个用户 ID 号不需要保密，是公开的，任何第三方在需要的时候，获得适当 的授权后就可以获得。用户 ID 号在用户身份标识 IC 卡数据的初始化过程中被写入 IC 卡 中，能够被用户 IC 卡接口设备读取，并在需要的时候传送给网络云端服务器。
[0036] 3) 业务服务提供部门为用户提供一个其自身的业务 ID 号。同用户 ID 号一样，这 个业务 ID 号也不需要保密，是公开的。在用户身份标识 IC 卡数据的初始化过程中，这个业 务 ID 号被写入用户身份标识 IC 卡中，能够被用户 IC 卡接口设备读取。
[0037] 4) 在用户身份认证服务器上，分配给用户一个唯一的身份认证密码 Kw。Kw 和用户 ID 号是一一对应的，不同的用户具有不同的 Kw。并且 Kw 是高度保密的，作为一个高度机密 的商业秘密被业务服务提供部门保存。只能被用户身份认证服务器读取，任何第三方，包括 用户本人都不能读取。在用户身份标识 IC 卡数据的初始化过程中，Kw 被用户身份认证服务 器写入用户身份标识 IC 卡中。这种写入是一次性的，不能被改写，只能在需要的时候，由用 户身份认证服务器重新为用户分配一个新的 Kw，再重新写入用户身份标识 IC 卡。同样，写 入用户身份标识 IC 卡的 Kw 只能在 IC 卡的内部被 IC 卡读取，任何第三方，包括用户 IC 卡 接口设备都不能读取。这样，Kw 只共享于用户身份标识 IC 卡和用户身份认证服务器，成为 它们之间进行身份认证的安全性保障的一部分。Kw 具有足够的长度，使得它不可能通过遍 历的方式被猜测出来。
[0038] 5) 在用户身份标识 IC 卡数据的初始化过程中，用户通过安全的输入设备，输入一 个用户端的身份认证密码 Ky。同样 Ky 具有足够的长度，使得它不可能通过遍历的方式被猜 测出来。用户身份认证服务器接收 Ky 后，进行唯一性检查，确保用户 Ky 的唯一性。如果 Ky 不是唯一的，提示用户重新输入，直到 Ky 在整个业务中是唯一的为止。用户身份认证密码 Ky 也和用户 ID 号一一对应，以高度保密的方式存储于用户身份认证服务器上，并被用户身 份认证服务器写入用户身份标识 IC 卡，安全地存储于 IC 卡中。任何第三方包括业务服务 提供部门，都不能读取 Ky，只能在网络云端被用户身份认证服务器读取，或者只能在 IC 卡 的内部被 IC 卡读取。Ky 虽然是用户输入的，但用户并不需要记住 Ky，并且由于其复杂性， 大多数情况下很快就会被用户忘记。Ky 只是在初始化阶段一次性地输入，或者在需要的时 候重复如上所述过程而重新输入一个新的 Ky，而不需要用户在每次使用业务时重复输入， 大大加强了 Ky 的保密性。和 Kw 一样，Ky 只共享于用户身份标识 IC 卡和用户身份认证服 务器，成为它们之间进行身份认证的安全性保障的一部分。
[0039] 6) 业务服务提供部门提供一个用户身份认证鉴权的加密算法 Am，作为一个高度

机密的商业秘密被业务服务提供部门保存。在用户身份标识 IC 卡数据的初始化过程中， 加密算法 Am 被写入用户身份认证服务器和用户身份标识 IC 卡中，并被安全的存储。同 Kw 和 Ky 一样，加密算法 Am 不能被任何第三方读取，只能在网络云端被用户身份认证服务器读 取，或者只能在 IC 卡的内部被 IC 卡读取。加密算法 Am 的输入数据包括 Kw，Ky 和一个临时 生成的随机数序列 Ri，而其输出的数据则是一个身份认证鉴权数据序列 Si。除了业务服务 提供部门，加密算法 Am 只共享于用户身份标识 IC 卡和用户身份认证服务器，成为它们之间 进行身份认证的安全性保障的一部分。
[0040] 7)在整个用户身份标识IC卡数据的初始化过程中，为了加强安全性数据Kw，Ky和 Am 的保密性，其生成和写入应当在特定的地点，用特定的设备写入。避免通过数据的传输， 以远程的方式写入。减少在数据传输过程中安全性数据泄露的风险。由于这种写入是一次 性的，并没有增加用户或者业务服务提供部门在使用过程中的复杂性。
[0041] 当用户身份标识 IC 卡完成数据的初始化后，就可以提供给用户使用。用户身份标 识 IC 卡插入用户 IC 卡接口设备，而用户 IC 卡接口设备可以作为可穿戴设备而和用户随时 随地同在。这样，用户身份标识 IC 卡就作为一个物理的实体凭证而和用户随时随地同在， 用于标识用户的身份ID。而作为可穿戴设备，就不容易被用户丢失，同时也提高了用户身份 标识 IC 卡的物理安全性。
[0042] 当用户需要身份认证的时候，通过如下的步骤完成用户身份的认证鉴权过程 ：
[0043] 1) 用户 IC 卡接口设备读取存储在用户身份标识 IC 卡中的用户 ID 号，并通过网络 接口设备，把用户 ID 号传送给用户身份认证服务器，申请用户身份认证，以确认使用该用 户 ID 号的用户确实是真实合法的用户。
[0044] 2) 用户身份认证服务器收到用户 ID 号后，读取自身的安全数据库，得到该用户 ID 号所对应的用户身份认证密码 Kw 和 Ky。与此同时，生成一个临时的，一次性使用的随机数 序列 Riw。
[0045] 3) 在用户身份认证服务器内部运行加密算法 Am。以 Kw，Ky 和临时生成的随机数 序列 Riw 为输入，得到一个用户身份认证鉴权数据序列 Siw，存储于用户身份认证服务器， 等待使用，以完成对用户的身份认证。
[0046] 4) 用户身份认证服务器把随机数序列 Riw，通过网络接口设备传送给用户 IC 卡接 口设备，用户 IC 卡接口设备再把 Riw 传送给用户身份标识 IC 卡。
[0047] 5)用户身份标识IC卡收到随机数序列Riw后，读取存储于其内部的用户身份认证 密码 Kw 和 Ky，并在 IC 卡内部运行加密算法 Am，得到用户端的身份认证鉴权数据序列 Siy。 由于使用了和用户身份认证服务器端相同的加密算法 Am，也使用了相同的 Kw 和 Ky，以及相 同的随机数序列 Riw，所以得到的身份认证鉴权数据序列 Siy 就和用户身份认证服务器的 用户身份认证鉴权数据序列 Siw 是一致的。并且由于加密算法 Am，用户身份认证密码 Kw 和 Ky 只是共享于用户身份标识 IC 卡和用户身份认证服务器，任何第三方即使窃取到随机数 序列 Riw，也不可能的到相同的用户身份认证鉴权数据序列 Siy。另一方面，随机数序列 Riw 是一次性使用的，每次进行用户身份标识认证的鉴权数据序列 Siy 就是不同的，所以，即使 鉴权数据序列 Siy 被泄露，对用户以后的身份标识认证也没有任何影响。
[0048] 6) 用户 IC 卡接口设备读取户身份标识 IC 卡生成的用户身份认证鉴权数据序列 Siy，并通过网络接口设备，传送给用户身份认证服务器。

[0049] 7) 用户身份认证服务器收到身份认证鉴权数据序列 Siy 后，和自己先前生成的数 据序列 Siw 进行对比。如果一致，则完成对用户的身份认证过程，确认使用该用户 ID 号的 用户是真实的合法可信用户。如果不一致，则中断用户的身份认证过程，拒绝提供进一步的 服务。
[0050] 8) 用户身份认证服务器通过网络接口设备以及用户 IC 卡接口设备，发送确认消 息给用户身份标识 IC 卡，通知其网络云端的用户身份认证过程已完成。并提供其自身的业 务 ID 号，通知用户身份标识 IC 卡可以启动对网络的身份认证。防止用户接入虚假的冒充 网络。
[0051] 9) 用户身份标识 IC 卡在收到确认消息后，启动对网络的业务 ID 身份认证。在 IC 卡内部生成一个临时的，一次性使用的随机数序列 Rjy，并通过用户 IC 卡接口设备，网络接 口设备传送给用户身份认证服务器。
[0052] 10) 用户身份标识 IC 卡在其内部运行加密算法 Am，以 Kw，Ky 和 Rjy 为输入数据， 生成一个网络身份认证鉴权数据序列 Sjy。存储于用户身份标识 IC 卡内部，等待使用，以完 成对用户身份认证服务器的身份认证。
[0053] 11) 用户身份认证服务器收到随机数序列 Rjy 后，读取自身的安全数据库，得到该 用户 ID 号所对应的用户身份认证密码 Kw 和 Ky。
[0054] 12) 在用户身份认证服务器内部运行加密算法 Am，以 Kw，Ky 和收到的 Rjy 为输入 数据，生成一个网络身份认证鉴权数据序列 Sjw。
[0055] 13) 用户身份认证服务器通过网络接口设备以及用户 IC 卡接口设备，把自己生成 的数据序列 Sjw 传送给用户身份标识 IC 卡。
[0056] 14) 用户身份标识 IC 卡收到数据序列 Sjw 后，和自身先前生成的网络身份认证鉴 权数据序列 Sjy 进行对比。如果一致，则完成对业务网络的身份认证，确信接入的是一个真 实的合法业务网络。如果不一致，则中断对网络的身份认证过程，拒绝和网络的进一步连接 和数据交换。
[0057] 15) 用户身份标识 IC 卡在完成对业务网络的身份认证后，通过用户 IC 卡接口设 备，网络接口设备，发送消息给用户身份认证服务器，确认对业务网络的身份认证。
[0058] 16) 整个用户身份的认证鉴权过程完成后，用户身份认证服务器发送消息给网络 接口设备和用户数据服务器，授权可以进一步使用和该用户 ID 号所对应的业务数据。
[0059] 17) 在使用业务数据的时候，用户可以使用附加的业务密码，进一步加强业务数据 的使用安全性。当然，由于最重要的身份的认证鉴权过程已经完成，这个附加的业务密码是 可选的。
[0060] 在整个身份认证鉴权过程中，由于加密算法和身份认证密码只存在于网络的两 端，并不需要在它们之间传送，极大地提高了身份认证鉴权的安全性。即使用于身份认证 的数据 (Ri，Si) 在传输过程中有泄漏，得到数据的任何第三方也无法完成身份认证鉴权过 程，并对用户以后的身份认证鉴权过程没有任何影响。
[0061] 由于用户 IC 卡接口设备和网络接口设备之间的通信连接是无线通信，或者是有 线和无线通信的结合，使得在用户端的使用变得非常方便。用户不需要把用户身份标识 IC 卡插入或者靠近业务服务提供部门的读卡器设备，就能够完成用户身份认证。例如这种无 线通信可以是短距离的蓝牙通信，其通信范围可以是几十米。在银行或者医院的服务大厅

的任何一个地方就可以接入其业务网络，完成用户身份认证和网络的身份认证。这种无线 通信也可以是广域网的蜂窝式移动通信网络和有线的互联网的结合，在世界的任何一个地 方就可以接入其业务网络，完成用户身份认证和网络的身份认证。并不需要用户身份标识 IC 卡和业务服务提供部门的读卡器的物理近距离接触，使得新兴的互联网业务服务提供部 门可以快速的开展业务，即使没有大规模的业务服务网点。
[0062] 发明的效果
[0063] 在本发明的技术实施方案中，充分利用了 UICC 卡在用户身份认证中的安全性和 无线通信在用户使用过程中的方便性，成功地兼顾了在用户业务数据使用过程中的安全性 和方便性。其身份认证的安全性和现有的接触式 IC 卡是等同的，并且对现有的业务数据和 IC 卡身份数据没有任何影响，只需要增加与身份认证相关的设备，如用户身份认证服务器， 网络接口设备和用户 IC 卡接口设备。对历史的业务数据可以很好的继承和使用，同时省略 了业务服务提供部门的读卡器设备。本发明的身份认证方法可以替代现有互联网络 ( 包括 固定的因特网和移动互联网 ) 中广泛使用的“用户名 - 密码”身份认证方式，从而加强用户 身份认证的安全性，促进与用户身份认证相关的业务如移动金融的发展。

附图说明
[0064] 图 1 是本发明的各个功能模块示意图和它们之间的通信连接图。模块 1 是 UICC 卡，即用户身份标识 IC 卡。模块 2 是用户 IC 卡接口设备，该模块可以是一个可穿戴的移动 设备，并且通常情况下模块 1 是插入模块 2 中，方便用户的移动使用。模块 3 是网络接口设 备，模块 4 是用户身份认证服务器，模块 5 是用户数据服务器。模块 1 和模块 2 通过模块 6 进行通信连接，它们之间的数据传输是现有标准的接触式 UICC 卡传输协议。模块 3 和模块 4 之间通过模块 7 进行通信连接，可以是有线通信，也可以是无线通信，由具体的业务服务 提供部门决定和提供。模块 3 和模块 5 通过模块 8 进行通信连接，模块 4 和模块 5 通过模 块 9 进行通信连接。同模块 7 一样，模块 8 和模块 9 可以是有线通信，也可以是无线通信， 由具体的业务服务提供部门决定和提供。无线传输通信模块 10 提供模块 2( 用户 IC 卡接 口设备 ) 和模块 3( 网络接口设备 ) 之间的连接，为用户接入具体业务服务网路提供方便的 通信连接。当然，通信模块 10 也可以是无线通信和有线通信的结合，主要是在用户端 ( 模 块 2，用户 IC 卡接口设备 ) 提供无线通信连接，方便用户的使用。
[0065] 图 2 是本发明的用户身份标识 IC 卡的数据初始化过程。包括在用户身份认证服 务器和用户身份标识 IC 卡中同时写入用户 ID 号，业务 ID 号，网络端的身份认证密码 Kw，用 户端的身份认证密码 Ky，加密算法 Am。其中用户 ID 号和业务 ID 号是公开的，不需要保密。 而网络端的身份认证密码Kw，用户端的身份认证密码Ky和加密算法Am是高度保密的，只能 在用户身份认证服务器内部或者在用户身份标识 IC 卡内部被读取，任何外部设备都不能 读取这些安全性数据。
[0066] 图 3 是本发明的用户身份认证鉴权消息流程图。包括用户身份认证服务器对用户 身份标识 IC 卡的认证，确信使用该用户 ID 号的用户一个真实的合法用户。也包括用户身 份标识 IC 卡对用户身份认证服务器的认证，确信用户接入的是一个真实的合法业务网络， 而不是一个虚假的冒充网络。

具体实施方式
[0067] 根据不同的服务业务类型以及不同的无线通信方式，本发明的用户身份标识 IC 卡及其身份认证系统可以有不同的具体实施方式。下面就结合几个不同的具体实施例子来 进一步对本发明进行说明。
[0068] 实施例子 1
[0069] 本实施例子的应用场景是用户身份标识 IC 卡为用户的银行账户，用户需要使用 的业务是在银行的自动取款机上支取其个人帐户的现金。
[0070] 作为用户个人银行账户的用户身份标识 IC 卡，在用户向银行申请金融业务服务 时，银行为用户设立银行账户，分配给用户一个唯一的个人银行账户号码，作为用户 ID 号， 写入用户的帐户金融 IC 卡。同时，也把银行自身的业务 ID 号写入用户的帐户金融 IC 卡。 用户的帐户 ID 号和银行的业务 ID 号作为公开的信息，可以用另外的书面形式提供给用户， 方便用户在使用银行业务时使用相关 ID 号。作为用户银行账户的安全性数据，银行提供给 用户的身份认证密码 Kw 和加密算法 Am 是在银行的业务窗口，用专门的写卡设备，写入用户 的账户金融 IC 卡。与此同时，用户通过银行业务窗口的密码键盘，输入用户的身份认证密 码 Ky，并确保 Ky 的唯一性，也用专门的写卡设备，写入用户的账户金融 IC 卡。在银行的后 台业务网络中，Kw，Ky 和 Am 也被安全的写入用户帐户身份认证服务器，并完成其它的业务 数据初始化。这样，用户的金融 IC 卡作为用户个人银行账户的用户身份标识 IC 卡，就可以 交付给用户使用。
[0071] 用户 IC 卡接口设备是一个腕表式设备，被用户穿戴而和用户随时随地同在。作为 银行账户的用户身份标识 IC 卡插入腕表中，也和用户随时随地同在。作为用户 IC 卡接口 设备的腕表具有无线蓝牙通信模块，银行的自动取款机上也具有无线蓝牙通信模块，它们 之间通过蓝牙通信能够建立起无线连接。
[0072] 作为联网设备，自动取款机具有另外一个通信链路连接于银行的后台网络系统， 包括用户帐户身份的真实性认证鉴权服务器，用于认证将要进行现金支取业务的用户是合 法真实的用户 ；也包括用户帐户数据服务器，存储有与用户帐户数据相关的信息，例如帐户 余额等。这样，自动取款机就提供了一个在本发明中的网络接口设备的功能。
[0073] 当用户靠近自动取款机，在蓝牙通信的有效距离范围内时，就可以操作腕表，使其 连接于自动取款机。或者根据用户预先的设定，腕表自动检测有效的自动取款机 ( 例如用 户经常使用的某个固定的自动取款机 )，并自动地建立蓝牙通信连接，完成双向的身份认证 鉴权过程，确保用户和网络双方都是合法真实有效的。这样，当用户到达自动取款机时，就 可以直接地支取现金，而不需要把作为自己的银行账户的金融 IC 卡插入自动取款机。甚至 连银行通常使用的取款密码也不需要，因为作为安全性检查的身份认证过程已经完成，其 安全性已经得到充分保障。当然，作为安全性补充，用户可以为现金支取业务设定一个业务 附加密码，在完成现金支取密码验证后才能支取现金，这就和现有的自动取款机业务一样 了。不过作为用户帐户身份的认证过程，已经大为简化了，极大地方便了用户的使用。在整 个现金支取业务过程中，用户也不用担心接入一个虚假的冒充网络，因为根据本发明的身 份认证鉴权机制，任何第三方的网络都不可能通过用户身份标识 IC 卡对网络的身份认证 过程。并且一旦用户在使用中 ( 或者银行的例行性安全检查中 ) 发现异常，银行能够迅速 行动，消除其安全隐患。同样，任何虚假的无效用户也不可能通过用户身份认证服务器对用

户的身份认证鉴权过程，保障了银行的自动取款机上的现金支取业务的安全性。
[0074] 这样，通过本发明的用户身份标识 IC 卡的认证方法，设备和系统，使得银行自动 取款机上的现金支取业务比现有的使用用户密码的方式更为安全。而另一方面，对用户的 使用来说，也更为方便，其取款过程也大为简化。
[0075] 实施例子 2
[0076] 本实施例子的应用场景是移动支付。同实施例子 1 一样，用户身份标识 IC 卡为用 户的银行账户。而用户需要使用的业务是在超市购物的支付结算。
[0077] 超市的支付结算系统在获得用户 ID 号后，连接于银行的账户系统，请求银行账户 系统从该用户 ID 号的帐户中划转结算资金。银行的用户身份认证服务器通过网络接口设 备 ( 连接于移动互联网的服务器 )，通过广域网的蜂窝式移动互联网 ( 例如，2G 通信系统 如 GSM/GPRS/EDGE，CDMA 等，3G 通信的 WCDMA，CDMA2000，TD-SCDMA 等通信系统，LTE FDD， TD-LTE 等 4G 移动通信系统 )，连接于用户的腕表，和用户的银行账户金融 IC 卡建立连接， 完成双向的身份认证鉴权过程，确保用户和网络双方都是合法真实有效的。然后银行的账 户数据服务器向用户发送支付消息，得到用户确认后，向超市的支付结算系统划转结算资 金。这样，在整个支付过程中，用户只需要确认支付，而没有其他任何额外的步骤，极大地 方便了用户的使用，移动支付过程也更为流畅。同时避免了在互联网中广为使用的“用户 名 - 密码”身份认证方式，其安全性也大为增强，同时保护了银行和用户双方的数据。
[0078] 另一方面，超市的支付结算系统可以提供网络接口设备的部分功能，其一方面连 接于银行的网络接口设备，另一方面具有短距离的无线蓝牙通信连接于用户的腕表。这样 超市的支付结算系统就是银行的网络接口设备和用户的 IC 卡接口设备之间的一个桥梁。 当银行的用户身份认证服务器完成身份认证鉴权后，超市的支付结算系统就可以收到确认 消息，能够直接收到银行的账户数据服务器的结算资金。这样，连用户的支付确认步骤都可 以省略，其使用也更为方便流畅。例如，当用户完成购物后，或者在购物过程中，直接通过超 市的远距离支付结算系统，自动地完成购物支付，而不需要在超市的收银台作任何停留，用 户的购物体验也更为完美。

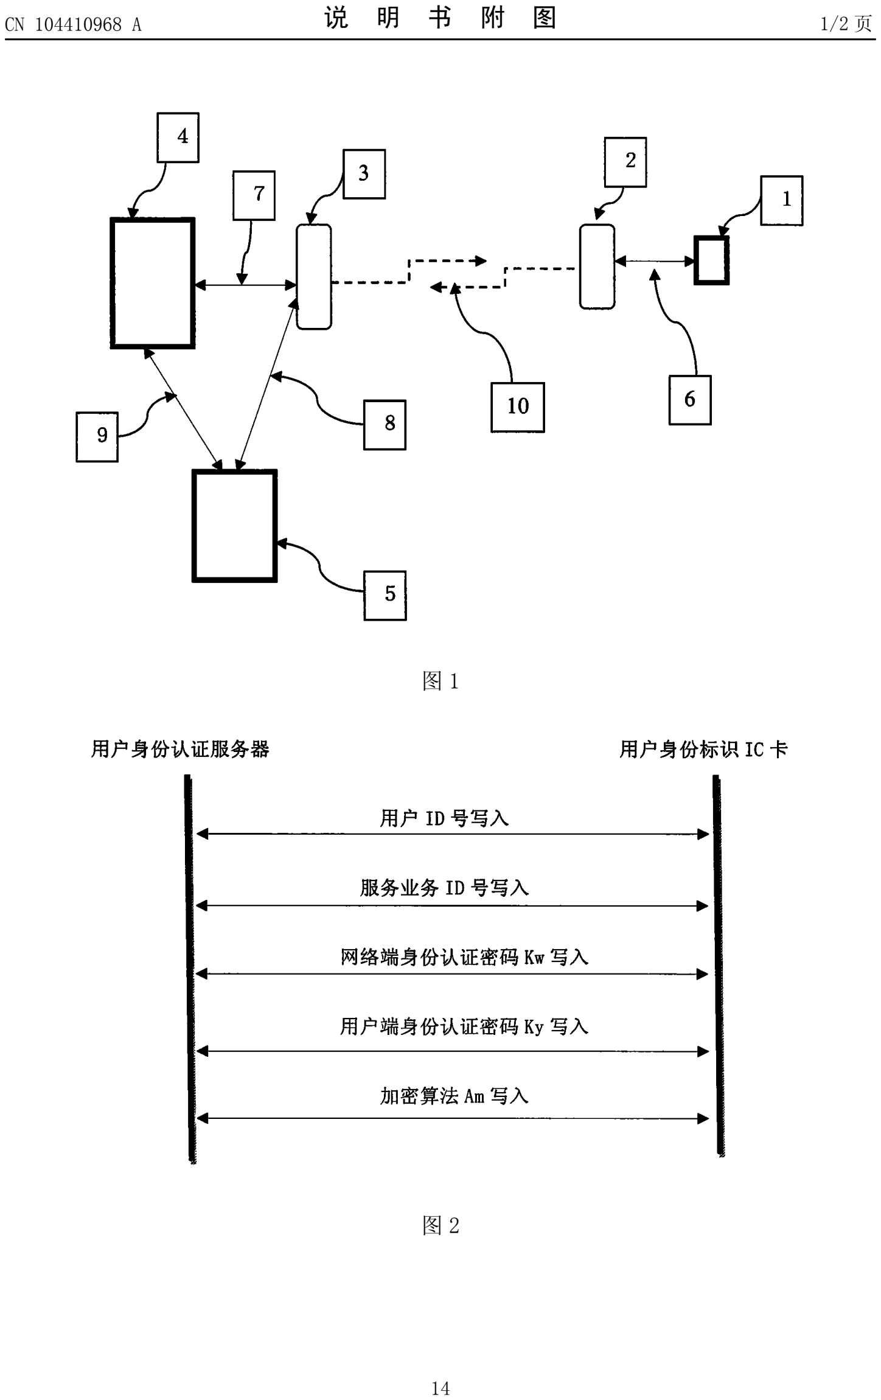
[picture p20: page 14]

1/2 页

图 1

图 2

CN 104410968 A | 说 明 书 附 图

2/2 页

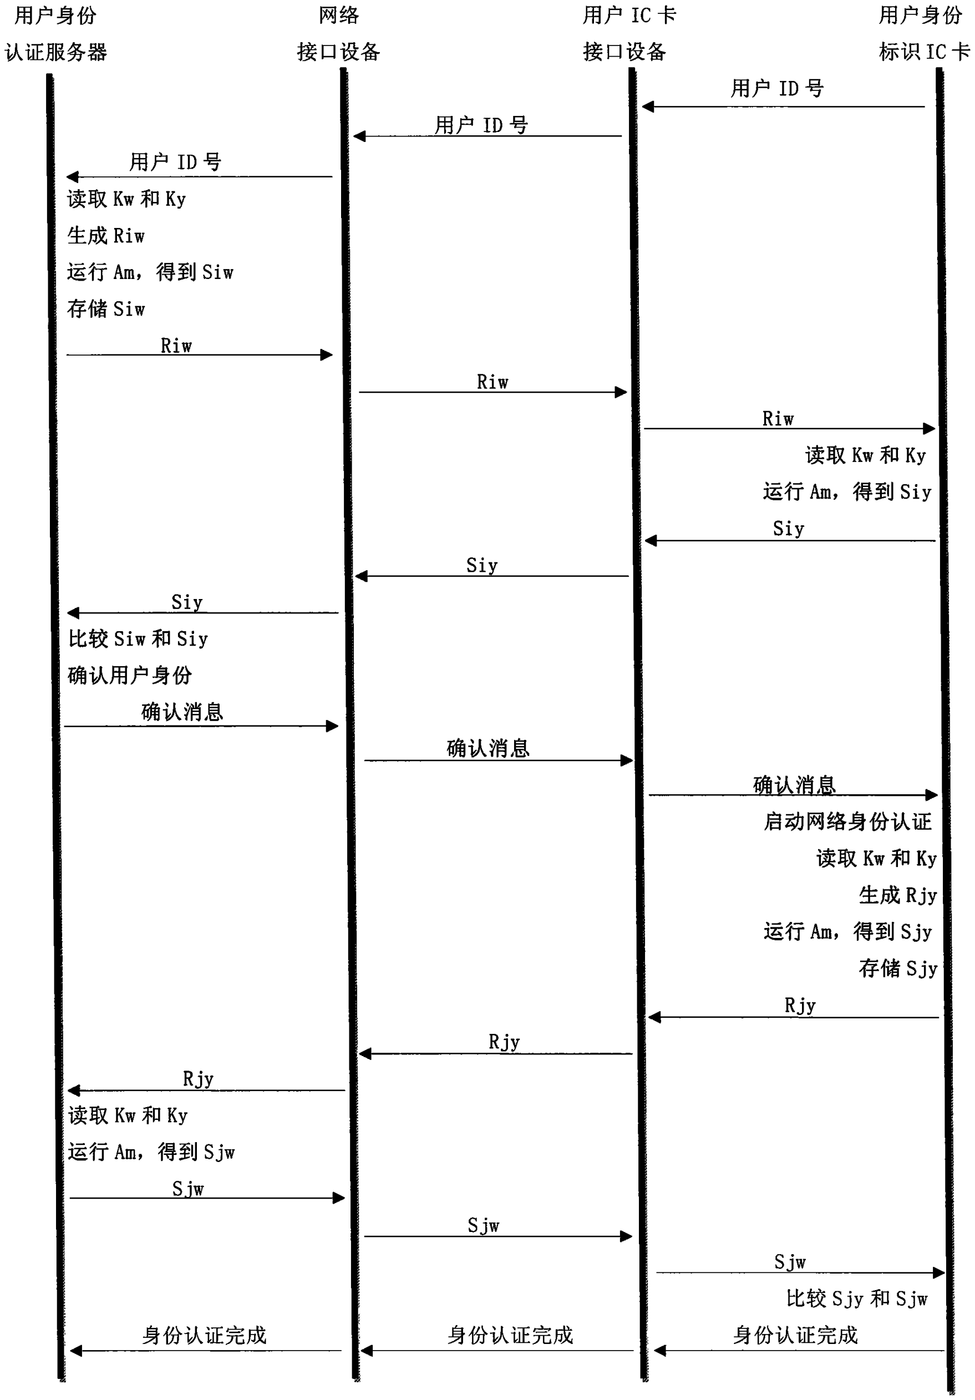
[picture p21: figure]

图 3

CN 104410968 A | 说 明 书 附 图

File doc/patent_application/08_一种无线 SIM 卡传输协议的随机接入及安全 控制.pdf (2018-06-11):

(10)申请公布号
(43)申请公布日
(21)申请号 201510808210.8

(22)申请日 2015.11.23

H04W 74/00(2009.01)
H04W 12/00(2009.01)

(71)申请人 王家城
地址 100192 北京市朝阳区林萃西里 26 号
楼 6 单元 602

(72)发明人 王家城

(54) 发明名称
一种无线 SIM 卡传输协议的随机接入及安全
控制
(57) 摘要
本发明属于移动通信终端领域。本发明公开
了一种适用于在移动通信终端和 SIM 卡之间无线
数据传输的随机接入及安全控制的流程和方法，
使得移动通信终端和 SIM 卡之间通过无线传输接
口能够透明而安全地传输数据。通过通信终端接
口设备和智能型 SIM 卡卡座设备之间的随机接入
信道，使得它们之间的无线数据数据信道能够及
时有效地建立的同时，也节省了智能型 SIM 卡卡
座设备的功率消耗。本发明还通过只共享于通信
终端接口设备和智能型 SIM 卡卡座设备两端的鉴
权密钥和鉴权算法，使得它们之间能够建立起安
全的无线通信链路，保障了他们之间数据传输的
安全。

(51)Int.Cl.

(19)中华人民共和国国家知识产权局

## (12)发明专利申请

权利要求书4页 说明书10页 附图10页

CN 105357769 A
2016.02.24

CN 105357769 A

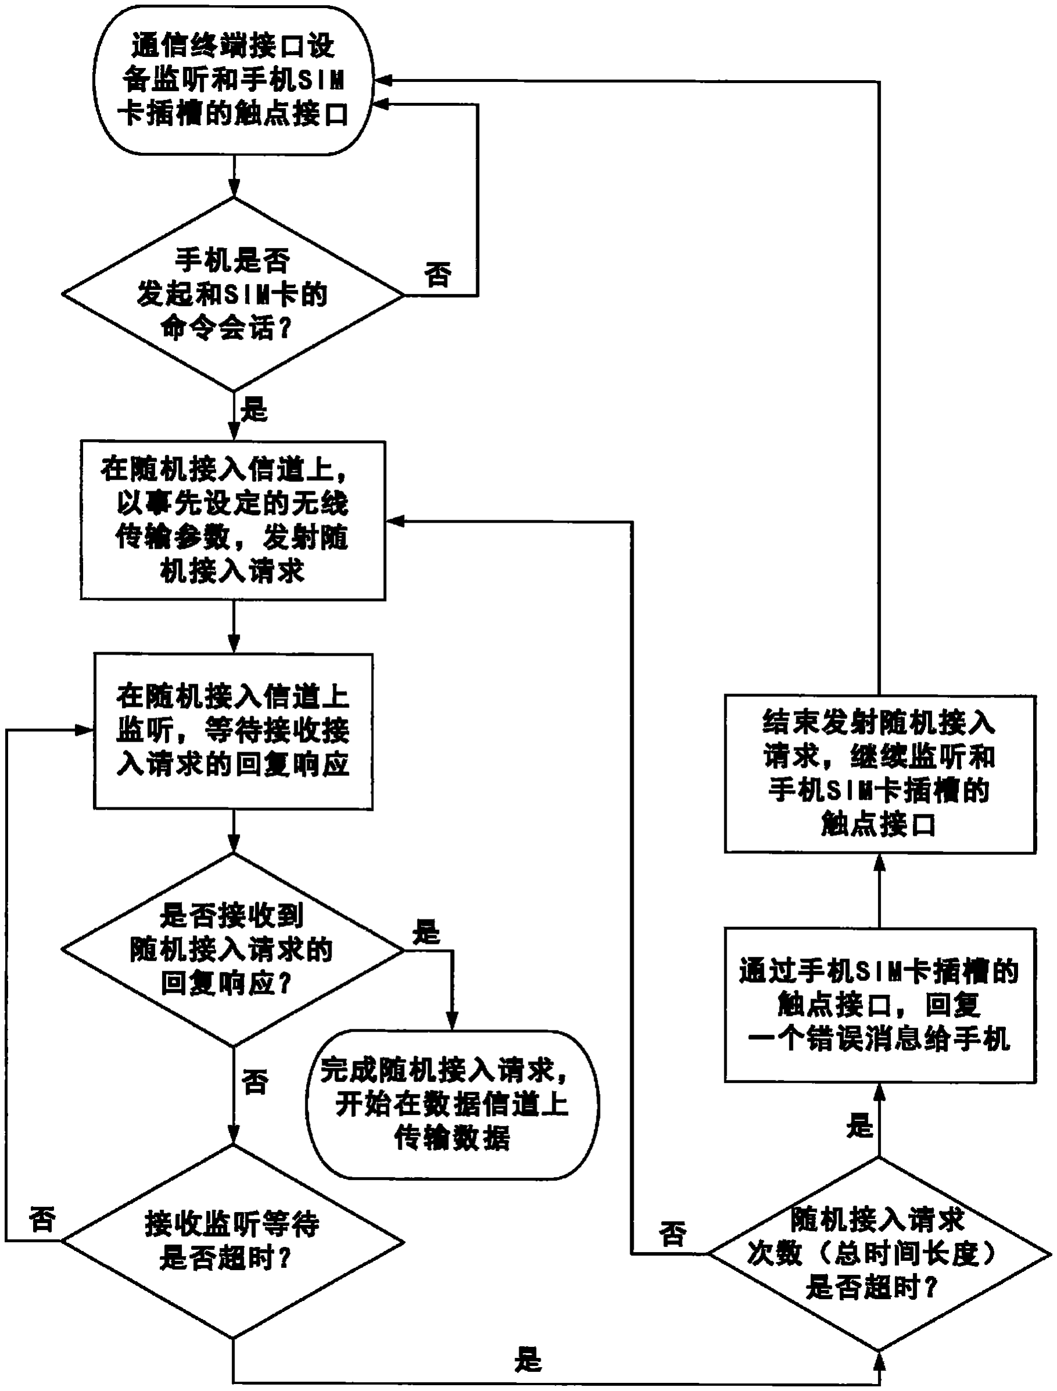
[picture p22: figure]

1/4 页

1.一种用于通信终端接口设备接入其和智能型 SIM 卡卡座设备之间的无线通信链路 的随机接入方法，其特征在于，所述随机接入方法包括，
1) 所述通信终端接口设备发起接入的时间是随机的，是被其它事件触发而无法事先确 定的，任何时间都可以开始发起随机接入，
2) 随机接入的无线传输参数，包括传输信道的频率，调制编码方式，数据帧结构信息 等在收发两端是事先设定的，不需要在它们之间传输其它额外的数据信息，所述智能型 SIM 卡卡座设备在接收到随机接入请求的无线信号后，就能够正确的解调其中的数据，
3) 所述随机接入主要用于通信终端接口设备和智能型 SIM 卡卡座设备之间的无线数 据传输信道的建立和维护，也包括它们之间的身份认证鉴权。
2.根据如权利要求 1 所述的随机接入方法，其特征在于，通信终端接口设备发射随机 接入请求的无线信号是通过如下步骤进行的，
1) 通信终端接口设备和手机 SIM 卡插槽的触点接口处于监听状态，监听手机是否发起 和 SIM 卡的命令会话，
2) 通信终端接口设备监听检测到手机发起和 SIM 卡的命令会话，就读取命令并存储该 命令，手机 SM 卡接口处于接收状态，等待 SIM 卡的回复响应数据，
3) 通信终端接口设备在随机接入信道上，以预先设定的无线传输参数，发射随机接入 请求，
4) 通信终端接口设备在随机接入信道上，监听等待接收随机接入请求的回复响应，
5) 通信终端接口设备如果接收到回复响应，就结束随机接入请求，开始在数据信道上 传输和智能型 SIM 卡卡座设备的交换数据 ( 包括身份鉴权数据和命令会话数据 )，
6) 如果通信终端接口设备直到监听接收的等待时间结束，都没有接收到回复响应，就 检测随机接入请求的总时间是否超时，
7) 如果随机接入请求的总时间没有超时，通信终端接口设备就从第 3) 步骤开始，重新 发射随机接入请求，
8) 如果随机接入请求的总时间超时，通信终端接口设备就通过和手机 SIM 卡插槽的触 点接口，回复一个错误消息给手机，
9) 通信终端接口设备结束发射随机接入请求，从第 1) 步骤开始，继续监听和手机 SIM 卡插槽的触点接口。
3.根据如权利要求 2 所述的通信终端接口设备重复发射随机接入请求的总时间，其特 征在于，所述总时间长度小于手机发起和 SIM 卡之间的命令会话后等到 SIM 卡回复响应的 最大等待时间。
4.根据如权利要求 2 所述的通信终端接口设备等待接收随机接入请求的回复响应时 间，其特征在于，所述等待时间大于无线通信接口信号的往返时间和智能型 SIM 卡卡座设 备的接收，处理，发射回复响应的时间之和。
5.根据如权利要求 1所述的随机接入方法，其特征在于，智能型 SIM卡卡座设备是通过 如下步骤进行监听接收通信终端接口设备的随机接入请求的，
1) 智能型 SIM 卡卡座设备处于空闲等待状态，打开计数器，计时等待空闲等待状态的 结束，
2) 空闲状态结束，打开无线接收接口，监听随机接入信道，
CN 105357769 A | 权 利 要 求 书

2/4 页

3) 如果智能型 SIM 卡座设备监听一段时间后，没有接收到随机接入请求信号，就结束 随机接入信道的监听，关闭无线信道，进入空闲等待状态，从第 1) 步骤开始，重新启动新的 空闲等待计数器，
4) 如果智能型 SIM 卡卡座设备接收到随机接入请求，就在随机接入信道上回复该随机 接入请求，包含有数据信道的无线传输参数，
5) 智能型 SIM 卡卡座设备进入数据传输信道接收等待状态，等待接收通信终端接口设 备通过数据信道传输过来的数据，
6) 智能型 SIM 卡卡座设备接收并转发手机通过通信终端接口设备转发的命令会话数 据，
7) 智能型 SIM 卡卡座设备接收 SIM 卡对会话命令的回复数据，并转发给通信终端接口 设备，直到整个命令会话周期的结束，
8) 智能型 SIM 卡卡座设备从 1) 步骤开始，进入空闲状态，重新启动新的空闲等待计数 器。
6.根据如权利要求 5 所述的智能型 SIM 卡卡座设备监听随机接入信道的等待接收时 间，其特征在于，所述的等待接收时间大于 2 倍的如权利要求 2 所述的通信终端接口发射随 机接入请求的发射时间和 2 倍的如权利要求 2 所述的通信终端接口等待回复响应的等待时 间之和。
7.根据如权利要求 5 所述的智能型 SIM 卡卡座设备的空闲等待 - 监听接收时间周期， 其特征在于，所述空闲等待时间和所述监听接收时间之和小于手机发起和 SIM 卡之间的命 令会话后等到 SIM 卡回复响应的最大等待时间。
8.根据如权利要求 1 所述的随机接入方法，其特征在于，所述的随机接入方是通过如 下流程和步骤进行的，
1) 通信终端接口设备通过和手机 SIM 卡槽的触点电路连接，检测到手机发起和 SIM 卡 的会话命令，就开始发起和建立和智能型 SIM 卡卡座的无线通信链路，
2) 通信终端接口设备扫描预先设定的固定频率的随机接入信道，检测其信道质量，根 据该信道是否被其它的无线信号使用而判断是否适宜传输随机接入请求，或者根据信道的 背景噪音的大小来判断信道质量的好坏，
3) 如果信道质量好且适宜传输随机接入请求，通信终端接口设备就在该信道上传输随 机接入请求，随机接入请求的传输参数包括传输信道频率，数字信号调制方式，无线信道编 码方式等都是设置固定的，
4) 如果所有的随机接入信道质量都差而不适宜传输随机接入请求，通信终端接口设备 就等待一段时间后继续扫描，直到扫描到信道质量好的随机接入信道就使用该信道传输随 机接入请求，
5) 如果扫描等待时间超过了手机和 SIM 卡之间会话周期的最大等待时间，通信终端接 口设备就结束传输随机接入请求，通过和手机 SIM 卡插槽的触点连接接口，回复一个错误 信息给手机，从而手机结束该会话周期，
6) 通信终端接口设备发送传输随机接入请求后，等待智能型 SIM 卡卡座的回复响应数 据，
7) 如果等待一段时间后，还没有收到智能型 SIM 卡卡座的回复响应数据，通信终端接
CN 105357769 A | 权 利 要 求 书

3/4 页

口设备就从如上所述的第 2 步骤开始，重新扫描随机接入信道，为下一次新的随机接入请 求传输寻找质量好的随机接入信道，直到发射出随机接入请求，或者传输时间超时，
8) 如果在一段时间范围内，通信终端接口设备接收到回复响应数据，则随机接入请求 成功，
9) 通信终端接口设备接收到智能型 SIM 卡卡座的回复响应数据后，通过读取回复响应 数据，获得所分配的数据信道传输参数，利用这些传输参数，建立起他们之间的无线数据传 输信道，
10) 通信终端接口设备结束随机接入请求，通过和智能型 SIM 卡卡座建立起的无线通 信链路，以及相应的数据转发，手机和 SIM 卡就建立起了连接，手机继续进行已经发起的和 SIM 卡的命令会话周期，直到 SIM 卡回复响应该命令，以结束命令会话周期。 9.一种用于通信终端接口设备接入其和智能型 SIM 卡卡座设备之间的无线通信链路 的安全数据传输，其特征在于，所述安全数据传输包含有如下功能模块，
1) 在通信终端接口设备中，有一个随机接入请求鉴权算法和一个随机接入响应鉴权算 法，
2) 在智能型 SIM 卡卡座设备中，有一个和通信终端接口设备中相同的随机接入请求鉴 权算法，还有一个和通信终端接口设备中相同的随机接入响应鉴权算法，
3) 在通信终端接口设备中，有一个接入鉴权系统密钥和和一个接入鉴权用户密钥，
4) 在智能型 SIM 卡卡座设备中，有一个和通信终端接口设备相同的接入鉴权系统密钥 和和一个和通信终端接口设备相同的接入鉴权用户密钥，
5) 通信终端接口设备运行随机接入请求鉴权算法，以接入鉴权系统密钥和接入鉴权用 户密钥为输入，能够得到一个唯一确定的随机接入请求数据，
6) 智能型 SIM 卡卡座设备运行随机接入请求鉴权算法，以接入鉴权系统密钥和随机接 入请求数据为输入，能够得到一个唯一确定接入鉴权用户密钥，
7) 智能型 SIM 卡卡座设备能够产生一个随机数序列，这个随机数产生过程能够多次重 复的进行，每次产生一个不同的随机数序列，
8) 智能型 SIM 卡卡座设备运行随机接入响应鉴权算法，以接入鉴权系统密钥和随机数 序列为输入，能够得到一个唯一确定的随机接入响应数据，
9) 通信终端接口设备运行随机接入响应鉴权算法，以接入鉴权系统密钥和随机数序列 为输入，能够得到一个唯一确定的随机接入响应数据。
10.一种用于通信终端接口设备接入其和智能型 SIM 卡卡座设备之间的无线通信链路 的随机接入的安全控制流程，其特征在于，所述安全控制流程包含有步骤，
1) 在通信终端接口设备和智能型 SIM 卡卡座设备中，分别写入相同的随机接入请求鉴 权算法和相同的随机接入响应鉴权算法，
2) 在使用之前，用户在通信终端接口设备和智能型 SIM 卡卡座设备中分别设定相同的 接入鉴权系统密钥和相同的接入鉴权用户密钥，
3) 通信终端接口设备在传输随机接入请求时，运行随机接入请求鉴权算法，以接入鉴 权系统密钥和接入鉴权用户密钥为输入数据，得到一个唯一确定的随机接入请求数据，
4) 通信终端接口设备以随机接入请求数据为传输信息的一部分，在随机接入信道发射 随机接入请求，
CN 105357769 A | 权 利 要 求 书

4/4 页

5) 智能型 SIM 卡卡座设备接收到随机接入请求信号，运行随机接入请求鉴权算法，以 接收到的随机接入请求数据和接入鉴权系统密钥为输入数据，得到一个运行结果的接入鉴 权用户密钥，
6) 智能型 SIM 卡卡座设备比较运行结果的接入鉴权用户密钥和存储的接入鉴权用户 密钥，如果是一致的，就判断其随机接入请求是有效的，需要对该接入请求进行回复响应， 如果不一致，则该接入请求是无效的，就直接忽略而不予响应，
7) 对于有效的随机接入请求，智能型 SIM 卡卡座设备就产生一个随机数序列，作为回 复响应数据的一部分，
8) 智能型 SIM 卡卡座设备在随机接入信道上，发射回复响应随机接入请求，除了数据 信道的无线传输参数外，产生的随机数序列也包含在回复响应中，
9) 智能型 SIM 卡卡座设备在本地保存有随机数序列的一个备份拷贝，以备接下来的对 通信终端接口设备的身份鉴权使用，
10) 通信终端接口设备在随机接入信道上接收到接入请求的回复响应，获得数据信道 的无线传输参数和随机数序列，
11) 通信终端接口设备运行随机接入响应鉴权算法，以接收到的随机数序列和接入鉴 权系统密钥为输入，得到随机接入响应数据，
12) 通信终端接口设备以接收到的无线数据信道传输参数，在数据信道上传输其运算 结果随机接入响应数据，
13) 智能型 SIM 卡卡座设备在数据信道上接收到随机接入响应数据，
14) 智能型 SIM 卡卡座设备运行随机接入响应鉴权算法，以先前存储的备份拷贝随机 数序列和接入鉴权系统密钥为输入，得到运算结果随机接入响应数据，
15) 智能型 SIM 卡卡座设备比较运算结果的随机接入响应数据和接收到的随机接入响 应数据，如果一致，则完成对通信终端接口设备的身份鉴权，认为其是合法有效的，如果两 个数据不一致，则判断通信终端接口设备不是合法的，立即中断随机接入请求过程，
16) 对于通过身份认证鉴权的通信终端接口设备的接入请求，智能型 SIM 卡卡座设备 在数据信道回复一个确认消息，通知其鉴权认证鉴权完成，可以继续传输手机的命令会话 数据，
17) 通信终端接口设备结束随机接入请求，在无线数信道上转发手机命令会话，并接收 智能型 SIM 卡卡座设备转发过来的 SIM 卡的回复响应数据，直到整个命令会话周期的结束。
CN 105357769 A | 权 利 要 求 书

1/10 页

一种无线 SIM 卡传输协议的随机接入及安全控制

技术领域
[0001] 本发明属于移动通信终端领域。具体地说，本发明涉及一种适用于在移动通信终 端和 SIM 卡之间无线数据传输的的随机接入及安全控制的流程和方法，使得移动通信终端 和 SIM 卡之间通过无线传输接口能够透明而安全地传输数据。

背景技术
[0002] 目前，移动通信用户设备主要由移动通信终端设备 ( 包括日常生活中通常使用的 手机以及其它一些能够接入蜂窝移动通信网络的用户终端设备如移动固话，平板电脑，笔 记本电脑等，以下都简称手机 ) 和用户身份模块卡 ( 包括 GSM 系统的 SIM 卡，CDMA 系统的 UIM 卡，以及 2G，3G 和 4G 移动通信系统都可以使用的 USIM 卡，以下都简称 SIM 卡 ) 两个部 分组成。其中手机的主要功能是连接蜂窝式移动通信网络，为用户提供移动通信的应用服 务，而 SIM 卡主要用于移动通信用户身份标识和认证，以及移动通信业务使用的鉴权和授 权，还包括对移动通信网络的鉴权。在现有的技术实现中，手机内部有一个 SIM 卡卡座，使 得 SIM 卡插入卡座后通过引脚接触和手机进行通信。具体的通信协议在有关的智能卡传输 标准中定义 ( 如 ISO-7816 定义传输协议，ETSI TS 102211，3GPP TS 11.11 等定义电信应 用协议 )。这种通信是一种有线通信形式，通过 SIM 卡的触点和手机内部的卡座引脚接触， 建立起有线的通信链路。也就是说，移动通信用户设备的这两个部分之间的数据通信是通 过直接的电路连接通信完成的。
[0003] 在中国发明申请 201410452312.6“一种智能的分离式 SIM 卡卡座设备及通信方 法”中，公开了一种在手机和 SIM 卡之间的中间设备，智能型 SIM 卡卡座设备。通过智能型 SIM 卡卡座，手机和 SIM 卡之间的通信可以通过转发通信而间接地完成。也就是说，智能型 SIM 卡卡座可以是手机和 SIM 卡之间的数据交换的传输中继，并且这个数据的转发传输中 继可以是无线通信。
[0004] 在中国发明申请 201410495484.1“一种通信终端设备和 SIM 卡之间的无线接口及 功能实现”中，更进一步公开了一种无线传输协议，使得这种数据转发的传输差错和传输时 间延迟都在现有标准的容许范围之内。这样，在 SIM 卡和网络双方看来，这个中间的数据转 发通信过程就是透明的，它们都不会觉察到其存在。对现有的移动用户身份认证鉴权过程 和网络接入安全控制机制没有任何的影响，很好地兼顾了现有无线通信网络的安全性以及 手机和 SIM 卡之间无线传输接口的方便性。
[0005] 在中国发明申请 201410735422.3“一种通信终端和 SIM 卡无线数据传输的终端接 口设备”中，公开了一种通信终端接口设备，该接口设备具有标准的 SIM的形状和大小，可以 直接插入现有的手机的 SIM 卡卡槽。一方面，通信终端接口设备和手机之间具有触点连接 的直接电路连接通信，而另一方面，它也具有无线通信接口，能够和智能型 SIM 卡卡座建立 无线通信链路。这样，手机和 SIM 卡之间就可以通过通信终端接口设备，智能型 SIM 卡卡座 以及它们之间的无线通信链路连接起来，进行数据通信。
[0006] 本发明的主要目的是公开了一种无线数据传输的的随机接入及安全控制的流程
CN 105357769 A | 说 明 书

和方法，用于手机和 SIM 卡之间的无线数据传输协议，使得手机和 SIM 卡之间的无线传输接 口可以透明并安全地传输数据，就好像手机和 SIM 卡是直接的电路连接通信一样。

发明内容
[0007] 现有的手机和 SIM 卡之间的传输接口是标准的智能卡 - 终端设备接口，即满足 ISO-7816 智能卡传输协议的接口，它们之间的传输性能如传输数据差错，传输时间延迟需 要满足其规范要求。因此，手机和 SIM 卡的无线数据传输，包括手机和通信终端接口设备之 间的数据转发，通信终端接口设备和智能型 SIM 卡卡座之间的无线数据转发，智能型 SIM 卡 卡座和 SIM 卡之间的数据转发的总体性能，都要满足其规范要求。这样，对于通信终端接口 设备和智能型 SIM 卡卡座之间无线通信链路的建立，连接，维护，释放等过程，对于手机和 SIM 卡来说，都需要是透明，以至不会影响到其数据传输。本发明的无线数据传输信道的随 机接入方法，就是为了实现这种数据的透明传输而提出的技术实施方案。
[0008] 图 1 是无线信道的划分示意图，在整个通信终端接口设备和智能型 SIM 卡卡座之 间的无线信道上，按照它们的使用功能的不同，主要划分为两种不同的无线信道，用于它们 之间不同的数据类型的传输。其中数据信道是用于传输标准的智能卡 - 终端设备接口数 据，而随机接入信道主要用于数据传输信道的建立和维护，控制数据信道的使用。随机接入 信道在无线频率上是固定的，无线传输和接收双方是预先约定的。在整个无线信道的频段 上，有一个或者多个频率固定的信道作为随机接入信道，而其余的所有信道都是数据信道。
[0009] 由于智能卡 - 终端设备接口的数据交换 ( 一个完整的数据交换过程称为一个命令 会话周期 ) 总是由终端设备向智能卡发起命令为开始，而由智能卡对该命令的回复响应为 结束。所以，随机接入信道总是由手机端的通信终端接口设备作为发射端而发起接入请求， 智能型 SIM 卡卡座通过判断接收到的接入请求数据信息，进而回复响应接入请求，或者如 果不是该接入请求的目标接收端，对接入请求不予响应。而数据信道则是由对接入请求的 回复响应进行分配的，用于紧接着的手机 -SIM 卡命令会话周期的数据传输。
[0010] 对于手机端的通信终端接口设备来说，由于手机发起和 SIM 卡的命令会话周期的 时间是不确定的，因此，在什么时候发起建立和智能型 SIM 卡卡座的无线通信链路也是不 确定的。当手机发起和 SIM 卡的命令会话时，需要立即建立起无线通信链路以交换该会话 周期的数据，否则，如果手机和 SIM 卡之间的连接建立超时，手机就判断 SIM 卡数据读取错 误而结束该命令会话周期。所以，通信终端接口设备发起无线通信链路的建立时间是随机 的，不确定的，是有手机发起和 SIM 卡的命令会话时间决定的。通信终端接口设备需要随时 做好准备，等待手机发起命令会话。本发明公开的随机接入的方法和流程，就是用于通信终 端接口设备随时建立和智能型 SIM 卡卡座之间的无线通信链路。如图 2 所示，本发明的随 机接入流程包含有如下步骤 ：
[0011] 1. 手机发起和 SIM 卡之间的命令会话周期，通信终端接口设备通过手机 SIM 卡槽 的触点接触电路连接，检测到手机发起的该会话命令，就开始发起建立和智能型 SIM 卡卡 座设备的无线通信链路。
[0012] 2. 通信终端接口设备扫描预先设定的固定频率的随机接入信道，检测其信道质 量，根据该信道是否被其它的无线信号使用而判断是否适宜传输随机接入请求，或者根据 信道的背景噪音的大小来判断信道质量的好坏。

[0013] 3. 如果信道质量好且适宜传输随机接入请求，通信终端接口设备就在该信道上传 输随机接入请求。随机接入请求的传输参数包括传输信道频率，数字信号调制方式，无线信 道编码方式等都是设置固定的，使得接收端使用相同固定的接收参数，能够接收到随机接 入请求。如果所有的随机接入信道质量都差而不适宜传输随机接入请求，通信终端接口设 备就等待一段时间后继续扫描，直到扫描到信道质量好的随机接入信道就使用该信道传输 随机接入请求。当扫描等待时间超过了手机和 SIM 卡之间会话周期的最大等待时间，通信 终端接口设备就结束发射随机接入请求，通过和手机的 SIM 卡插槽的触点连接电路接口， 回复一个错误信息给手机，从而手机结束该命令会话周期。
[0014] 4. 通信终端接口设备发射随机接入请求后，就等待智能型 SIM 卡卡座设备的回复 响应数据。如果等待一段时间后，还没有收到智能型 SIM 卡卡座设备的回复响应数据，通信 终端接口设备就从如上所述的第 2 步骤开始，重新扫描随机接入信道，为下一次新的随机 接入请求传输寻找质量好的随机接入信道，直到发射出随机接入请求，或者传输时间超时。 如果在一段时间范围内，通信终端接口设备接收到回复响应数据，则随机接入请求成功。
[0015] 5. 通信终端接口设备接收到智能型 SIM 卡卡座的回复响应数据后，通过读取回复 响应数据，获得所分配的数据信道传输参数，例如数据传输信道的频道，调制编码方式等， 开始利用这些传输参数，建立起他们之间的无线数据传输信道。
[0016] 6. 通信终端接口设备结束随机接入请求，通过和智能型 SIM 卡卡座建立起的无线 通信链路，以及相应的数据转发，手机和 SIM 卡就建立起了连接，手机得以继续进行已经发 起的和 SIM 卡的命令会话周期，直到 SIM 卡回复响应该命令，以结束命令会话周期。
[0017] 对于插入手机 SIM 卡插槽的 SIM 卡来说，由于和手机插槽的触点有直接的电路连 接，并且 SIM 卡的数据传输接口一直处于命令接收等待状态，当手机发起命令会话时，SIM 卡就会立即接收到命令并在很短的时间内对该命令进行回复响应。但是对于手机和 SIM 卡 之间的无线连接来说，除了两端的数据转发通信会带来额外的时间延迟，无线信道的空中 传输，无线信号的调制解调也会引入时间延迟，这些时间延迟需要小于手机发起发起命令 会话后等待 SIM 卡回复响应的最大等待时间。而另一方面，智能型 SIM 卡卡座设备通常是 由电池供电的用户移动设备，虽然插入其中的 SIM 卡是可以一直处于命令接收等待状态， 但其无线通信接口就很难一直处于无线信号接收状态，因为电池的续航时间对于移动设备 来说非常重要。所以，智能型 SIM 卡卡座设备的无线接口通常情况下都是处于关闭状态，只 是在需要的时候，才打开其无线通信接口，接收从通信终端接口设备传输的信号。而同时， 通信终端接口设备传输随机接入请求的时间是随机的，无法事先确定，智能型 SIM 卡卡座 设备只能周期性地打开无线通信接口，接收并解调无线信号，以检测判断是否有随机接入 请求。
[0018] 图 3是智能型 SIM卡卡座设备在时间上无线数据传输帧结构。在固定的时间周期， 智能型 SIM 卡卡座设备打开其无线通信接口，监测随机接入信道。经过一段时间，如果没有 接收到随机接入请求，智能型 SIM 卡卡座设备就关闭其无线通信接口，进入低功耗的空闲 模式 ( 或睡眠模式 )。再经过一个固定的时间周期后，智能型 SIM 卡卡座设备继续监测随机 接入信道，如果接收到随机接入请求，就回复数据传输信道的无线传输参数，进入无线信号 接收等待状态，等待接收通信终端接口设备通过数据信道传输过来的数据，并在手机和 SIM 卡的整个会话周期中透明转发它们之间的数据交换，直到命令会话周期结束。

[0019] 图 4 是本发明的智能型 SIM 卡卡座设备的工作状态流程图，包含有步骤 ：
[0020] 1. 智能型 SIM 卡卡座设备处于空闲状态，打开计数器，计时等待空闲状态的结束 时间。
[0021] 2. 空闲状态结束，打开无线接口，监听随机接入信道。
[0022] 3. 如果智能型 SIM 卡卡座设备监听一段时间后，没有接收到随机接入请求信号， 就结束随机接入信道的监听，关闭无线信道，进入空闲状态，从步骤 1 开始，重新启动新的 空闲等待计数器。
[0023] 4. 如果智能型 SIM 卡卡座设备接收到随机接入请求，就在随机接入信道上回复该 随机接入请求，包含有数据信道的无线传输参数。
[0024] 5. 进入数据传输信道接收等待状态，等待接收通信终端接口设备通过数据信道传 输过来的数据。
[0025] 6. 接收手机通过通信终端接口设备转发过来的会话命令，并转发给 SIM 卡。
[0026] 7. 接收 SIM 卡对会话命令的回复数据，并转发给通信终端接口设备，直到整个命 令会话周期的结束。
[0027] 8. 进入空闲状态，从步骤 1 开始，重新启动新的空闲等待计数器。
[0028] 由于手机发起命令会话周期后，有一个等待 SIM 卡回复响应的最大等待时间，并 且手机发起命令会话的时间是随机的，所以智能型 SIM 卡卡座设备的随机信道监听时间间 隔必须小于这个最大等待时间，以保证数据传输信道能够及时地建立。
[0029] 图 5 是本发明的智能型 SIM 卡卡座设备的用于随机接入请求信道的时间关系图 ：
[0030] 1. 在时间上，按功能划分，主要分为低功耗的空闲时间，处于无线接收状态的随机 接入信道监听时间。如果收到随机接入请求的话，还包括回复响应时间，命令会话周期时 间。
[0031] 2. 一个命令数据从手机到 SIM 卡 ( 一个回复响应数据从 SIM 卡到手机也类似 )， 其时间包括通信终端接口设备的信号转发时间，无线信道的传输时间 ( 包括空中传输时间 以及传输和接收端对信号的处理时间等 )，智能型 SIM 卡卡座设备的转发时间。
[0032] 3. 为了保证智能型 SIM 卡卡座设备在随机接入监听的时间窗口内能够接收到随 机接入请求，其监听的时间必须大于通信终端接口设备的信号转发时间和无线信道的传输 时间的总和。
[0033] 4. 为了保证手机发起命令会话后能够在有效的时间范围内收到 SIM 卡的回复响 应，智能型 SIM 卡卡座设备的空闲时间，随机接入的监听时间，回复响应时间的总和必须小 于手机等待 SIM 卡响应回复的最大等待时间。
[0034] 这样，通过智能型 SIM 卡卡座设备在时间上的空闲 - 监听方式，并控制它们相应的 持续时间长度，一方面节省了功率消耗，延长了电池的续航时间。另一方面，也使得手机的 等待时间在其最大等待时间范围内，手机和 SIM 卡之间可以透明的传输数据。
[0035] 图 6 是本发明的通信终端接口设备的工作状态流程图，为了及时有效地响应手机 发起的命令会话，通信终端接口设备与手机 SIM 卡插槽的触点接口一直处于监听状态，监 听是否有手机发起的与 SIM 卡的命令会话，包含有步骤 ：
[0036] 1. 通信终端接口设备和手机 SIM 卡插槽的触点接口处于监听状态，监听手机是否 发起和 SIM 卡的命令会话。

[0037] 2. 通信终端接口设备监听检测到手机发起和 SIM 卡的命令会话，就读取命令并存 储该命令，手机 SM 卡接口处于接收状态，等待 SIM 卡的回复响应数据。
[0038] 3. 通信终端接口设备在随机接入信道上，以预先设定的无线传输参数，发射随机 接入请求。
[0039] 4. 通信终端接口设备在随机接入信道上，监听等待接收随机接入请求的回复响 应。
[0040] 5. 通信终端接口设备如果接收到回复响应，就结束随机接入请求，开始在数据信 道上传输和智能型 SIM 卡卡座设备的交换数据 ( 包括身份鉴权数据和命令会话数据 )。
[0041] 6. 如果通信终端接口设备直到监听接收的等待时间结束，都没有接收到回复响 应，就检测随机接入请求的总时间是否超时。
[0042] 7. 如果随机接入请求的总时间没有超时，通信终端接口设备就从第 3 步骤开始， 重新发射随机接入请求。
[0043] 8. 如果随机接入请求的总时间超时，通信终端接口设备就通过和手机 SIM 卡插槽 的触点接口，回复一个错误消息给手机。
[0044] 9. 通信终端接口设备结束发射随机接入请求，从第 1 步骤开始，继续监听和手机 SIM 卡插槽的触点接口。
[0045] 当手机发起和 SIM 卡的命令会话后，就一直处于等待 SIM 卡回复响应状态，直到收 到 SIM 卡的回复响应数据，或者等待超时而进入错误处理。所以，本发明的通信终端接口设 备重复发射随机接入请求的总时间长度小于手机的最大等待时间，并且通信终端接口设备 在每次发射随机接入请求后的等待时间大于两次无线信道的传输时间和智能型 SIM 卡卡 座设备的转发时间之和。如图 7 所示，它们的时间关系如下 ：
[0046] 1. 通信终端接口设备一个完整的随机接入请求包括随机接入请求发射时间和随 后的回复响应的等待时间。
[0047] 2. 通信终端接口设备的回复响应等待时间大于 2 次的无线信道的传输时间和智 能型 SIM 卡卡座设备的转发时间之和，也就是说，通信终端接口设备发射随机接入请求后， 要等待接入请求被智能型 SIM 卡卡座设备收到 (1 次无线信道的传输时间 )，并处理收到的 信号以及发射回复响应 (智能型 SIM卡卡座设备的转发时间 )，再等待回复响应数据被通信 终端接口设备收到 (1 次无线信道的传输时间 )。
[0048] 3. 智能型 SIM 卡卡座设备的随机接入监听时间大于 2 次完整的随机接入请求时 间，即 2 次的随机接入请求发射时间和 2 次的回复响应等待时间之和。由于智能型 SIM 卡 卡座设备和通信终端接口设备之间的随机接入信道没有时间同步，这样的时间关系保证了 智能型 SIM 卡卡座设备在任意时刻开始的随机接入监听都能够收到一个完整的随机接入 请求信号。
[0049] 4. 通信终端接口设备重复发射随机接入请求总次数的时间之和小于手机等待 SIM 卡回复响应的最大等待时间，这样使得无线通信链路能够及时有效的建立，手机和 SIM 卡之间的命令会话得以继续进行而不至于中断。
[0050] 与移动通信业务有关的用户身份标识与认证的安全数据都存储在 SIM 卡中。其中 用于身份鉴权的数据如鉴权密钥和鉴权算法等只能在 SIM 卡内部运行使用，是不能被读取 出来而在无线信道中传输。其他一些与用户身份信息相关的敏感数据如 IMSI( 国际移动用

户识别码 ) 等需要在无线数据信道上传输，用于手机接入移动通信网络的身份标识。所以， 对于通信终端接口设备于与智能型 SIM 卡卡座设备之间的无线通信链路来说，其数据传输 的安全性非常重要。特别，在其随机接入信道上，智能型 SIM 卡卡座设备如何识别真实用户 的通信终端接口设备，进行回复响应以建立起无线数据信道的同时，有对那些不是真实用 户的随机接入请求不予响应，使得非真实用户无法获得 SIM 卡的数据。本发明在随机接入 信道还具有额外的安全控制技术实施方案，使得保障真实用户的随机接入请求获得及时回 复响应的同时，非真实用户的通信终端接口设备却不能通过随机接入信道和智能型 SIM 卡 卡座设备建立连接，保证了其中 SIM 卡数据的安全性。
[0051] 图 8 是本发明的随机接入安全控制功能模块图，包含有如下的功能模块 ：
[0052] 1. 在通信终端接口设备和智能型 SIM 卡卡座设备两端，都具有两个相同的随机接 入鉴权算法，一个称为随机接入请求鉴权算法，一个称为随机接入响应鉴权算法。它们对两 个鉴权算法的使用方式是不同的。
[0053] 2. 在通信终端接口设备于和智能型 SIM 卡卡座设备两端，都具有相同的接入鉴权 系统密钥和相同的接入鉴权用户密钥。
[0054] 3. 通信终端接口设备使用随机接入请求鉴权算法，以接入鉴权系统密钥和接入鉴 权用户密钥为输入，得到随机接入请求数据。
[0055] 4. 智能型 SIM 卡卡座设备使用随机接入请求鉴权算法，以接入鉴权系统密钥和通 过无线接口接收到的随机接入请求数据为输入，得到接入鉴权用户密钥。
[0056] 5. 智能型 SIM 卡卡座设备在回复响应随机接入请求的时候，能够产生一个随机数 序列，并通过无线通信接口传输给通信终端接口设备。这个随机数序列是一次性使用的，在 下一次回复响应时，重新产生一个新的随机数序列。
[0057] 6. 智能型 SIM 卡卡座设备使用随机接入响应鉴权算法，以接入鉴权系统密钥和一 次性使用的随机数序列为输入，得到随机接入响应数据。
[0058] 7. 通信终端接口设备使用随机接入响应鉴权算法，以接入鉴权系统密钥和通过无 线接口接收到的随机数序列为输入，得到随机接入响应数据。
[0059] 图 9 和图 10 是本发明的随机接入的安全控制流程图。一方面，当通信终端接口设 备发射随机接入请求后，如果智能型 SIM 卡卡座设备是其目标接收者 ( 被请求接入并读取 其中的 SIM 卡数据 )，智能型 SIM 卡卡座设备就能够接收到接入请求。另一方面，如果智能 型 SIM 卡卡座设备不是接入请求的目标接收者，就不能正确的就收到随机接入请求。这样 一个过程相当于通信终端接口设备对智能型 SIM 卡卡座设备进行身份鉴权，避免接入到一 个非目标的智能型 SIM 卡卡座而泄露了安全数据如接入鉴权用户密钥。当智能型 SIM 卡卡 座接收到随机接入请求后，又通过随机数序列的质问 - 回答方式，对通信终端接口设备的 身份进行了鉴权。这样，通过他们之间相互的双向鉴权，保障了随机接入信道的安全性。只 有通信的双方都确认了对方是合法真实的有效终端后，它们之间的随机接入信道才能够建 立起来，并进一步建立起无线数据传输信道。这样的安全控制流程包含有如下步骤 ：
[0060] 1. 在通信终端接口设备和智能型 SIM 卡卡座设备中，分别写入相同的随机接入请 求鉴权算法和相同的随机接入响应鉴权算法。对于任何一个算法来说，其输出数据能够被 输入数据唯一地确定，也就是说，算法的输出数据能够且只能够通过相同的输入数据被重 现。

[0061] 2. 在使用之前，用户在通信终端接口设备和智能型 SIM 卡卡座设备中分别设定相 同的接入鉴权系统密钥和相同的接入鉴权用户密钥。这些鉴权密钥被存储在它们的非易失 性存储器中 ( 例如闪存 )，只需要一次性的设定而可以一直使用。当需要使用的时候，就从 其存储器中读取出来，用户不需要记住鉴权密钥。为了保障数据安全性，系统密钥和用户密 钥不能被其它设备读取而只能在用户的通信终端接口设备或者智能型 SIM 卡卡座设备内 部被使用。
[0062] 3. 当通信终端接口设备在传输随机接入请求时，就运行随机接入请求鉴权算法， 以接入鉴权系统密钥和接入鉴权用户密钥为输入数据，得到一个唯一确定的随机接入请求 数据序列。
[0063] 4. 通信终端接口设备以随机接入请求数据为传输信息的一部分，在随机接入信道 发射随机接入请求。
[0064] 5. 智能型 SIM 卡卡座设备接收到随机接入请求信号，运行随机接入请求鉴权算 法，以接收到的随机接入请求数据和接入鉴权系统密钥为输入数据，得到一个运行结果的 接入鉴权用户密钥。由于使用了和通信终端接口设备相同的算法和相同的数据，并且算法 的输出数据能够被输入数据唯一地确定，如果智能型 SIM 卡卡座设备是接入请求的目标， 那么就能够得到正确的接入鉴权用户密钥，并且和其存储的接入鉴权用户密钥是一致的。 对于存储有多个接入鉴权用户密钥的智能型 SIM 卡卡座设备，是和其中的某一个接入鉴权 用户密钥一致的。如果智能型 SIM 卡卡座设备不是接入请求的目标接收者，由于其不具有 接入鉴权系统密钥，就不能通过运行随机接入请求鉴权算法而得到正确的接入鉴权用户密 钥，这样就避免了接入鉴权用户密钥被非接入请求目标的智能型 SIM 卡卡座设备获得。
[0065] 6. 智能型 SIM 卡卡座设备比较运行结果的接入鉴权用户密钥和存储的接入鉴权 用户密钥，如果是一致的，就判断其随机接入请求是有效的，需要对该接入请求进行回复响 应。如果不一致，则该接入请求是无效的，就直接忽略而不予回复响应。
[0066] 7. 对于有效的随机接入请求，智能型 SIM 卡卡座设备就产生一个随机数序列，作 为回复响应数据的一部分。这个随机数序列是一次性使用的，每次进行随机接入请求的回 复响应时，都要重新产生一个新的随机数序列。
[0067] 8. 智能型 SIM 卡卡座设备在随机接入信道上，发射回复响应数据给随机接入请 求，除了数据信道的无线传输参数外，产生的随机数序列也包含在回复响应中。随机数序列 在智能型 SIM 卡卡座设备的本地还保存有一个备份拷贝，以备接下来的对通信终端接口设 备的身份鉴权使用。
[0068] 9. 通信终端接口设备在随机接入信道上接收到接入请求的回复响应，获得数据信 道的无线传输参数和随机数序列。
[0069] 10. 通信终端接口设备运行随机接入响应鉴权算法，以接收到的随机数序列和接 入鉴权系统密钥为输入，得到随机接入响应数据。
[0070] 11. 通信终端接口设备以接收到的无线数据信道传输参数，在数据信道上传输其 运算结果随机接入响应数据。
[0071] 12. 智能型 SIM 卡卡座设备在数据信道上接收到随机接入响应数据。
[0072] 13. 智能型 SIM 卡卡座设备运行随机接入响应鉴权算法，以先前存储的备份拷贝 随机数序列和接入鉴权系统密钥为输入，得到运算结果随机接入响应数据。

[0073] 14. 智能型 SIM 卡卡座设备比较运算结果的随机接入响应数据和接收到的随机接 入响应数据，如果是一致的，则完成对通信终端接口设备的身份认证鉴权，认为其是合法有 效的。如果两个数据不一致，则判断通信终端接口设备不是合法的，立即中断随机接入请求 过程。通过这样一个质问 - 回答的过程，一个非法的通信终端接口设备由于不具有有效的 接入鉴权系统密钥，是不能通过这样一个身份认证过程。
[0074] 15. 对于通过身份认证鉴权的通信终端接口设备的接入请求，智能型 SIM 卡卡座 设备在数据信道回复一个确认消息，通知其认证鉴权完成，可以继续进行命令会话。
[0075] 16. 通信终端接口设备结束随机接入请求，在无线数信道上转发手机命令会话，并 接收智能型 SIM 卡卡座设备转发过来的 SIM 卡的回复响应数据，直到整个命令会话周期的 结束。
[0076] 这样，通过只共享于通信终端接口设备和智能型 SIM 卡卡座设备两端的接入鉴权 系统密钥 ( 通过用户的设置 )，它们就完成了相互的认证鉴权，保证了它们之间的无线通信 链路的安全性。当同一个用户的多个通信终端接口设备需要接入同一个智能型 SIM 卡卡座 设备时，多个通信终端接口设备的接入鉴权系统密钥是相同的，但它们的接入鉴权用户密 钥可以不一样。这样，通过各不相同的接入鉴权用户密钥，还可以在无线传输数据信道上进 行多址接入区分。
[0077] 发明的效果
[0078] 本发明通过通信终端接口设备和智能型 SIM 卡卡座设备之间的随机接入信道，在 时间上分片段地使用它们之间的无线信道，并控制每一个时间片段的长度，使得它们之间 的数据信道能够及时有效地建立的同时，也节省了智能型 SIM 卡卡座设备的功率消耗，延 长了电池的续航时间，在穿戴设备中提高了用户的使用体验。本发明还通过只共享于通信 终端接口设备和智能型 SIM 卡卡座设备两端的鉴权密钥和鉴权算法，使得它们之间能够建 立起安全的无线通信链路，保障了他们之间数据传输的安全。

附图说明
[0079] 图 1 是通信终端接口设备和智能型 SIM 卡卡座设备之间无线通信接口在频率上的 划分，分为数据信道和随机接入信道，其中随机接入信道在频率上是固定的。
[0080] 图 2 是本发明的随机接入流程图，随机接入由通信终端接口设备发起，由智能型 SIM 卡卡座设备的回复响应结束。
[0081] 图 3 是本发明的通信终端接口设备和智能型 SIM 卡卡座设备之间无线通信接口在 时间上的无线数据帧结构图，主要分为空闲等待时间和随机接入请求的监听时间，还包括 手机和 SIM 卡之间命令会话周期的数据无线转发时间。
[0082] 图 4 是本发明的智能型 SIM 卡卡座设备在时间上的状态流程图。
[0083] 图 5 是本发明的智能型 SIM 卡卡座设备用于随机接入请求信道的时间关系图，以 保证各个信道的时间在标准的范围内，使得手机和 SIM 卡之间的智能卡 - 终端设备接口的 正常通信得以进行。
[0084] 图 6 是本发明的通信终端接口设备的工作状态流程图。
[0085] 图 7 是通信终端接口设备的随机接入请求的时间关系图，发射随机接入请求的总 时间长度小于手机等待 SIM 卡回复响应的最大等待时间。

[0086] 图 8 是本发明的随机接入安全控制功能模块图。
[0087] 图 9 和图 10 是本发明的随机接入的安全控制流程图，通过随机接入的安全控制流 程，通信终端接口设备和智能型 SIM 卡卡座设备都完成双向的身份认证，建立起它们之间 安全的无线传输信道。

具体实施方式
[0088] 通信终端接口设备和智能型 SIM 卡卡座设备之间的无线接口可以使用不同的技 术方案，如蓝牙，无线局域网等，并且不同设备提供商的具体无线传输方案也不相同，所以 本发明的随机接入和安全控制的可以有不同的具体实施方式。下面以挪威 Nordic 公司的 蓝牙片上系统 (SoC，System on chip) 芯片 nRF51822 为例，来具体说明本发明的技术实施 方式。
[0089] 芯片 nRF51822 支持多协议的 2.4G 无线通信，包括专有的传输协议和标准的蓝牙 4.0协议，用户也可以利用其应用编程接口实现自己的应用通信协议。这样的特点为实现本 发明的随机接入和安全控制的具体实施方式提供了灵活性。
[0090] 在 nRF51822 的整个无线频率 2400MHz-2483.5MHz 上，在每 1MMHz 的频率带宽 上，可以划分一个传输信道，共计 83 个传输信道。其中间频率的一个信道，如中心频率为 2440MHz 的信道设定为通信终端接口设备和智能型 SIM 卡卡座设备之间的随机接入信道， 其余的 82 个信道为数据信道。
[0091] 芯片 nRF51822 提供的 RSSI(Received Signal Strength Indication，接收的信 号强度指示 ) 功能可以用于扫描随机接入信道的质量，以评估是否适宜于传输随机接入请 求。由于 2.4G 的频段是公共频段，其它的设备也可能使用，所以根据随机接入信道的 RSSI， 如果信道质量差，就等待一段时间，当其它设备释放该信道后，再利用其传输随机接入请 求，可以大大地提高随机接入请求无线信号的接收质量。
[0092] 当手机发起命令会话后等待 SIM 卡回复响应的最大等待时间可以在它们之间的 初始会话 (ATR，Answer To Reset) 时商议，下面以这个最大等待时间为 1 秒 (1000 毫秒 ) 为例来说明。在智能型 SIM 卡卡座设备的 nRF51822 芯片程序中，启动一个实时时钟计数器 (RTC，Real Time Counter)，计数器每 500 毫秒产生一个时钟中断。在时钟中断的服务程序 里，nRF51822 芯片就可以打开其无线接收模块，监听随机接入信道。如果在监听过程中接 收到随机接入请求，就可以进行接收解调，解码等，根据结果而决定进一步的行动。如果一 直没有接收到随机接入请求，中断的服务程序在运行 10 毫秒后，就结束中断的服务程序， 等待下一个时钟中断 ( 每 500 毫秒产生一个 )。在等待时钟中断中间，nRF51822 芯片关闭 无线接收模块，进入低功耗的睡眠模式。这样，在手机等待 SIM 卡回复响应的最大等待时间 内，智能型 SIM 卡卡座设备就有 2 次机会监听随机接入信道。更进一步增加了它们之间无 线通信链路建立的及时性。
[0093] nRF51822 芯片的无线传输时间可以小于 1 毫秒，通信终端接口设备在发射随机接 入请求后，等待 3 毫秒，以等待接收智能型 SIM 卡卡座设备对接入请求的回复响应。这样， 在智能型 SIM 卡卡座设备 10 毫秒的时钟中断服务程序里，通信终端接口设备可以有 2 次随 机接入请求发射机会，无论智能型 SIM 卡卡座设备在什么时候开始监听随机接入信道，都 有机会收到一个完整的随机接入请求无线信号。

[0094] nRF51822 芯片也提供随机数发生器的功能，其随机数的产生是根据背景热噪声 信号，具有很好的随机性能。接入鉴权系统密钥和接入鉴权用户密钥由用户输入设定，为 16 个字节，即 128 位，存储在 nRF51822 芯片的闪存上。nRF51822 的 ARM Cortex M0 32 位 微控制器可以很容易地实现各种不同随机接入请求鉴权算法和随机接入请求响应算法，例 如，可以是接入鉴权系统密钥和接入鉴权用户密钥的按位异或，得到相同长度的运行结果 数据。在产生随机数序列是，也可以是相同的长度，即 128 位 (16 个字节 )，就很容易地实现 按位异或的鉴权算法。
[0095] 通过 nRF51822 芯片上的程序运行，可以实现本发明的随机接入安全控制流程，建 立起通信终端接口设备和智能型 SIM 卡卡座设备之间安全的的无线通信链路，保障他们之 间数据传输的安全。

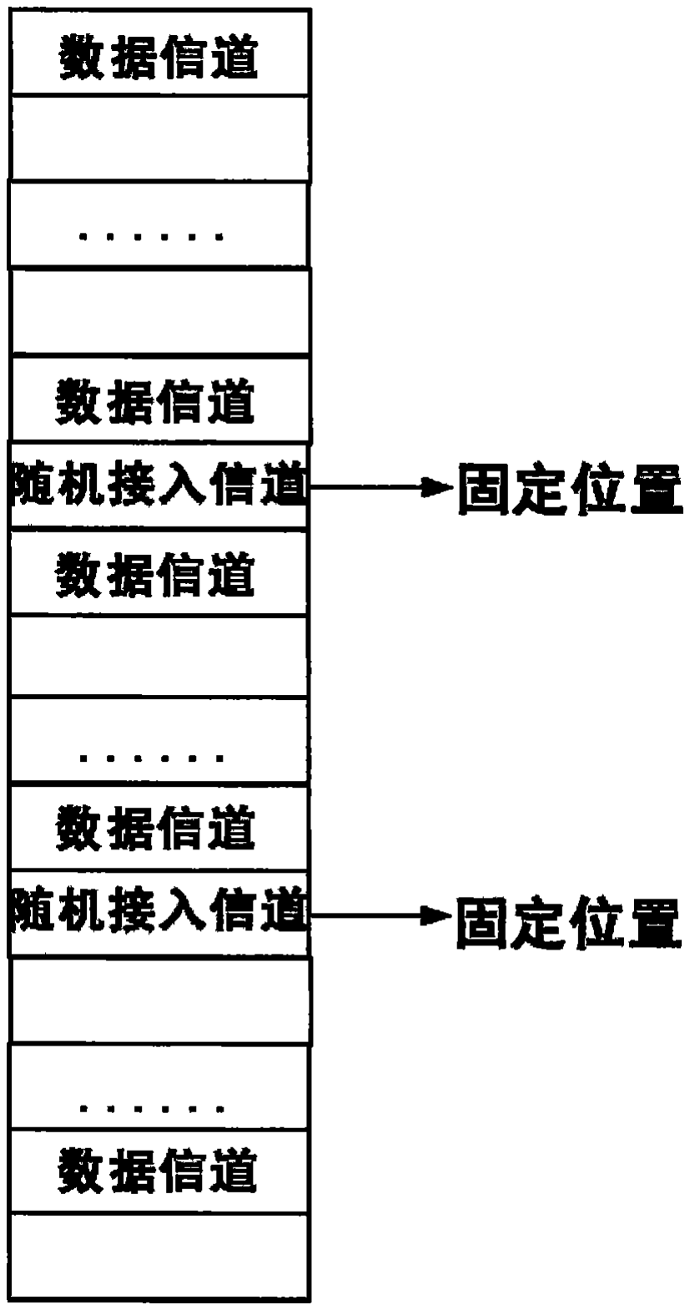
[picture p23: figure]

图1

CN 105357769 A | 说 明 书 附 图

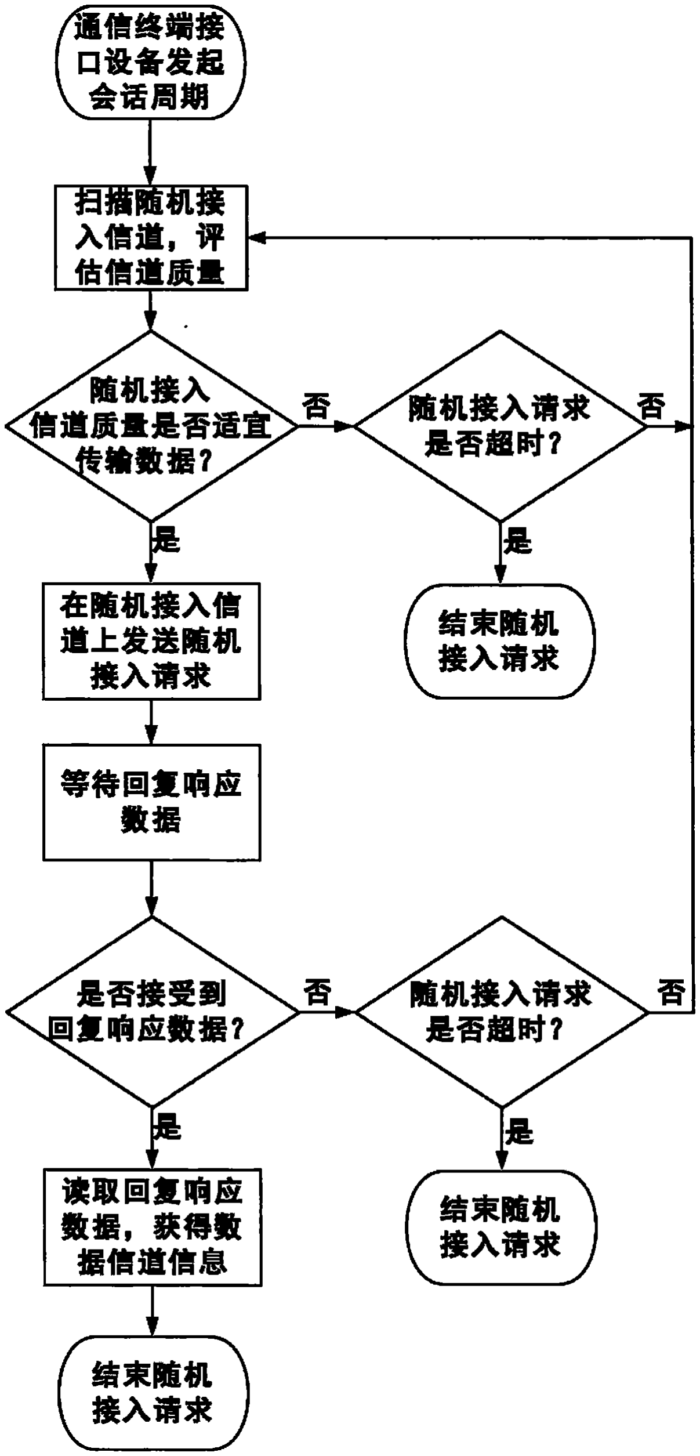
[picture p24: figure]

图2


图3


图4


图5


图6


图7


图8


图9


图 10

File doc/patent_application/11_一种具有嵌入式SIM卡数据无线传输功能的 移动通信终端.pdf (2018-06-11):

(19)中华人民共和国国家知识产权局

## (12)发明专利申请

(10)申请公布号
(43)申请公布日
(21)申请号 201610278994 .2

(22)申请日 2016.05 .03

(71)申请人 王家城
地址 100192 北京市朝阳区林萃西里26号
楼6单元602

(72)发明人 王家城

(51)Int.Cl .
H04W 8/18(2009.01)
H04W 12/06(2009.01)

(54)发明名称
一种具有嵌入式SIM卡数据无线传输功能的
移动通信终端
(57)摘要
本发明属于移动通信终端领域。本发明通过
在具有嵌入式SIM卡的移动通信终端增加微控制
器功能模块，无线通信接口以及移动通信终端
SIM卡控制器，在不影响移动通信终端本身功能
的情况下，使用SIM卡数据更加灵活和方便。移动
通信终端除了可以使用嵌入式SIM卡的身份认证
和鉴权数据接入蜂窝移动通信网络，还可以通过
无线通信接口，远程地使用其它SIM卡的身份认
证和鉴权数据接入蜂窝移动通信网络。与此同
时，还可以通过无线通信接口，无线远程地提供
嵌入式SIM卡的身份认证和鉴权数据给其它的移
动通信终端，用以接入蜂窝移动通信网络，获得
移动通信服务。

权利要求书6页 说明书16页 附图6页

CN 106028304 A
2016.10.12


CN 106028304 A

1 .一种具有嵌入式SIM卡的移动通信终端，其特征在于，所述移动通信终端是在其无线 基带模块的SIM卡接口和嵌入式SIM卡的连接之间，增加一个微控制器，它们之间具有如下 所述的功能模块及连接，
1)微控制器的电源接口正极VCC和负极GND直接连接于移动通信终端的电源供应接口， 获得微控制器运行时所需要的电源供应，
2)嵌入式SIM卡电源接口负极GND直接连接于移动通信终端的电源系统负极GND，
3 )微控制器的输入输出接口连接于移动通信终端无线基带模块SIM卡接口的相应接 口，包括数据输入输出IO接口，时钟信号CLK接口，重置信号RST接口共三个接口， a)数据IO接口既可以作为微控制器的输入口，使得微控制器可以读取移动通信终端的 无线基带模块SIM卡接口的数据，接收移动通信终端发给SIM卡的命令或者数据，也可以作 为微控制器的输出口，使得微控制器可以给移动通信终端的无线基带模块回复数据， b)时钟信号CLK接口是作为微控制器的输入口，用于接收移动通信终端的无线基带模 块SIM卡接口的时钟信号，
c)重置信号RST接口是作为微控制器的输入口，用于接收移动通信终端的无线基带模 块SIM卡接口的重置信号，
4)微控制器的输入输出接口连接于嵌入式SIM卡的相应接口，包括电源供应VCC接口， 数据输入输出IO接口，时钟信号CLK接口，重置信号RST接口共四个接口， a)电源供应VCC接口是作为微控制器的输出口，用于控制向嵌入式SIM卡供电，满足SIM 卡接口的激活和去激活过程的电气时序要求，
b)数据IO接口既可以作为微控制器的输出口，使得微控制器可以向嵌入式SIM卡直接 发送控制命令或者数据，或转发无线基带模块向嵌入式SIM卡发出的控制命令或者数据，也 可以作为微控制器的输入口，使得微控制器可以读取嵌入式SIM卡对控制命令的回复响应 数据，
c)时钟信号CLK接口是作为微控制器的输出口，用于向嵌入式SIM卡提供其运行时所需 要的时钟信号，
d)重置信号RST接口是作为微控制器的输出口，用于在需要的时候向嵌入式SIM卡发送 重置信号。
2.根据如权利要求1所述的移动通信终端的微控制器，其特征在于，所述微控制器还还 连接于一个无线通信接口，所述无线通信接口的功能在于， 1)微控制器通过无线通信接口，无线远程地从其它的SIM卡中获得存储在其中的SIM卡 文件系统的数据，
2)微控制器通过无线通信接口，无线传输转发其从移动通信终端的无线基带模块SIM 卡接口读取的SIM卡控制命令和SIM卡命令程序运行所需要的输入参数， 3)微控制器通过无线通信接口，无线接收SIM卡控制命令的回复响应数据，并转发给移 动通信终端无线基带模块SIM卡接口，
4)微控制器通过无线通信接口，无线传输其从嵌入式SIM卡读取的SIM卡文件系统的数 据，
5)微控制器通过无线通信接口，无线接收SIM卡控制命令和SIM卡命令程序运行所需要 的输入参数，并转发给嵌入式SIM卡，
权　利　要　求　书 | 1/6 页
CN 106028304 A

6)微控制器通过无线通信接口，无线传输转发其从嵌入式SIM卡读取的控制命令的回 复响应数据。
3 .根据如权利要求1所述的移动通信终端的微控制器，其特征在于，所述微控制器在移 动通信终端无线基带模块的SIM卡接口和嵌入式SIM卡之间，在移动通信终端无线基带模块 的SIM卡接口和如权利要求2所述的无线通信接口之间，在如权利要求2所述的无线通信接 口和嵌入式SIM卡之间转发它们之间的数据交换，使得数据转发的时间延迟和传输差错都 在SIM应用协议的范围内。
4 .根据如权利要求1所述的移动通信终端的微控制器，其特征在于，所述微控制器还连 接于一个移动通信终端SIM卡控制器，所述移动通信终端SIM卡控制器向所述微控制器发送 控制命令，控制所述微控制器的工作状态，包括，
1)向微控制器发送命令，使得移动通信终端接入蜂窝移动通信网络的SIM卡数据都是 通过嵌入式SIM卡获得的，
2)向微控制器发送命令，使得移动通信终端接入蜂窝移动通信网络的SIM卡数据都是 通过如权利要求2所述的无线通信接口，从其它的SIM卡远程地获得的， 3)向微控制器发送命令，读取嵌入式SIM卡的数据，并通过无线接口，远程地提供SIM卡 数据给其它的移动通信终端使用，接入蜂窝移动通信网络， 4)向微控制器发送命令，使得移动通信终端使用嵌入式SIM卡数据接入蜂窝移动通信 网络的同时，也通过如权利要求2所述的无线通信接口远程地提供嵌入式SIM卡数据给其它 的移动通信终端使用，
5)向微控制器发送命令，使得移动通信终端通过如权利要求2所述的无线通信接口远 程地使用其它的SIM卡数据接入蜂窝移动通信网络的同时，也通过如权利要求2所述的无线 通信接口远程地提供嵌入式SIM卡数据给其它的移动通信终端使用。
5 .根据如权利要求1所述的微控制器，其特征在于，所述微控制器通过和嵌入式SIM卡 之间的连接，向嵌入式SIM卡发送控制命令，读取嵌入式SIM卡文件系统的文件数据，存储在 所述微控制器的存储器中，所述文件数据的读取是通过如下步骤进行的， 1)微控制器在获得电源供应，运行其中的软件功能程序， 2)微控制器按照智能卡上电激活时序，向嵌入式SIM卡提供电源供应，时钟信号，重置 信号，上电激活嵌入式SIM卡，
3)微控制器通过和嵌入式SIM卡的数据IO接口，读取嵌入式SIM卡的重置回复数据ATR (Answer To Reset)，存储在微控制器的存储器中， 4)微控制器根据读取的重置回复数据内容，还可以和嵌入式SIM卡之间有一个协议参 数选择过程PPS(Protocol Parameter Selection)，完成嵌入式SIM卡的初始化过程， 5)微控制器作为一个读卡器，向嵌入式SIM卡发送控制命令，读取SIM卡文件系统的文 件数据，
6)微控制器把读取到的嵌入式SIM卡文件系统的文件数据存储在其存储器中。 6.根据如权利要求1所述的微控制器，其特征在于，所述微控制器通过如权利要求2所 述的无线通信接口，无线接收其它SIM卡文件系统的文件数据，存储在所述微控制器的存储 器中，在存储器中的其它SIM卡文件系统的文件数据可以是多个不同的SIM卡的文件数据。 7 .根据如权利要求1所述的微控制器，其特征在于，所述微控制器向移动通信终端提供
权　利　要　求　书 | 2/6 页

嵌入式SIM卡的数据，使得移动通信终端可以通过如下所述步骤接入蜂窝移动通信网络， 1)微控制器监听移动通信终端的无线基带模块SIM卡接口，等待接收CLK接口的时钟信 号，
2)如果微控制器监测到无线基带模块的时钟信号，就启动和无线基带模块SIM卡接口 的数据IO接口，重置RST接口，读取这些接口的输出信号， 3)微控制器如果检测到和无线基带模块SIM卡接口的重置RST接口的重置信号，就通过 和无线基带模块的数据IO接口，回复给无线基带模块SIM卡接口一个回复重置数据， 4)微控制器在回复重置数据后从第1步骤开始，重新监听无线基带模块SIM卡接口的时 钟信号CLK接口，等待接收时钟信号，
5)微控制器如果没有检测到和无线基带模块SIM卡接口的重置RST接口的重置信号，就 通过和无线基带模块的数据IO接口，读取无线基带模块SIM卡接口发给嵌入式SIM卡的控制 命令，
6)当微控制器读取到SIM卡控制命令后，根据该控制命令的类型，从不同的地方获取该 控制命令的回复响应数据，
7)如果SIM卡控制命令的回复响应数据是可以从嵌入式SIM卡中直接读取出来的数据， 微控制器就直接从其存储器中读取这些数据并回复给无线基带模块，然后从第1步骤开始， 重新监听无线基带模块SIM卡接口的时钟信号CLK接口，等待接收时钟信号， 8)如果SIM卡控制命令的回复响应数据只能通过在嵌入式SIM卡中内部运行程序才能 得到，微控制器就把该控制命令和嵌入式SIM卡运行程序所需要的输入参数发送给嵌入式 SIM卡，
9)微控制器通过嵌入式SIM卡的时钟CLK接口，向嵌入式SIM卡输出时钟信号， 10)微控制器通过嵌入式SIM卡的数据IO接口，向嵌入式SIM卡转发从无线基带模块SIM 卡接口读取读的控制命令以及运行该控制命令所需要的输入数据， 11)微控制器等待嵌入式SIM卡对控制命令的回复响应，并启动一个等待时间计时器， 12)如果等待超时，微控制器就停止向嵌入式SIM卡输出时钟信号，结束和嵌入式SIM卡 的数据交换，
13)微控制器通过和无线基带模块的数据IO接口，回复一个“SIM卡数据读取错误”的错 误消息给无线基带模块，
14)微控制器在回复错误给无线基带模块后，结束该控制命令的会话周期，从第1步骤 开始，重新监听无线基带模块的CLK时钟接口，等待接收时钟信号， 15)如果等待没有超时嵌入式SIM卡就有回复响应数据，微控制器通过嵌入式SIM卡的 数据IO接口，读取嵌入式SIM卡对控制命令的回复响应数据， 16)微控制器通过和无线基带模块的数据IO接口，向无线基带模块转发嵌入式SIM卡的 回复响应数据，
17)微控制器停止向嵌入式SIM卡输出时钟信号，结束和嵌入式SIM卡的数据交换， 18)微控制器从第1步骤开始，重新监听无线基带模块的时钟信号CLK接口，等待下一次 时钟信号，启动一个新的SIM卡控制命令的会话周期。
8.根据如权利要求1所述的微控制器，其特征在于，所述微控制器通过如权利要求2所 述的无线通信接口向移动通信终端提供其它SIM卡的数据，使得移动通信终端可以通过如
权　利　要　求　书 | 3/6 页

下所述步骤接入蜂窝移动通信网络的，
1)微控制器通过无线通信接口，远程获得其它SIM卡的文件数据参数，所述文件数据参 数能够标识不同的SIM卡，
2)微控制器检查其存储器中是否具有所述SIM卡数据的备份拷贝，如果没有，就通过无 线通信接口，无线获得该SIM卡的所有能够被外部设备读取的数据，存储在存储器中，等待 使用，并监听无线基带模块SIM卡接口，等待接收CLK接口的时钟信号，如果收到无线基带模 块的时钟信号，微控制器启动和无线基带模块SIM卡接口的数据IO接口，重置RST接口，读取 这些接口的输出信号，
3)如果微控制器的存储器中具有该SIM卡数据的备份拷贝，微控制器就直接监听无线 基带模块SIM卡接口，等待接收CLK接口的时钟信号，如果收到无线基带模块的时钟信号，就 启动和无线基带模块SIM卡接口的数据IO接口，重置RST接口，读取这些接口的输出信号， 4)微控制器如果检测到和无线基带模块SIM卡接口的重置RST接口的重置信号，就通过 和无线基带模块的数据IO接口，回复给无线基带模块SIM卡接口一个回复重置数据， 5)微控制器在回复重置数据后从第3步骤开始，重新监听无线基带模块SIM卡接口的时 钟信号CLK接口，等待接收时钟信号，
6)微控制器如果没有检测到和无线基带模块SIM卡接口的重置RST接口的重置信号，就 通过和无线基带模块的数据IO接口，读取无线基带模块SIM卡接口发给送的SIM卡控制命令 数据，
7)微控制器读取到SIM卡控制命令后，根据该控制命令的类型，从不同的地方获取该控 制命令的回复响应数据，
8)如果SIM卡控制命令的回复响应数据是那些可以从SIM卡中直接读取出来的数据，微 控制器就直接从其存储器中读取这些数据并回复给无线基带模块，然后从第3步骤开始，重 新监听无线基带模块SIM卡接口的时钟信号CLK接口，等待接收时钟信号， 9)如果SIM卡控制命令的回复响应数据只能通过在远端其它的SIM卡内部运行程序才 能得到，微控制器就把该控制命令和运行该控制命令所需要的输入参数，无线传输送给该 SIM卡，
10)微控制器通过无线通信接口，等待接收SIM卡控制命令的回复响应数据，并启动一 个等待时间计时器，
11)如果等待超时，微控制器就停止通过无线通信接口接收回复响应数据， 12)微控制器通过和无线基带模块的数据IO接口，回复一个“SIM卡数据读取错误”的错 误消息给无线基带模块，结束和该SIM卡控制命令的会话周期， 13)微控制器在回复错误给无线基带模块后，从第3步骤开始，重新监听和无线基带模 块的CLK时钟接口，等待接收下一次时钟信号，
14)如果等待没有超时微控制器就通过无线通信接口接收到SIM卡控制命令的回复响 应数据，微控制器通过和无线基带模块的数据IO接口，向无线基带模块转发其接收到的回 复响应数据，
15)微控制器停止通过无线通信接口接收数据，结束该SIM卡控制命令的会话周期。 16)微控制器从第3步骤开始，重新监听无线基带模块的时钟信号CLK接口，等待下一次 时钟信号，启动一个新的SIM卡控制命令的会话周期。
权　利　要　求　书 | 4/6 页

9.根据如权利要求1所述的微控制器，其特征在于，所述微控制器通过如权利要求2所 述的无线通信接口向其它的移动通信终端提供嵌入式SIM卡的数据，使得其它的移动通信 终端可以通过如下所述步骤接入蜂窝移动通信网络，
1)微控制器通过无线通信接口，向其它的移动通信终端无线远程地提供嵌入式SIM卡 文件系统的文件数据，这些SIM卡文件数据是存储微控制器的存储器中的，包括那些所有能 够被外部设备读取的SIM卡文件数据，
2)微控制器通过无线通信接口，等待接收其它的移动通信终端无线传输过来的SIM卡 控制命令或者控制命令的输入数据，这些控制命令的回复响应数据需要在嵌入式SIM卡运 行SIM卡程序才能得到，
3)微控制器接收到其它的移动通信终端无线传输过来的SIM卡控制命令或者控制命令 的输入数据后，首先通过和嵌入式SIM卡的时钟CLK接口，向嵌入式SIM卡提供时钟信号， 4)微控制器通过和嵌入式SIM卡的数据IO接口，向嵌入式SIM卡转发从无线通信接口接 收到的控制命令或者控制命令的输入数据，
5)微控制器等待嵌入式SIM卡的程序运行结果，并启动一个等待计时器， 6)如果等待超时微控制器仍然没有收到嵌入式SIM卡对控制命令的回复响应数据，就 停止向嵌入式SIM卡提供时钟信号，结束和嵌入式SIM卡的数据交换， 7)微控制器通过无线通信接口，向其它的移动通信终端传输一个SIM卡数据获取的错 误消息，并结束该SIM卡控制命令的会话周期，
8)微控制第2步骤开始，重新监听无线通信接口，等待接收其它的移动通信终端无线传 输过来的SIM卡控制命令或者控制命令的输入数据，
9)如果微控制器没有等待超时就收到嵌入式SIM卡对控制命令的回复响应数据，就通 过无线通信接口，转发该控制命令的回复响应数据，结束命令会话周期， 10)微控制器停止向嵌入式SIM卡提供时钟信号，结束和嵌入式SIM卡的数据交换， 11)微控制器第2步骤开始，重新监听无线通信接口，等待接收其它的移动通信终端无 线传输过来的SIM卡控制命令或者控制命令的输入数据。
10 .根据如权利要求1所述的微控制器，其特征在于，所述微控制器运行有一个软件功 能模块，所述软件功能模块应用标准的SIM卡应用工具箱(SAT，SIM Application Toolkit) 接口，向移动通信终端的无线基带模块SIM卡接口发送SAT命令，为用户提供SAT的应用功 能，所述软件功能模块是通过如下流程来实现的，
1)移动通信终端通过微控制器提供的SIM卡数据，接入蜂窝移动通信网络， 2)微控制器根据移动通信终端SIM卡控制器的功能需要，设置SIM卡应用工具箱(SAT) 标识变量，来标识微控制器是否具有SAT数据需要传输给移动通信终端的无线基带模块， 3)移动通信终端的无线基带模块通过和微控制器的数据IO接口，读取SIM卡运行状态 信息(status)，4)微控制器读取SIM卡应用工具箱(SAT)标识变量。
5 )如果标识变量指示微控制器没有SAT数据需要传输给移动通信终端的无线基带模 块，微控制器就通过数据IO接口回复无线基带模块，SIM卡运行状态正确，
6 )如果标识变量指示微控制器具有SAT数据需要传输给移动通信终端的无线基带模 块，微控制器就通过数据IO接口回复无线基带模块，SIM卡有进一步的数据需要传输给无线 基带模块，
权　利　要　求　书 | 5/6 页

7)移动通信终端的无线基带模块通过数据IO接口，向微控制器发送SIM卡数据获取命 令(fetch，0x12)，获取SAT命令的数据，
8)微控制器通过数据IO接口，回复移动通信终端的无线基带模块的SIM卡数据获取命 令，向无线基带模块发送SAT命令的数据，
9)微控制器根据进一步移动通信终端SIM卡控制器的功能需要，重新设置或清除第2) 步骤的SAT命令标志变量。
权　利　要　求　书 | 6/6 页

一种具有嵌入式SIM卡数据无线传输功能的移动通信终端

技术领域
[0001] 本发明属于移动通信终端领域。具体地说，本发明涉及一种具有嵌入式SIM卡数据 无线传输功能的移动通信终端，使得其它另外的移动通信终端可以通过无线的方式，远程 地使用嵌入式SIM卡数据接入蜂窝移动通信网络。并且该移动通信终端还可以通过无线接 收SIM卡数据，不使用固定在其中的嵌入式SIM卡，而远程地使用其它另外的SIM卡数据接入 蜂窝移动通信网络。

背景技术
[0002] 随着手机特别是智能手机的功能变得越来越强大，其在人们的生活中也越来越重 要。人们通过智能手机完成各种各样的移动应用，除了用于基本的语音通话和文字消息外， 还用智能手机进行观看视频，浏览照片，浏览网页，移动支付等。智能手机正逐步成为人们 日常生活中一个必需的个人设备。
[0003] 为了使智能手机(包括其它一些能够接入蜂窝移动通信网络的用户终端设备如移 动固话，平板电脑，笔记本电脑等，以下都简称手机)接入蜂窝移动通信网络，每一个手机都 需要一个从移动通信运营商处获得的SIM卡(用户身份识别卡，包括USIM卡，为简便以下都 统一简称SIM卡)，得到适当的网络接入授权后，才能够使用移动通信服务。在现有的技术实 现中，在手机的内部都有一个SIM卡卡座，当SIM卡插入卡座的卡槽后，卡座的触点就和SIM 卡建立了电路连接，手机的无线基带模块就能够读取SIM卡中的数据，接入蜂窝移动通信网 络。SIM卡和手机之间的接口是标准的智能卡一终端设备接口，满足国际标准ISO/IEC 7816 定义的传输协议和ETSI TS 102 221，3GPP TS 31 .102等定义的电信应用协议。这样的标准 接口使得任何一个SIM卡都可以插入任何一个手机使用，方便了用户对使用手机的选择。但 是在用户使用手机的过程中，SIM卡需要一直固定在手机内部，并且被一个手机独占使用。
[0004] 随着物联网技术技术的发展和物联网业务的开展，越来越多的物联网设备也接入 了蜂窝移动通信网络，物联网设备之间的通信称为M2M通信(Machine to Machine)。这样， 移动通信就不仅仅只是用于人们之间的通信，移动通信终端设备也不仅仅只是手机，也包 括能够接入蜂窝移动通信网络的物联网设备。为了简便起见，在本发明中，以下都把它们统 一简称移动通信终端(它们都是通过接入蜂窝移动通信网络而建立网络连接的)。
[0005] 接入蜂窝移动通信网络的物联网设备也需要一个SIM卡来对设备进行身份标识， 以便得到移动通信网络的身份认证和接入授权。对于物联网设备，除了可以使用传统的和 手机一样的可移动的独立SIM卡外，还可以使用嵌入式SIM卡(eSIM/eUSIM，embedded SIM/ USIM)。嵌入式SIM卡和终端设备的物理电气连接和传统的可移动独立SIM卡是一样的，只不 过嵌入式SIM卡是在设备的制造过程中固定在设备在内部，不能够在不同设备之间很容易 地更换。嵌入式SIM卡这样的设计可以更好的适应不同的使用环境，例如在车载环境中，抗 震动性能更好。另一方面，移动通信运营商还可以通过无线的方式，远程的更新嵌入式SIM 卡内部的数据(remote provisioning)，使得多个运营商的网络数据(operator profile) 都可以存储在同一个嵌入式SIM卡中。用户在更换移动通信服务提供的时候，只需要重新配
说　明　书 | 1/16 页

置一下SIM的数据，就可以很方便的在多个运营商之间进行选择和更换，而不需要象传统的 手机那样，物理地更换SIM卡。因为嵌入式SIM卡的方便性和灵活性，手机特别是智能手机也 越来越多的使用嵌入式SIM卡。嵌入式SIM卡的技术细节在相关的国际技术规范中，例如 ETSI TS 102 671等有详细的定义。
[0006] 无论是传统的可移动独立SIM卡还是固定在设备内部的嵌入式SIM卡，他们的功能 是一样的，主要具有两种功能。第一个功能是移动用户(包括物联网设备)的身份标识作用。 也就是说，SIM卡有一个唯一的参考号来标识SIM卡本身，从而标识与此SIM卡相关联的移动 业务使用，使得移动业务的使用都被正确地授权和计费。由于这个身份标识对移动业务的 使用是非常重要的，身份标识除了是唯一的外，还是不可更改的。第二个功能是身份鉴权认 证的作用，使得移动通信终端对移动网络的接入和使用是安全而有效的。也就是说，要确保 SIM卡所标识的身份是真实而可靠的，而不是虚假的身份。这个身份标识的真实性通常是通 过只共享于移动通信网络和SIM卡之间的鉴权密钥和密码算法，并进行问题质询一回答响 应的方式来确保的。因为SIM卡的功能对于网络安全和业务使用安全来说是非常重要的，因 此SIM卡的功能都是通过专用的硬件模块和与此专用硬件相应的软件功能模块来共同实现 的，而不是仅仅只通过软件功能，在通用的硬件上与其它的软件功能模块共享硬件而实现 其功能。SIM卡这样的实现方式充分确保了SIM卡的身份标识的真实性和身份鉴权认证的安 全性。
[0007] 在移动通信终端在使用过程中，为了保持和网络的连接，SIM卡和移动通信终端需 要始终在一起，成为一个完整的不可分割的用户设备整体供用户使用。移动通信终端只能 使用固定在其内的SIM卡(插入SIM卡插槽的可移动式独立SIM卡或者固定在其中的嵌入式 SIM卡)，并且SIM卡也只能被该移动通信终端独占使用。SIM卡和移动通信终端之间的连接 是固定的电路连接，它们之间的数据交换是一种有线通信的方式。虽然嵌入式SIM卡中的运 营商网络数据可以更改或者多个运营商网络数据共存，但是这种使用方式就限制了SIM卡 和移动通信终端之间是固定的一一对应关系。实际上，SIM卡的主要功能是移动通信业务使 用者和移动通信服务提供商之间的一种关系，当移动通信使用者需要更换移动通信服务提 供商或者更改同一个移动通信服务提供商的不同服务类型时，就更换一个不同的SIM卡或 者更新嵌入式SIM卡里面的运营商网络数据，与具体的移动通信终端设备没有关系。因此， 对于移动通信终端来说，通过其它的方式，就可以使用一种更为简单，方便，灵活的方式来 使用SIM卡的数据接入蜂窝移动通信网络，没有必要和一个固定的物理形态的SIM卡建立固 定的一一对应关系。
[0008] 在中国发明申请201410653530 .6“一种便携式UICC卡用户终端设备及其身份认证 系统”中，公开了一种新的在UICC卡和读卡器之间的无线通信接口，使得读卡器在读取UICC 卡中的用户身份数据时，可以使用它们之间的无线通信接口，从而避免了它们之间的触点 接触式通信。这样，在用户使用业务过程中，UICC卡和读卡器可以物理地分离，极大地方便 了用户对移动业务如移动通信、移动金融等的使用。因此，对于移动通信终端来说，就可以 使用这个无线UICC传输接口，使用其它的SIM卡数据接入蜂窝移动通信网络，而不是局限于 仅仅使用固定在其中的SIM卡。这种移动通信终端自由选择使用SIM卡数据的方式极大地方 便了用户对移动业务的使用。
[0009] 在中国发明申请201510830053 .0“一种具有无线SIM传输功能的手表手机”中，公
说　明　书 | 2/16 页

开了一种共享手表手机中的SIM卡数据的方法。通过在手机无线基带模块的SIM卡接口和 SIM卡卡座之间增加一个具有无线通信功能的微控制器(MCU，Micro-Controller Unit)模 块，使得在不影响手表手机原来的蜂窝无线通信功能的情况下，其它的手机还可以通过微 控制器的无线通信接口，远程地使用手表手机中SIM卡接入蜂窝移动通信网络。在这种情况 下，微控制器模块就相当于一个SIM卡数据的接入服务器，在多个移动通信终端之间时分复 用(TDM，Time Division Multiplexing)地使用同一个SIM卡的数据。同样，对于具有嵌入式 SIM卡的移动通信终端，也可以通过无线通信接口，使得其它另外的移动通信终端也可以使 用其中嵌入式SIM卡的数据，接入蜂窝移动通信网络。
[0010] 本发明的主要目的就是公开一种移动通信终端设备，该移动通信终端设备具有嵌 入式SIM卡，除了具有通常的移动通信终端嵌入式SIM卡的功能外，还具有一个新的无线通 信功能模块，使得嵌入式SIM卡数据具有无线传输功能。通过嵌入式SIM卡数据的无线传输， 其它的移动通信终端可以远程地使用嵌入式SIM卡的数据接入蜂窝移动通信网络。这样，固 定在移动通信终端内部的嵌入式SIM卡虽然不能够像传统的可移动式独立SIM卡那样，从一 个设备中拔出来再插入另外的设备使用，但是它可以通过无线通信接口提供给其他移动通 信终端设备使用。同一个嵌入式SIM卡除了可以被一个移动通信终端本身使用外，还可以和 其它移动通信终端共享使用。这种共享使用是不同的移动通信终端分时间片段地分别使用 同一个嵌入式SIM卡，在任意的时间点上，嵌入式SIM卡仍然是被某一个移动通信终端独占 使用，只不过可以通过无线通信接口，在不同的移动通信终端之间快速地切换。在用户的宏 观使用体验上，由于这种切换的时间很短，就好像每一个移动通信终端都独立地使用一个 SIM卡一样。
[0011] 另一方面，通过本发明的无线通信功能模块，移动通信终端还可以不使用固定在 其中的嵌入式SIM卡，而通过其无线通信接口，远程地使用其它SIM卡数据接入蜂窝移动通 信网络。在这种使用方式下，无线通信功能模块本身除了具有数据的无线传输和接收的功 能外，相对于移动通信终端来说，其还具有SIM卡的功能，只不过所使用的SIM卡数据都是通 过无线通信的方式从其它SIM卡获得的。对于移动通信终端来说，就好像直接使用其它的 SIM卡一样。这样，移动通信终端就可以在不更换SIM卡或者重新配置嵌入式SIM卡的数据的 情况下，就可以使用其它的SIM卡数据接入蜂窝移动通信网络，极大地方便了用户对移动通 信业务的使用。
[0012] 本发明的移动通信终端使用SIM卡数据的这两种方式，实际上相当于使移动通信 终端的嵌入式SIM卡处于两种状态，即服务器端状态和客户端状态。当嵌入式SIM卡处于服 务器端状态时，固定在其中的嵌入式SIM卡数据除了供移动通信终端本机使用外，还可以供 其它的移动通信终端使用。嵌入式SIM卡处于客户端状态时，移动通信终端本机就不使用固 定在其中的嵌入式SIM卡数据，而使用其它的SIM卡数据。本发明还公开了移动通信终端的 一个嵌入式SIM卡控制器，使得移动通信终端可以根据使用的不同需要，在这两种状态之间 切换，甚至使得嵌入式SIM卡同时工作在这两种状态。当移动通信终端本机在通过无线通信 接口使用其它的SIM卡数据的同时，还可以把固定在其中的嵌入式SIM卡数据无线地分享给 其它的移动通信终端使用。

发明内容

说　明　书 | 3/16 页

[0013] 对于通常的具有嵌入式SIM卡的移动通信终端来说，在其无线基带(baseband，连 接蜂窝移动通信网络的通信功能模块)的SIM卡接口，有一个固定电路连接于嵌入式SIM卡。 嵌入式SIM卡和可移动的独立SIM卡具有相同的电气接口和通信协议接口，除了有些管理功 能不一样外(嵌入式SIM卡支持运营商数据的无线远程写入和多个运营商数据的选择)，对 移动通信终端的无线基带模块来说，都是以相同的方式使用SIM卡里的数据接入蜂窝移动 通信网络。因此，移动通信终端不需要关心其无线基带模块和SIM卡的连接方式，而只关心 是否能够及时有效的得到正确的SIM卡数据。
[0014] 本发明的移动通信终端的无线基带模块不是直接和嵌入式SIM卡相连接，如图1所 示，在无线基带模块和嵌入式SIM卡之间，有一个微控制器。也就是说，微控制器是无线基带 模块和嵌入式SIM卡之间连接的一个桥梁，相对于无线基带模块来说，微控制器就是一个 SIM卡，相对于嵌入式SIM卡来说，微控制器就是一个SIM卡读卡器(无线基带模块的SIM卡接 口)。无线基带模块和嵌入式SIM卡之间所有的数据交换，都可以经过微控制器的透明转发， 就好像它们之间不存在微控制器而直接电路连接一样。除此之外，这个微控制器还连接于 无线通信接口和移动通信终端的SIM卡控制器，来共同完成本发明功能。图1中的微控制器 是本发明的功能模块和它们之间的连接，具有如下功能：
[0015] 1 .微控制器连接于移动通信终端的嵌入式SIM卡，作为一个完整功能的读卡器，控 制嵌入式SIM卡的一切行为。包括卡激活和去激活，向嵌入式SIM卡发起控制命令而开始一 个卡命令会话周期，读取嵌入式SIM卡对控制命令的回复响应数据。还包括嵌入式SIM卡运 行的其它一些条件，如向嵌入式SIM卡供电，输出时钟信号，发送重置信号等等。在嵌入式 SIM卡看来，微控制器就完全等同于无线基带模块SIM卡接口，对其本身的行为没有任何影 响。
[0016] 2 .微控制器连接于移动通信终端的无线基带模块SIM卡接口，作为一个完整功能 的SIM卡，响应无线基带模块向SIM卡发起的一切控制命令。包括读取无线基带模块SIM卡接 口发起的SIM卡命令会话和对命令进行回复响应，也包括读取其它的控制信号如时钟信号， 重置信号等以及对控制信号的相应回复响应。在无线基带模块SIM卡接口看来，微控制器就 完全等同于一个SIM卡，其行为模式和直接连接于SIM卡是一模一样的。
[0017] 3 .微控制器连接于无线通信接口，使得微控制器能够把无线通信接口当作一个 SIM卡控制命令接口。微控制器可以向无线通信接口发送SIM卡控制命令，也可以通过无线 通信接口接收对SIM卡控制命令的回复响应数据，获得移动通信终端接入蜂窝移动通信网 络所必需的SIM卡内部数据。当然，微控制器向无线通信接口发送SIM卡控制命令的时候，和 直接向嵌入式SIM卡发送控制命令是不一样的，一些附加的无线传输控制数据可以叠加在 SIM卡控制命令之上，以增加无线传输的可靠性。在无线通信接口的接收端，这些附加的无 线传输控制数据在传送给SIM卡之前被去掉，而只有直接的卡命令数据被传输给SIM卡。其 主要目的是微控制器可以通过无线通信接口获得SIM卡内部数据，而控制命令的传输格式 可以通过无线传输的接收端被屏蔽掉。
[0018] 4 .微控制器连接于移动通信终端SIM卡控制器，使得移动通信终端可以使用不同 的SIM卡数据接入蜂窝移动通信网络。SIM卡控制器一方面提供用户使用交互界面，用户可 以选择使用移动通信终端内部的嵌入式SIM卡，或者通过无线通信接口，远程地使用其它的 的SIM卡接入蜂窝移动通信网络。另一方面，SIM卡控制器通过向微控制器发送控制命令，控
说　明　书 | 4/16 页

制微控制器当收到无线基带模块SIM卡接口发起的SIM卡命令会话时，是把该SIM卡命令传 送给嵌入式SIM卡还是无线通信接口，这就决定了移动通信终端是使用嵌入式SIM卡还是远 程地通过无线通信接口使用其它的SIM卡里的数据接入蜂窝移动通信网络。另外，SIM卡控 制器还负责控制嵌入式SIM卡的数据准备和初始化工作相关的交互工作，包括与移动通信 网络单元MNO( Mobile Network Operator )，SM-DM( Subscription Manager Data Preparation)和SM-SR(Subscription Manager Secure Routing)的接口协议，都是通过本 发明的微控制器的间接转发，进而和嵌入式SIM卡通信来完成的。与无无线基带模块SIM卡 接口和嵌入式SIM卡的连接一样，尽管它们之间的连接是通过微控制器间接相连的，但是微 控制器只是起着一个协议消息的转发和桥梁的作用，对于连接的双方来说都是透明的，就 好像它们是直接电路连接一样。当然，嵌入式SIM卡的运营商数据(operator profile)的初 始化工作(remote provisioning)也可以不通过微控制器，而通过和移动通信终端的其它 接口的通信数据交换而完成的。这样，移动通信终端SIM卡控制器只是控制微控制器的工作 状态，例如是SIM卡数据的服务器端或者客户端，或者移动通信终端是是用嵌入式SIM卡还 是其它的SIM卡数据接入蜂窝移动通信网络。
[0019] 本发明的微控制器和嵌入式SIM卡之间的连接是标准的智能卡一终端设备连接， 微控制器是一个终端设备，而嵌入式SIM卡是一个智能卡，在标准ETSI TS 102 221中有详 细的电路连接定义。图2是本发明的微控制器和嵌入式SIM卡之间的电路连接功能图，根据 嵌入式SIM卡在移动通信终端中的功能不同，在嵌入式SIM卡的8个触点连接中，C4，C6和C8 是可选的连接，对于只提供蜂窝移动通信网络接入的基本功能的嵌入式SIM卡，这3个触点 可以不用连接于微控制器。其余的5个连接是必需的连接，以保持本发明的嵌入式SIM卡正 确工作，具有如下的连接和功能：
[0020] 1 .嵌入式SIM卡的电源负极GND连接(C5触点)连接于设备的电源负极，由于整个设 备共享电源负极GND，因此C5触点既可以直接连接于微控制器的电源负极，也可以连接于移 动通信终端的整个电源供应的电源负极，在实际的产品电路板设计中，可以根据设计需要 灵活布线，以获得最佳的设备整体性能。
[0021] 2 .嵌入式SIM卡的电源供应正极VCC(C1触点)连接于微控制器的输出接口，由微控 制器控制向嵌入式SIM卡的电源供应。在标准的智能卡一终端设备的接口中，为了避免一些 不确定的状态，定义了智能卡的激活和去激活时间序列，这些时间序列规定了智能卡的电 气时态，与智能卡插入卡槽时的机械触点建立的时序没有关系。嵌入式SIM卡虽然固定在设 备内部，没有触点的机械连接建立过程，但是什么时候向嵌入式SIM卡供电以及什么时候向 嵌入式SIM卡断电都应当遵守这些标准。微控制器控制嵌入式SIM卡的电源供应VCC接口，以 遵守ISO/IEC 7816标准中定义的智能卡的激活和去激活时间序列。
[0022] 3 .嵌入式SIM卡的数据IO接口(C7触点)连接于微控制器，既可以作为微控制器的 输出口，使得微控制器可以向嵌入式SIM卡直接发送控制命令或者数据，或转发无线基带模 块SIM卡接口向嵌入式SIM卡发出的控制命令或者数据。也可以作为微控制器的输入口，使 得微控制器可以读取嵌入式SIM卡对控制命令的回复响应数据。在嵌入式SIM卡看来，微控 制器的功能就是一个移动通信终端的无线基带模块SIM卡接口，嵌入式SIM卡自身的行为与 它和一个无线基带模块SIM卡接口的命令会话交互行为是一样的。嵌入式SIM卡与一个无线 基带模块SIM卡接口进行命令会话和它与微控制器的数据IO接口进行命令会话是透明的，
说　明　书 | 5/16 页
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

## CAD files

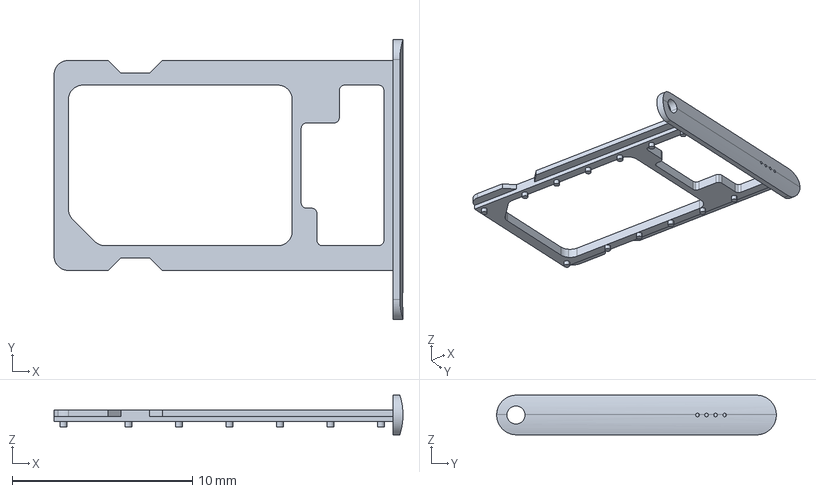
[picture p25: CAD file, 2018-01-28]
doc/hardware/wireless_SIM_connector_igs_20171211/wirelessSIM_iPhone7_20171211.igs
19.3 x 15.5 x 2.20 mm

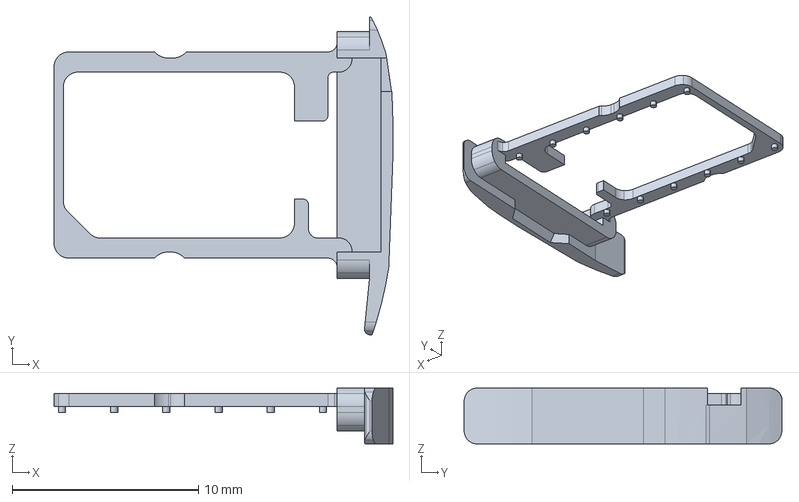
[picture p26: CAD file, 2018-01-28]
doc/hardware/wireless_SIM_connector_igs_20171211/wirelessSIM_HWwatch_20171211.igs
18.2 x 17.0 x 3.00 mm

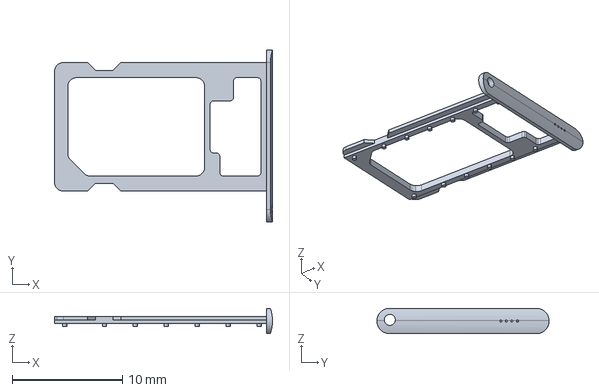
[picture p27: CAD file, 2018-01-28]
doc/hardware/wireless_SIM_connector_igs_20171211/wirelessSIM_iPhone8P_20171211.igs
19.7 x 15.6 x 2.30 mm

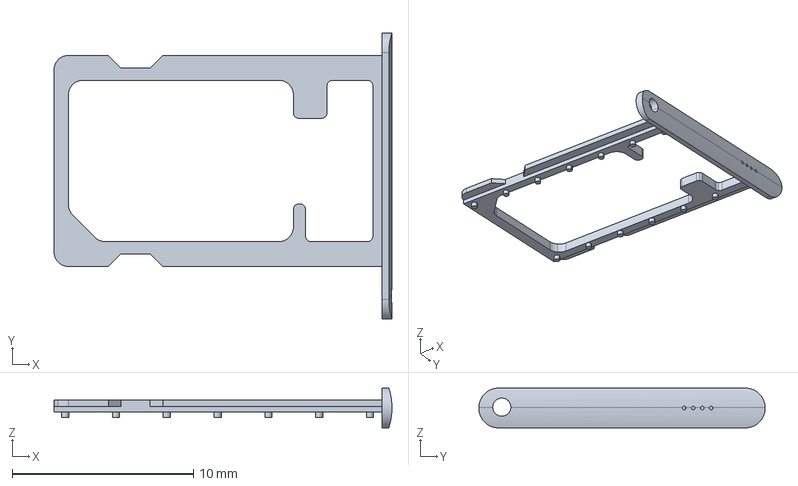
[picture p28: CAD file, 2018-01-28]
doc/hardware/wireless_SIM_connector_igs_20171211/wirelessSIM_iPhoneX_20171211.igs
18.6 x 15.8 x 2.20 mm

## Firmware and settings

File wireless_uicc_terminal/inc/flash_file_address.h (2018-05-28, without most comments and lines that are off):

#define FLASH_FILE_ADDRESS_H__
#include "define_config.h"
#include "nrf52.h"
#define FLASH_PAGE_SIZE                          (NRF_FICR->CODEPAGESIZE)
#define FLASH_PAGE_NUMBER                        (NRF_FICR->CODESIZE)
#define EF_FILES_START_PAGE                      (FLASH_PAGE_NUMBER - 4 - (FDS_VIRTUAL_PAGES * FDS_VIRTUAL_PAGE_SIZE * 4 / FLASH_PAGE_SIZE))
#define FCP_DATA_PAGE_FLASH_ADDR                 (FLASH_PAGE_SIZE * (EF_FILES_START_PAGE + 2))
#define BACKUP_DATA_USER_CONFIG_FLASH_ADDR       (FLASH_PAGE_SIZE * EF_FILES_START_PAGE)
#define USER_CONFIG_OFFSET_BYTES             0
#define USIM0_EF_OFFSET_BYTES                256
#define USIM1_EF_OFFSET_BYTES                640
#define USER_CONFIG_FLASH_ADDR       (FLASH_PAGE_SIZE * (EF_FILES_START_PAGE + 1) + USER_CONFIG_OFFSET_BYTES)
#define USIM0_EF_FLASH_ADDR          (FLASH_PAGE_SIZE * (EF_FILES_START_PAGE + 1) + USIM0_EF_OFFSET_BYTES)
#define USIM1_EF_FLASH_ADDR          (FLASH_PAGE_SIZE * (EF_FILES_START_PAGE + 1) + USIM1_EF_OFFSET_BYTES)
#define SMART_USIM_DEVICE_NAME_OFFSET_IN_CONFIG                 (USER_CONFIG_OFFSET_BYTES + 0)
#define USER_PASSWORD_OFFSET_IN_CONFIG                          (USER_CONFIG_OFFSET_BYTES + 16)
#define SYSTEM_KEY_OFFSET_IN_CONFIG                             (USER_CONFIG_OFFSET_BYTES + 32)
#define AUTH_CHALL_DATA_OFFSET_IN_CONFIG                        (USER_CONFIG_OFFSET_BYTES + 48)
#define LED_PATTERN_OFFSET_IN_CONFIG                            (USER_CONFIG_OFFSET_BYTES + 64)
#define DEVICE_LOG_ADD_OFFSET_IN_CONFIG                         (USER_CONFIG_OFFSET_BYTES + 80)
#define WIRELESS_SIM_ON_OFF_OFFSET_IN_CONFIG                    (USER_CONFIG_OFFSET_BYTES + 81)
#define USIM_SERVER_CALL_OFFSET_IN_CONFIG                       (USER_CONFIG_OFFSET_BYTES + 82)
#define BLE_ON_OFF_OFFSET_IN_CONFIG                             (USER_CONFIG_OFFSET_BYTES + 83)
#define BLE_BOND_DELETE_OFFSET_IN_CONFIG                        (USER_CONFIG_OFFSET_BYTES + 84)
#define WIRELESS_USIM_WORK_MODE_OFFSET_IN_CONFIG                (USER_CONFIG_OFFSET_BYTES + 85)
#define USIM_CLK_FREQ_OFFSET_IN_CONFIG                          (USER_CONFIG_OFFSET_BYTES + 86)
#define DEFAULT_USED_USIM_OFFSET_IN_CONFIG                      (USER_CONFIG_OFFSET_BYTES + 89)
#define USIM_DATA_MODE_OFFSET_IN_CONFIG                         (USER_CONFIG_OFFSET_BYTES + 90)
#define ICCID_2FE2_DATA_MODE_OFFSET_IN_CONFIG                   (USER_CONFIG_OFFSET_BYTES + 91)
#define AUTHEN_0x88_BLE_ON_OFF_OFFSET_IN_CONFIG                 (USER_CONFIG_OFFSET_BYTES + 92)
#define ICCID_2FE2_FIXED_DATA_OFFSET_IN_CONFIG                  (USER_CONFIG_OFFSET_BYTES + 93)
#define USER_CONFIG_ALL_BYTES_LENGTH                            103
#define SMART_USIM_DEVICE_NAME_FLASH_ADDR      (USER_CONFIG_FLASH_ADDR + SMART_USIM_DEVICE_NAME_OFFSET_IN_CONFIG)
#define USER_PASSWORD_FLASH_ADDR               (USER_CONFIG_FLASH_ADDR + USER_PASSWORD_OFFSET_IN_CONFIG)
#define SYSTEM_KEY_FLASH_ADDR                  (USER_CONFIG_FLASH_ADDR + SYSTEM_KEY_OFFSET_IN_CONFIG)
#define LED_PATTERN_FLASH_ADDR                 (USER_CONFIG_FLASH_ADDR + LED_PATTERN_OFFSET_IN_CONFIG)
#define DEVICE_LOG_ADD_FLASH_ADDR              (USER_CONFIG_FLASH_ADDR + DEVICE_LOG_ADD_OFFSET_IN_CONFIG)
#define WIRELESS_SIM_ON_OFF_FLASH_ADDR          (USER_CONFIG_FLASH_ADDR + WIRELESS_SIM_ON_OFF_OFFSET_IN_CONFIG)
#define USIM_SERVER_CALL_ON_OFF_FLASH_ADDR      (USER_CONFIG_FLASH_ADDR + USIM_SERVER_CALL_OFFSET_IN_CONFIG)
#define BLE_STATUS_ON_OFF_FLASH_ADDR            (USER_CONFIG_FLASH_ADDR + BLE_ON_OFF_OFFSET_IN_CONFIG)
#define BLE_BOND_DEL_STATUS_FLASH_ADDR          (USER_CONFIG_FLASH_ADDR + BLE_BOND_DELETE_OFFSET_IN_CONFIG)
#define WIRELESS_USIM_WORK_MODE_FLASH_ADDR      (USER_CONFIG_FLASH_ADDR + WIRELESS_USIM_WORK_MODE_OFFSET_IN_CONFIG)
#define PHONE_USIM_CLK_FREQ_FLASH_ADDR          (USER_CONFIG_FLASH_ADDR + USIM_CLK_FREQ_OFFSET_IN_CONFIG)
#define DEFAULT_USED_USIM_FLASH_ADDR            (USER_CONFIG_FLASH_ADDR + DEFAULT_USED_USIM_OFFSET_IN_CONFIG)
#define USIM_DATA_MODE_FLASH_ADDR                 (USER_CONFIG_FLASH_ADDR + USIM_DATA_MODE_OFFSET_IN_CONFIG)
#define ICCID_2FE2_DATA_MODE_FLASH_ADDR           (USER_CONFIG_FLASH_ADDR + ICCID_2FE2_DATA_MODE_OFFSET_IN_CONFIG)
#define AUTHEN_0x88_BLE_ON_OFF_FLASH_ADDR         (USER_CONFIG_FLASH_ADDR + AUTHEN_0x88_BLE_ON_OFF_OFFSET_IN_CONFIG)
#define ICCID_2FE2_FIXED_DATA_FLASH_ADDR           (USER_CONFIG_FLASH_ADDR + ICCID_2FE2_FIXED_DATA_OFFSET_IN_CONFIG)
#define ALL_USIM_EF_SIZE         247
#define ALL_USIM_EF_FLAG_SIZE    268
#define FILE_SIZE_2FE2           10
#define FILE_SIZE_2F05           4
#define FILE_SIZE_6F07           9
#define FILE_SIZE_6F08           33
#define FILE_SIZE_6F09           33
#define FILE_SIZE_6F31           1
#define FILE_SIZE_6F78           2
#define FILE_SIZE_6F7E           11
#define FILE_SIZE_6F73           14
#define FILE_SIZE_6F7B           12
#define FILE_SIZE_6FAD           4
#define FILE_SIZE_6F5C           3
#define FILE_SIZE_6F5B           6
#define FILE_SIZE_6FC4           46
#define FILE_SIZE_6F56           1
#define FILE_SIZE_4F20           9
#define FILE_SIZE_4F52           9
#define FILE_SIZE_6F42           40
#define EF_2FE2_OFFSET           (1)
#define EF_2F05_OFFSET           (11)
#define EF_6F07_OFFSET           (15)
#define EF_6F08_OFFSET           (24)
#define EF_6F09_OFFSET           (57)
#define EF_6F31_OFFSET           (90)
#define EF_6F78_OFFSET           (91)
#define EF_6F7E_OFFSET           (93)
#define EF_6F73_OFFSET           (104)
#define EF_6F7B_OFFSET           (118)
#define EF_6FAD_OFFSET           (130)
#define EF_6F5C_OFFSET           (134)
#define EF_6F5B_OFFSET           (137)
#define EF_6FC4_OFFSET           (143)
#define EF_6F56_OFFSET           (189)
#define EF_4F20_OFFSET           (190)
#define EF_4F52_OFFSET           (199)
#define EF_6F42_OFFSET           (208)
#define FLAG_2FE2_OFFSET         (ALL_USIM_EF_SIZE + 1)
#define FLAG_2F05_OFFSET         (ALL_USIM_EF_SIZE + 2)
#define FLAG_6F07_OFFSET         (ALL_USIM_EF_SIZE + 3)
#define FLAG_6F08_OFFSET         (ALL_USIM_EF_SIZE + 4)
#define FLAG_6F09_OFFSET         (ALL_USIM_EF_SIZE + 5)
#define FLAG_6F31_OFFSET         (ALL_USIM_EF_SIZE + 6)
#define FLAG_6F78_OFFSET         (ALL_USIM_EF_SIZE + 7)
#define FLAG_6F7E_OFFSET         (ALL_USIM_EF_SIZE + 8)
#define FLAG_6F73_OFFSET         (ALL_USIM_EF_SIZE + 9)
#define FLAG_6F7B_OFFSET         (ALL_USIM_EF_SIZE + 10)
#define FLAG_6FAD_OFFSET         (ALL_USIM_EF_SIZE + 11)
#define FLAG_6F5C_OFFSET         (ALL_USIM_EF_SIZE + 12)
#define FLAG_6F5B_OFFSET         (ALL_USIM_EF_SIZE + 13)
#define FLAG_6FC4_OFFSET         (ALL_USIM_EF_SIZE + 14)
#define FLAG_6F56_OFFSET         (ALL_USIM_EF_SIZE + 15)
#define FLAG_4F20_OFFSET         (ALL_USIM_EF_SIZE + 16)
#define FLAG_4F52_OFFSET         (ALL_USIM_EF_SIZE + 17)
#define FLAG_6F42_OFFSET         (ALL_USIM_EF_SIZE + 18)
#define USIM0_EF_2FE2_FLASH_ADDR (USIM0_EF_FLASH_ADDR + 1)
#define USIM0_EF_2F05_FLASH_ADDR (USIM0_EF_2FE2_FLASH_ADDR + FILE_SIZE_2FE2)
#define USIM0_EF_6F07_FLASH_ADDR (USIM0_EF_2F05_FLASH_ADDR + FILE_SIZE_2F05)
#define USIM0_EF_6F08_FLASH_ADDR (USIM0_EF_6F07_FLASH_ADDR + FILE_SIZE_6F07)
#define USIM0_EF_6F09_FLASH_ADDR (USIM0_EF_6F08_FLASH_ADDR + FILE_SIZE_6F08)
#define USIM0_EF_6F31_FLASH_ADDR (USIM0_EF_6F09_FLASH_ADDR + FILE_SIZE_6F09)
#define USIM0_EF_6F78_FLASH_ADDR (USIM0_EF_6F31_FLASH_ADDR + FILE_SIZE_6F31)
#define USIM0_EF_6F7E_FLASH_ADDR (USIM0_EF_6F78_FLASH_ADDR + FILE_SIZE_6F78)
#define USIM0_EF_6F73_FLASH_ADDR (USIM0_EF_6F7E_FLASH_ADDR + FILE_SIZE_6F7E)
#define USIM0_EF_6F7B_FLASH_ADDR (USIM0_EF_6F73_FLASH_ADDR + FILE_SIZE_6F73)
#define USIM0_EF_6FAD_FLASH_ADDR (USIM0_EF_6F7B_FLASH_ADDR + FILE_SIZE_6F7B)
#define USIM0_EF_6F5C_FLASH_ADDR (USIM0_EF_6FAD_FLASH_ADDR + FILE_SIZE_6FAD)
#define USIM0_EF_6F5B_FLASH_ADDR (USIM0_EF_6F5C_FLASH_ADDR + FILE_SIZE_6F5C)
#define USIM0_EF_6FC4_FLASH_ADDR (USIM0_EF_6F5B_FLASH_ADDR + FILE_SIZE_6F5B)
#define USIM0_EF_6F56_FLASH_ADDR (USIM0_EF_6FC4_FLASH_ADDR + FILE_SIZE_6FC4)
#define USIM0_EF_4F20_FLASH_ADDR (USIM0_EF_6F56_FLASH_ADDR + FILE_SIZE_6F56)
#define USIM0_EF_4F52_FLASH_ADDR (USIM0_EF_4F20_FLASH_ADDR + FILE_SIZE_4F20)
#define USIM0_EF_6F42_FLASH_ADDR (USIM0_EF_4F52_FLASH_ADDR + FILE_SIZE_4F52)
#define FLAG_USIM0_EF_2FE2_FLASH_ADDR (USIM0_EF_FLASH_ADDR + ALL_USIM_EF_SIZE + 1)
#define FLAG_USIM0_EF_2F05_FLASH_ADDR (FLAG_USIM0_EF_2FE2_FLASH_ADDR + 1)
#define FLAG_USIM0_EF_6F07_FLASH_ADDR (FLAG_USIM0_EF_2FE2_FLASH_ADDR + 2)
#define FLAG_USIM0_EF_6F08_FLASH_ADDR (FLAG_USIM0_EF_2FE2_FLASH_ADDR + 3)
#define FLAG_USIM0_EF_6F09_FLASH_ADDR (FLAG_USIM0_EF_2FE2_FLASH_ADDR + 4)
#define FLAG_USIM0_EF_6F31_FLASH_ADDR (FLAG_USIM0_EF_2FE2_FLASH_ADDR + 5)
#define FLAG_USIM0_EF_6F78_FLASH_ADDR (FLAG_USIM0_EF_2FE2_FLASH_ADDR + 6)
#define FLAG_USIM0_EF_6F7E_FLASH_ADDR (FLAG_USIM0_EF_2FE2_FLASH_ADDR + 7)
#define FLAG_USIM0_EF_6F73_FLASH_ADDR (FLAG_USIM0_EF_2FE2_FLASH_ADDR + 8)
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

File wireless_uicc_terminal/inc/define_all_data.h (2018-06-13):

/* --------------------------------------------------------------------------
Copyright (c) 2018, Jiacheng Wang
All rights reserved.

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
1. Redistributions of source code must retain the above copyright notice, this
   list of conditions and the following disclaimer.
2. Redistributions in binary form must reproduce the above copyright notice,
   this list of conditions and the following disclaimer in the documentation
   and/or other materials provided with the distribution.

THIS SOFTWARE IS PROVIDED BY THE COPYRIGHT HOLDERS AND CONTRIBUTORS "AS IS" AND
ANY EXPRESS OR IMPLIED WARRANTIES, INCLUDING, BUT NOT LIMITED TO, THE IMPLIED
WARRANTIES OF MERCHANTABILITY AND FITNESS FOR A PARTICULAR PURPOSE ARE
DISCLAIMED. IN NO EVENT SHALL THE COPYRIGHT OWNER OR CONTRIBUTORS BE LIABLE FOR
ANY DIRECT, INDIRECT, INCIDENTAL, SPECIAL, EXEMPLARY, OR CONSEQUENTIAL DAMAGES
(INCLUDING, BUT NOT LIMITED TO, PROCUREMENT OF SUBSTITUTE GOODS OR SERVICES;
LOSS OF USE, DATA, OR PROFITS; OR BUSINESS INTERRUPTION) HOWEVER CAUSED AND
ON ANY THEORY OF LIABILITY, WHETHER IN CONTRACT, STRICT LIABILITY, OR TORT
(INCLUDING NEGLIGENCE OR OTHERWISE) ARISING IN ANY WAY OUT OF THE USE OF THIS
SOFTWARE, EVEN IF ADVISED OF THE POSSIBILITY OF SUCH DAMAGE.
--------------------------------------------------------------------------- */
#ifndef DEFINES_ALL_H__
#define DEFINES_ALL_H__

/* ISR type for function SWI3_EGU3_IRQHandler() */
#define SWI3_EGU3_ISR_PHONE_COMMAND                                   1
#define SWI3_EGU3_ISR_USIM_SERVER_SIM_COMMAND_AUTHENTICATION_stage3   2
#define SWI3_EGU3_ISR_USIM_SERVER_WIRELESS_AUTHENTICATION_stage1      3
#define SWI3_EGU3_ISR_SIM_CARD_STATE_RESET                            4
#define SWI3_EGU3_ISR_STOP_BLE_STACK                                  5

/* phone command fetch (0x12) type */
#define FETCH_COMMAND_TYPE_NULL_VALUE                                         0
#define FETCH_COMMAND_TYPE_DISPLAY_TEXT_ABOUT                                 1
#define FETCH_COMMAND_TYPE_SMART_USIM_TRAY_DEVICE_NAME_TEXT_DISPLAY           2
#define FETCH_COMMAND_TYPE_LED_STATUS_SYNCH_SERVER_TEXT_DISPLAY               3
#define FETCH_COMMAND_TYPE_BLE_STATUS_ON_DISPLAY_TEXT_DISPLAY                 4
#define FETCH_COMMAND_TYPE_BLE_STATUS_OFF_DISPLAY_TEXT_DISPLAY                5
#define FETCH_COMMAND_TYPE_CONFIG_RESTORE_TEXT_DISPLAY                        6
#define FETCH_COMMAND_TYPE_WIRELESS_SIM_STATUS_ON_DISPLAY_TEXT_DISPLAY        7
#define FETCH_COMMAND_TYPE_WIRELESS_SIM_STATUS_OFF_DISPLAY_TEXT_DISPLAY       8
#define FETCH_COMMAND_TYPE_IDLE_TEXT_WIRELESS_USIM0_SIM_ON_SERVER             9
#define FETCH_COMMAND_TYPE_IDLE_TEXT_WIRELESS_USIM0_SIM_OFF_SERVER            10
#define FETCH_COMMAND_TYPE_IDLE_TEXT_WIRELESS_USIM1_SIM_ON_SERVER             11
#define FETCH_COMMAND_TYPE_IDLE_TEXT_WIRELESS_USIM1_SIM_OFF_SERVER            12
#define FETCH_COMMAND_TYPE_IDLE_TEXT_SIM_ON_USIM0_CONNECTED_CLIENT            13
#define FETCH_COMMAND_TYPE_IDLE_TEXT_SIM_ON_USIM1_CONNECTED_CLIENT            14
#define FETCH_COMMAND_TYPE_IDLE_TEXT_SIM_ON_USIM0_DISCONNECTED_CLIENT         15
#define FETCH_COMMAND_TYPE_IDLE_TEXT_SIM_ON_USIM1_DISCONNECTED_CLIENT         16
#define FETCH_COMMAND_TYPE_IDLE_TEXT_SIM_OFF_ADDRESS_CLIENT                   17
#define FETCH_COMMAND_TYPE_BLE_BOND_DELETE_TEXT_DISPLAY                       18
#define FETCH_COMMAND_TYPE_CONFIG_SYCH_TEXT_DISPLAY                           19
#define FETCH_COMMAND_TYPE_CONFIG_SYCH_TEXT_DISPLAY_CLIENT                    20
#define FETCH_COMMAND_TYPE_PASSWORD_INPUT_TEXT_DISPLAY                        21
#define FETCH_COMMAND_TYPE_SYSTEM_KEY_INPUT_TEXT_DISPLAY                      22
#define FETCH_COMMAND_TYPE_IDLE_TEXT_CONFIG_SYCH_SERVER                        23
#define FETCH_COMMAND_TYPE_USIM_SWITCH_WIRELESS_OFF_DISPLAY_TEXT              24
#define FETCH_COMMAND_TYPE_LED_PATTERN_UPDATED_TEXT_DISPLAY                   25
#define FETCH_COMMAND_TYPE_COMMAND_LINE_INPUT                                  26
#define FETCH_COMMAND_TYPE_CONFIG_SETTING_KEY_WORD_TEXT_DISPLAY               27
#define FETCH_COMMAND_TYPE_CONFIG_SETTINGS_KEY_WORD_LIST_TEXT_DISPLAY         28
#define FETCH_COMMAND_TYPE_LED_PATTERN_ERROR_TEXT_DISPLAY                     29
#define FETCH_COMMAND_TYPE_PASSWORD_ERROR_TEXT_DISPLAY                        30
#define FETCH_COMMAND_TYPE_SYSTEM_KEY_ERROR_TEXT_DISPLAY                      31
#define FETCH_COMMAND_TYPE_SMART_USIM_TRAY_DEVICE_NAME_ERROR_TEXT_DISPLAY     32
#define FETCH_COMMAND_TYPE_USIM0_EF_UPDATE_TEXT_DISPLAY                       33
#define FETCH_COMMAND_TYPE_USIM1_EF_UPDATE_TEXT_DISPLAY                       34
#define FETCH_COMMAND_TYPE_USIM_EF_UPDATE_ERROR_TEXT_DISPLAY                  35
#define FETCH_COMMAND_TYPE_WIRELESS_SIM_RESET_FETCH                           36
#define FETCH_COMMAND_TYPE_INITIAL_USAT_MENU_SETUP                            37
#define FETCH_COMMAND_TYPE_USIM_SWITCH_USIM0_YES_WIRELESS_DISPLAY_TEXT        38
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

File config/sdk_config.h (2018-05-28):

/**
 * Copyright (c) 2017 - 2017, Nordic Semiconductor ASA
 * 
 * All rights reserved.
 * 
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
 * 3. Neither the name of Nordic Semiconductor ASA nor the names of its
 *    contributors may be used to endorse or promote products derived from this
 *    software without specific prior written permission.
 * 
 * 4. This software, with or without modification, must only be used with a
 *    Nordic Semiconductor ASA integrated circuit.
 * 
 * 5. Any software provided in binary form under this license must not be reverse
 *    engineered, decompiled, modified and/or disassembled.
 * 
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
 */



#ifndef SDK_CONFIG_H
#define SDK_CONFIG_H
// <<< Use Configuration Wizard in Context Menu >>>\n
#ifdef USE_APP_CONFIG
#include "app_config.h"
#endif
// <h> Board Support 

//==========================================================
// <q> BSP_BTN_BLE_ENABLED  - bsp_btn_ble - Button Control for BLE
 

#ifndef BSP_BTN_BLE_ENABLED
#define BSP_BTN_BLE_ENABLED 0
#endif

// </h> 
//==========================================================

// <h> nRF_BLE 

//==========================================================
// <q> BLE_ADVERTISING_ENABLED  - ble_advertising - Advertising module
 

#ifndef BLE_ADVERTISING_ENABLED
#define BLE_ADVERTISING_ENABLED 1
#endif

// <q> BLE_DB_DISCOVERY_ENABLED  - ble_db_discovery - Database discovery module
 

#ifndef BLE_DB_DISCOVERY_ENABLED
#define BLE_DB_DISCOVERY_ENABLED 1
#endif

// <q> BLE_DTM_ENABLED  - ble_dtm - Module for testing RF/PHY using DTM commands
 

#ifndef BLE_DTM_ENABLED
#define BLE_DTM_ENABLED 0
#endif

// <q> BLE_RACP_ENABLED  - ble_racp - Record Access Control Point library
 

#ifndef BLE_RACP_ENABLED
#define BLE_RACP_ENABLED 0
#endif

// <e> NRF_BLE_CONN_PARAMS_ENABLED - ble_conn_params - Initiating and executing a connection parameters negotiation procedure
//==========================================================
#ifndef NRF_BLE_CONN_PARAMS_ENABLED
#define NRF_BLE_CONN_PARAMS_ENABLED 1
#endif
// <o> NRF_BLE_CONN_PARAMS_MAX_SLAVE_LATENCY_DEVIATION - The largest acceptable deviation in slave latency. 
// <i> The largest deviation (+ or -) from the requested slave latency that will not be renegotiated.

#ifndef NRF_BLE_CONN_PARAMS_MAX_SLAVE_LATENCY_DEVIATION
#define NRF_BLE_CONN_PARAMS_MAX_SLAVE_LATENCY_DEVIATION 499
#endif

// <o> NRF_BLE_CONN_PARAMS_MAX_SUPERVISION_TIMEOUT_DEVIATION - The largest acceptable deviation (in 10 ms units) in supervision timeout. 
// <i> The largest deviation (+ or -, in 10 ms units) from the requested supervision timeout that will not be renegotiated.

#ifndef NRF_BLE_CONN_PARAMS_MAX_SUPERVISION_TIMEOUT_DEVIATION
#define NRF_BLE_CONN_PARAMS_MAX_SUPERVISION_TIMEOUT_DEVIATION 65535
#endif

// </e>

// <q> NRF_BLE_GATT_ENABLED  - nrf_ble_gatt - GATT module
 

#ifndef NRF_BLE_GATT_ENABLED
#define NRF_BLE_GATT_ENABLED 1
#endif

// <q> NRF_BLE_QWR_ENABLED  - nrf_ble_qwr - Queued writes support module (prepare/execute write)
 

#ifndef NRF_BLE_QWR_ENABLED
#define NRF_BLE_QWR_ENABLED 0
#endif

// <e> PEER_MANAGER_ENABLED - peer_manager - Peer Manager
//==========================================================
#ifndef PEER_MANAGER_ENABLED
#define PEER_MANAGER_ENABLED 1
#endif
// <o> PM_MAX_REGISTRANTS  
// <i> Number of event handlers that can be registered.

#ifndef PM_MAX_REGISTRANTS
#define PM_MAX_REGISTRANTS 3
#endif

// <o> PM_FLASH_BUFFERS  
// <i> Number of internal buffers for flash operations.
// <i> Decrease this value to lower RAM usage.

#ifndef PM_FLASH_BUFFERS
#define PM_FLASH_BUFFERS 8
#endif

// </e>

// </h> 
//==========================================================

// <h> nRF_BLE_Services 

//==========================================================
// <q> BLE_ANCS_C_ENABLED  - ble_ancs_c - Apple Notification Service Client
 

#ifndef BLE_ANCS_C_ENABLED
#define BLE_ANCS_C_ENABLED 1
#endif

// <q> BLE_ANS_C_ENABLED  - ble_ans_c - Alert Notification Service Client
 

#ifndef BLE_ANS_C_ENABLED
#define BLE_ANS_C_ENABLED 0
#endif

// <q> BLE_BAS_C_ENABLED  - ble_bas_c - Battery Service Client
 

#ifndef BLE_BAS_C_ENABLED
#define BLE_BAS_C_ENABLED 0
#endif

// <q> BLE_BAS_ENABLED  - ble_bas - Battery Service
 

#ifndef BLE_BAS_ENABLED
#define BLE_BAS_ENABLED 0
#endif

// <q> BLE_CSCS_ENABLED  - ble_cscs - Cycling Speed and Cadence Service
 

#ifndef BLE_CSCS_ENABLED
#define BLE_CSCS_ENABLED 0
#endif

// <q> BLE_CTS_C_ENABLED  - ble_cts_c - Current Time Service Client
 

#ifndef BLE_CTS_C_ENABLED
#define BLE_CTS_C_ENABLED 0
#endif

// <q> BLE_DIS_ENABLED  - ble_dis - Device Information Service
 

#ifndef BLE_DIS_ENABLED
#define BLE_DIS_ENABLED 0
#endif

// <q> BLE_GLS_ENABLED  - ble_gls - Glucose Service
 

#ifndef BLE_GLS_ENABLED
#define BLE_GLS_ENABLED 0
#endif

// <q> BLE_HIDS_ENABLED  - ble_hids - Human Interface Device Service
 

#ifndef BLE_HIDS_ENABLED
#define BLE_HIDS_ENABLED 0
#endif

// <q> BLE_HRS_C_ENABLED  - ble_hrs_c - Heart Rate Service Client
 

#ifndef BLE_HRS_C_ENABLED
#define BLE_HRS_C_ENABLED 0
#endif
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

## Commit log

2018-01-28 dd some hardware files
    [wirelessSIM_HWwatch_20171211.igs, wirelessSIM_iPhone7_20171211.igs, wirelessSIM_iPhone8P_20171211.igs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]
2018-01-28 revise for LED flash mode '9'
    HEAD detached from v1.0
    Changes to be committed:
    modified: .gitignore
    modified: wireless_uicc_terminal/inc/define_config.h
    modified: wireless_uicc_terminal/src/comm_initial.c
    modified: wireless_uicc_terminal/src/wireless_sim_phone.c
2018-01-29 update for connection request link and convolutioan code, "#define IF_CONNECTION_CC_CODED 1" in define_config.h
    On branch work_branch
    modified: wireless_uicc_terminal/inc/define_all_data.h
    modified: wireless_uicc_terminal/src/time_slot.c
    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
2018-01-30 update connection request time slot and LED flash pattern
    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
2018-02-02 LED flash pattern change by BLE interface
    modified: wireless_uicc_terminal/inc/flash_file_address.h
    modified: wireless_uicc_terminal/inc/global_data_exchange.h
    modified: wireless_uicc_terminal/inc/global_data_exchange_extern.h
    modified: wireless_uicc_terminal/src/comm_phone_command.c
    modified: wireless_uicc_terminal/src/phone_command_sim.c
    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
2018-02-03 ufpate for flash pattern setting by BLE NUS
    modified: wireless_uicc_terminal/src/comm_wireless_interface.c
    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
2018-02-03 update for LED flash pattern by BLE interface
    modified: ble/sd_ble_ancs_nus.c
    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
2018-02-05 bug fix for LED flash pattern update
    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
    [comm_phone_command.c, define_all_data.h, flash_file_address.h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]
2018-02-06 tuning the time slot length
    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
2018-02-06 minor editorial update
    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
2018-02-08 update wireless-USIM connection request access procoss and time slot
    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
2018-03-01 wireless USIM interface parameters update
    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
2018-03-17 update to support 3GPP2 RUIM application card, just skip to update the EF data
    modified: wireless_uicc_terminal/inc/wireless_sim_phone.h
    modified: wireless_uicc_terminal/src/comm_uicc_terminal_interface.c
    modified: wireless_uicc_terminal/src/flash_data_write.c
    modified: wireless_uicc_terminal/src/phone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
    [comm_phone_command.c, comm_uicc_terminal_interface.c, comm_wireless_interface.c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]
2018-03-21 update for R-UIM (CT network)
    modified: wireless_uicc_terminal/src/usim_server_command_sim.c
    modified: wireless_uicc_terminal/src/usim_server_sim_interface.c
    modified: wireless_uicc_terminal/src/usim_server_wireless_interface.c
    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
2018-04-05 fixed ICCID data in EF 2fe2 can be updated and saved in flash
    modified: wireless_uicc_terminal/inc/comm_phone_command.h
    modified: wireless_uicc_terminal/src/usim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
    [comm_phone_command.c, define_all_data.h, define_config.h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]
2018-04-05 Remove all trailing whitespace in all source code
    modified: main.c
    modified: wireless_uicc_terminal/inc/comm_initial.h
    modified: wireless_uicc_terminal/inc/comm_uicc_terminal_interface.h
    modified: wireless_uicc_terminal/inc/comm_wireless_interface.h
    modified: wireless_uicc_terminal/inc/file_data_usim.h
    modified: wireless_uicc_terminal/inc/flash_data_write.h
    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
2018-04-30 1. add to restore user USIM data by chhecking the data in flash 2. remove directly return by phone command for 6f42
    modified: wireless_uicc_terminal/src/uart_printf.c
    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
2018-05-14 minor Config update
    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
2018-05-26 update function head comment message
    modified: wireless_uicc_terminal/inc/usim_server_wireless_interface.h
    modified: wireless_uicc_terminal/src/phone_wireless_interface.c
    modified: wireless_uicc_terminal/src/usim_server_command_sim.c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
2018-05-26 1. move hardware/ to doc/hardwear 2. add Wireless_SIM_Interface.ppt in doc/
    [wirelessSIM_HWwatch_20171211.igs, wirelessSIM_iPhone7_20171211.igs, wirelessSIM_iPhone8P_20171211.igs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]
2018-05-26 update doc "Wireless_USIM_interface.pptx" "
2018-08-25 update function phone_command_read_binary_0xb0() to fix the bug of input file_ID of phone_command_read_binary_file_data()
    [wireless_sim_phone.c]

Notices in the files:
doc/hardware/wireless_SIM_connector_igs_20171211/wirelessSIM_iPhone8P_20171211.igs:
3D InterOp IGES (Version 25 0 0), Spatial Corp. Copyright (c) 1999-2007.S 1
